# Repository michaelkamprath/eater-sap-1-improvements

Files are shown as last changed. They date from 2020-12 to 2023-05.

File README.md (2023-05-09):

Stand With Ukraine (https://stand-with-ukraine.pp.ua)

# Eater SAP-1 Improvements
Ben Eater released [a YouTube video series](https://eater.net/8bit) that works you through the process of building a simple 8-bit computer on a breadboard made with simple logic gates. It's a great learning experience if you are so interested.

Captured in this repository are various projects that extend and improve on the original SAP-1. The goal of these project is to build upon and reinforce what was learned with Ben Eater's original series.

Note that I've made a video explaining most of these projects. The video series [can be found here](https://www.youtube.com/playlist?list=PLC4jDTViU38EQzCYaRsoOLeGLLW5cMN4A).

# Projects
Multiple independent projects are described in this repository. It is recommended that you do them in the following order:

1. **[Halt system clock when programming](./clock-halt-when-programming/)** - Fixes the annoying issue that the SAP-1's microcode counter continues iterating when in program mode.
2. **[Making the 16 Byte RAM Module more reliable](./improving-reliability-of-ram-module/)** - Ben Eater's original design for the RAM module has two issues that cause the bread board computer to be unreliable. This project fixes those problems.
3. ~~**[Expanding the SAP-1 Control Logic](./expanded-control-logic/)**~~ - **It is recommended that this project be skipped in instead implement the control lines expansion describe in the Instruction Register project below**. The original SAP-1 can control at most 16 control lines in the computer. This project add more control lines that and sets the SAP-1 up for other future expansions.
4. **[Adding Two General Purpose Increment Registers to the SAP-1](./increment-registers/)** - This project adds to the SAP-1 two general purpose registers that have the ability to increment or decrement the value they contain.
5. **[Calculating Factorial](./calculating-factorial/)** - This project builds on everything done up to this point to enable the SAP-1 to calculating the _n!_ math algorithm.
6. ~~**[Adding 64K of RAM and ROM](./ram-rom-upgrade/)**~~ - **It is recommended that this project be partially skipped. The program counter, memory address register, and run mode selector from this project should be completed, but is recommended to skip the rest and implement the 16 bit memory architecture describe in the Instruction Register project below**. This project changes the SAP-1's memory address space to 16 bit, and then splits the address space between ROM and RAM. The original 4-bit instructions are still maintained, as that will be changed in a later project. This project also introduces an assembler to help build the ROM code.
7. **[Instruction Register and Memory Map Update](./instruction-register-8-bit/)** - In this project I upgrade the instruction register to use the full 8-bits. I also realized that I once again needed to upgrade my control logic, so I expanded the instruction-based control logic plus added a memory map mechanism.
8. **[Stack Pointer and Index Register](./stack-pointer/)** - A stack pointer is added to enable things like subroutines and stack memory. Also adds an index register that can be used to track 16-bit values and memory addresses.
9. **[LCD Display](./lcd-display/)** - A 20x4 LCD character display is added to give the TTL CPU the ability to display more complex output to the user than is afforded by the original 8-bit display of the SAP-1.
10. **[Advanced Arithmetic Logic Unit](./advanced-alu/)** - Adds an ALU that is more capable than just addition operations. In addition to addition  subtraction, enables bit shifting, logic operations, comparisons, and bit detection. Plus, allows reading the flags register directly.
11. **[Writable Flags Register](./bidirectional-flags-register/)** - Corrects a design oversight from the Advanced ALU design by allowing the Flags register to be written to from the data bus.

# Future Projects
The following projects are planned but have not been designed yet, however, I have put sufficient thought into them or have seen other attempt them to be convinced that they are viable:
* Adding a 8x8 LED pixel display
* Interfacing with the TMS9918a video processor (?)
* Interfacing with a 80's tech sound chip

# Interesting SAP-1 Links

* [SAP-1 Simulator](https://github.com/milen-patel/SAP-1)
* [Ben Eater Reddit forum](https://www.reddit.com/r/beneater/)

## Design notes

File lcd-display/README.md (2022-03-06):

# LCD Display Module
## Overview
As I iterate on the PUTEY-1 to expand its capabilities, the original 1-byte display of the Ben Eater SAP-1 just won't cut it anymore for my display needs. If I want to achieve 64-bit math on this computer, I will need a a way to display values greater than 8-bits. While eventually I do want to connect an 80's style video display processor to this computer, such as the [TMS9918A](https://en.wikipedia.org/wiki/Texas_Instruments_TMS9918), I felt the first step here would be to attach to the CPU one of those ubiquitous LCD displays based on [the Hitachi HD44780 controller](https://en.wikipedia.org/wiki/Hitachi_HD44780_LCD_controller). 

The work I did in a previous project to add memory mapped IO to the CPU really made this project pretty straight forward. There ended up being some gotchas around stability, which I discuss below, but from design to implementation, this was a pretty simple project. More work was put into designing the demonstration software than creating the hardware. But I am pretty happy with the results.

# Design

## LCD Module

### Overview
The LCD module I went with is the LCD2004 module with 4 rows of 20 characters. [These are pretty cheap on eBay](https://ebay.us/opX5g1). You will find many different manufacturers of these modules, but their electrical characteristics are all the same (if they are using the Hitachi HD44780 controller). Your biggest choices are price and color. 

The data sheets for these modules highlight the standard pin connections to the modules, which I list here:

| Pin | Symbol | Description |
|:-:|:-:|:--|
| 1 | `VSS` | **Ground** - Power supply for the device logic. |
| 2 | `VDD` | **+5V** - Power supply for the device logic. |
| 3 | `V0` | **Voltage Reference** - used to adjust LCD brightness. |
| 4 | `RS` | **Register Select** - controls whether the data register (`HIGH`) or the instruction register (`LOW`) is being communicated with.|
| 5 | `R/W` | **Read/Write** - controls whether the device is accepting input (write mode `LOW`) and sending output (read mode `HIGH`) |
| 6 | `E` | **Enable** - In write mode the module will latch the contents of the data lines on the falling edge of this line. In read mode the module will present data to be read on the rising edge of this line. |
| 7 | `DB0` | **Data Bus 0** |
| 8 | `DB1` | **Data Bus 1** |
| 9 | `DB2` | **Data Bus 2** |
| 10 | `DB3` | **Data Bus 3** |
| 11 | `DB4` | **Data Bus 4** |
| 12 | `DB5` | **Data Bus 5** |
| 13 | `DB6` | **Data Bus 6** |
| 14 | `DB7` | **Data Bus 7** |
| 15 | `LED+` | **+5V** - Power supply for the backlight. |
| 16 | `LED-` | **Ground** - Power supply for the backlight. |

### Interfacing with the LCD Module
The register select `RS` line into the LCD module controls whether we are interacting with the command or data register of the module. Prior to me implementing the memory mapped IO controller, the answer here might have been to create a new control line that would be controlled via microcode. That, of course, is an approach that doesn't scale where and the reason why I added [the memory mapped IO controller](../instruction-register-8-bit#memory-map). The basic idea is that we will use a memory mapped IO controller control line, `MMAP_x`, in combination with the lowest address lines to determine which device and register of that device is actively being used. In the case of the LCD module, I decided to assign it to the `MMAP_1` memory map control line and use address line `A0` to control the `RS` line directly. The `MMAP_1` control line is active for addresses between `0x7810` and `0x781F`. By connecting `A0` to `RS`, that means even addresses in that range will cause `RS` to be `LOW` and thus we would be interacting with the instruction register, and odd addresses would activate the data register. For simplicity, I just declare the address `0x7810` to be the instruction register, and `0x7811` is the data register. 

The `R/W` line of the LCD module is controlled by both the `MDi` (memory device in) and `MDo` (memory device out) control lines. When `MDi` is `HIGH` and `MMAP_1` is active, we want `R/W` to indicate that the device will be written to, or set `LOW`. And when `MDo` is `HIGH`, we want `R/W` to be set high. Furthermore, in order to prevent spurious data changes, I wanted to hold `R/W` in read mode whenever `MMAP_1` or both `MDi` and `MDo` are not active. This way any stray pulse into the device on another control line won't cause an unwanted write. To accomplish this, I introduced some logic to the design, which can be reviewed in the schematic.

The biggest challenge in using this module is dealing with the enable `E` behavior of acting on the falling edge of the clock for writes and the rising edge of the clock for reads. This would imply that we need an inverted clock driving the `E` signal, but care had to be taken in the design to deliver both edges *after* all the other control lines were configured. Since the other control lines would be driven by the memory map IO logic, there is relatively significant gate delay before the `RS` and `R/W` signals arrive. To account for this, I gate the inverted clock sign with the logical combination of `MMAP_1 AND (MDi OR MDo)`, which will allow the clock to pass only if both the memory map IO controller has activated the LCD module and the is either a memory write or read operation happening. After that gate, I pass the clock signal through a double inverter to delay it a bit more to ensure these is some time in between when the LCD module is configured and when it sees a rising edge on `E`. I also found in practice the Hitachi HD44780 is extremely sensitive to noise on the `E` line. I discuss noise mitigation later in this document.

Since the LCD module's data lines, `DB0` through `DB7`, can both read and write data, they cannot be connected to the CPU's data bus directly. An connection is needed that will architrave when the device is in read more and write mode in order to prevent contention on the bus. This is where the oft-used `74LS245` octal bus transceiver ready shines. It has the `DIR` line (pin 1) which controls the direction of the transceiver's signal repeating. Here, the `MDo` control line is used to drive the direction of the transceiver. Furthermore, the transceiver is only made active (chip enable line) when both the `MMAP_1` line and either of the `MDo` or the `MDi` line is active.

## Software Support
### Implementing a Vertical Scroll
The LCD2004 module is pretty rudimentary and its only "convenience" function is auto-incrementing the its active memory address when it is read or written to. So to write the contents of a particular row on the device you just have to set its data address to the row's start position and then bang out each o the row's character's in order. However, if you want to do something more sophisticated, such as creating a vertically scrolling display, you have to implement it in software.

So I did desire a vertically scrolling display. What I wanted for an interface is to simply give the module a line of text, and it would automatically display it on the bottom row after scrolling the existing rows upward. It is conceptually pretty straight forward to scroll, just read the contents of one from for the LCD module, and then write those contents to the line above. In practice, I found this to be slow given all the instructions that are needed to set the read and write address of the LCD module for moving the data around. This is actually not an uncommon problem with displays in general.

One way to improve the permanence of managing what is being displayed on a display is to buffer the display data in RAM, do any manipulations you want to do with the display data there in RAM (which is usually much faster than interacting with the display), and then when ready, simply blast the RAM display data into the the display module. This "download display data to the module" activity is usually optimized for speed in display modules, and this LCD2004 module is no different. 

Once I have the display module's display contents in RAM, effecting a fast vertical scroll becomes much easier. The method I used was to first create a single block of RAM that represents all of the specific character data positions on the display. The first position in this RAM block would represent the first position (left most) on the first (top) row, and the last position in this RAM block would be the last position (rightmost) on the last (bottom) row. Then, I additionally create four pointer variables in RAM that each have the address to the start of their specific row in the display data in RAM. This can be visualized like this:

```

                     0      Columns     19
                    +--------------------+
  row 0 pointer --> |                    |
                    +--------------------+ R
  row 1 pointer --> |                    | o
                    +--------------------+ w
  row 2 pointer --> |                    | s
                    +--------------------+
  row 3 pointer --> |                    |
                    +--------------------+
                                        79

```

When I want to updated the contents of a row, I simply write into the RAM block starting at the memory address contained by the pointer variable to that row. Then when I need to update the contents of a row on the LCD module, I set the LCD module's data address to its address for that particular row, then send it 20 characters from the RAM block starting at the address contained by the pointer variable for that row. 

Effecting a fast scroll then becomes pretty simple. I first rotate the pointers variables. That is, the row 0 pointer assigned the address that is currently in the row 1 pointer, the row 1 pointer gets the row 2 pointer value, the row 2 pointers gets row 3 pointer value, and and row 3 pointer gets the original value of the row 0 pointer. Then I write the new string data that I want to display to the updated memory location in the row 3 pointer. The updated pointer configuration after the first scroll would look like this relative to the buffer RAM block:

```

                     0      Columns     19
                    +--------------------+
  row 3 pointer --> |                    |
                    +--------------------+ R
  row 0 pointer --> |                    | o
                    +--------------------+ w
  row 1 pointer --> |                    | s
                    +--------------------+
  row 2 pointer --> |                    |
                    +--------------------+
                                        79

```
At this point, the LCD module display can be quickly updated by blasting the entire buffer contents into the LCD module one row at a time starting at the address of the updated row 0 pointer and then working through each subsequent row in turn. 

The advantage of this approach is that you have to move less data around to effect the vertical scroll. Since the LCD module does not support a hardware scroll, you can't get around needing to completely update the LCD module's RAM content. However, this row pointer approach allows you to effectively rearrange the buffer's row arrangement without needing to read and rewrite the contents of the buffer. 

### Standard Libraries
With the addition of a stack pointer in my last update, and the addition of the LCD module in this update, its time to start implementing a standard suite of functions for use to build software for the PUTEY-1 TTL CPU. With this project, I created the start of the following libraries:

* `memlib` : **Memory Library** - Provides some utilities around managing emory, notably copying data from one area in ROM or RAM to another.
* `stringlib` : **String Library** - Provides functions for the manipulation of strings, notably determining their length, concatenating two strings, and converting numeric values to a string for display. This library primarily uses null-terminated strings, also known as C-style strings. 
* `mathlib` : **Math Library** - Provides functions for calculating math at high bit sizes than the 8-bit math the the ALU supports. Currently provides an addition, subtraction, multiplication, and division function for 16-bit math.
* `lcdlib` : **LCD Display Library** - Provides all the of the functions needed to display text and special characters on the LCD2004 module.

The current version of these libraries can be found in [the examples folder](./examples/) of this project. These libraries can be used in the code independently, or all can be imported by [including](https://github.com/michaelkamprath/bespokeasm/wiki/Assembly-Language-Syntax#include-other-files) the `system.asm` file in your program's code.

## Increasing Maximum Clock Speed
At the start of this project, I was still using the original clock design from [Ben Eater's SAP-1](https://eater.net/8bit). As it was designed the maximum speed of the clock is 481 Hz. Certainly that is faster than what you eye can see, but it proved to be pretty slow with all the work that needs to happen to maintain the LCD display. A quick fix here was to change the capacitor that controls the timing of the astable `555`. In Ben Eater's original design, this capacitor was 1 µF. I changed it to a 100 nF capacity and got a 10x increase in the maximum speed of the clock, to 4.8 KHz. This made the display of text and scrolling on the LCD module much more snappy.

## Stability Issues
While the basic concept of adding this LCD module to the breadboard CPU are pretty straightforward, there is a rather significant stability issues I had to solve. The issue was a combination of the LCD Module's enable line being sensitive to triggering on the falling and and general signal integrity issues caused by the growing size of my breadboard CPU. Basically, noise in both the `CLK` and `MDi` lines would separately have noisy (enough) transitions between `LOW` and `HIGH` that the LCD module would see multiple falling edges. This noise is caused by the inductance of long wires in my large breadboard layout. In the case of `MDi`, I route it through the power rail bus in the middle of the breadboard layout along side the data bus. That's nearly a half meter of breadboard power rail. The falling edge of the `MDi` signal had a very distinct "second hump" as current from the collapsing magnetic field around the `MDi` bus rails created a second voltage spike.  The LCD module would see this as a second trigger when reading in data. 

To address the noise on the `MDi` trailing edge, I simply placed a 1 nF capacity between the `MDi` bus rail (where most the inductance is) and ground. This create a small [LC circuit](https://en.wikipedia.org/wiki/LC_circuit) based on the inductance (`L`) of the bus rail and capacitance (`C`) of the added capacitor. Th `LC` circuit smooths out the transition from `HIGH` to `LOW` (and vice versa) in the `MDi` line, but it does have the effect of lengthening the transition time. I measured the transition with an oscilloscope and found it now takes about 140 nanoseconds. This means that my breadboard computer now has a maximum frequency of about 7 MHz. I'm currently running PUTEY-1 at about 4 KHz, so I find that margin acceptable. I also found I needed to add a 1 pF capacitor to the `MDo` control line for all the same reasons. 

A similar problem was found in the `MMAP_1` memory map control line. A limitted investigation leads me to suspect the `74HCT238` creates a spurious signal spike as its address lines transition. This this spike was small, the LCD module would detect and act on it. I found that placing a 22 pF capacitor between the `MMAP_1` line and ground dampened the spike enough to not be detected by the LCD module.

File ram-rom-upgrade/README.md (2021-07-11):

# 16 Bit Memory Expansion for SAP-1
## Overview
When doing [my last project](../calculating-factorial/) with my Ben Eater inspired breadboard TTL CPU, one thing that became obvious is that 16 bytes was a rather small amount of RAM. If I wanted to continue my learning journey that only started when I finished the [Ben Eater SAP-1 project](https://eater.net/8bit), I needed to expand the available memory to my breadboard CPU. Furthermore, needing to manually key in a program each time I power cycle the breadboard CPU got old rather quick. So, before I go any further with expanding the breadboard TTL CPU, I need to address these two issues.

Something that surprised me in the effort to expand the RAM of the breadboard computer was the realization that I had a large number of choices and that each choice would have implications on what I could do later down the road. I idea I immediately seized on was to go with 12 bit addressing, effectively using the lower 4 bits of the instruction codes for the top 4 bits of an address, and then use the next byte after that for the lower 8 bits of the address. This appeared to be the most minimal departure from Ben Eater's original design, but it had the issue that I'd still be bound by 4 bit instruction codes. 

Then the debate was should I expand the instruction code bits to 6, and then use 10 bit addressing. This would get me 1K of RAM, which for the learning purposes of the breadboard CPU, seemed sufficient. However, the issues here is that 10 bits would just be an awkward size when it comes to the program counter, memory address register, and so on. 

So, I just bit the bullet and decided to go with full 16 bit memory addressing. Selecting this choice leads to some necessities in the design, specifically the creation of an address bus and defining how that will behave, but that was all OK because it forced me to really think about the design, which in the end is the goal of this project anyway: learning by doing. 

### Design Goals

* The memory space should use 16 bit addressing
* Have both ROM and RAM in the memory address space.
  * ROM would be used for a boot-loader, common subroutines, and programs
  * 32K of ROM and 32K of RAM. The ROM will be `0x0000` though `0x7FFF`, and the RAM will be at `0x8000` through `0xFFFF`.
* Both the program counter and memory address register should be 16 bit registers.
* Like the program counter, The memory address register should enable being incremented in order to quickly get the next location in memory. 
  * This feature is actually needed due to memory address values now occupying two bytes, and we want our instruction parameters to just point at the first byte.
 * This would be controlled by microcode.
* For multi-byte values in RAM, such as memory addresses and 16-bit integers, the values will be arranged as little endian.
  * This makes implementing multi-byte math so much easier later on. It does make data entry a little less intuitive. 
  * The program counter and memory address register will be physically arranged as big endian to make the LEDs used to represent their values more human interpretable.
* Implement an assembler similar to [the `customasm` tool](https://github.com/hlorenzi/customasm).
  * This is done to make creating the ROM images easier. 
* Smaller clock footprint
  * This project a larger than normal breadboard footprint. In order to save save, the clock module is made smaller by using a LM556 dual timer chip in replacement to two LM555 timers.  
  * Also, the sense of the `PROG` signal is changed to a HIGH indicating that the computer should be in manual program mode. This requires a small change to the [Halt system clock when programming](../clock-halt-when-programming/) project.

Not in scope for this project:

* While expanding the RAM and how it is addressed is the necessary prerequisite to allowing the instruction register use more than 4 bits for instruction codes, this project will not accomplish instruction register expansion. 

## Design Approach

### RAM and ROM
With a 16 bit address space, the computer will be able to address a total of 64K of memory. There are many ways to allocate the memory space's usage. Here, we are going to simply evenly split the memory space between ROM and RAM, with the ROM being in the lower 32K of the address space. Both the ROM and RAM could be used for program code, with the ROM code being burned onto the ROM and the RAM code being manually entered via DIP switches. Since only RAM will be mutable at run time, all variables for any cod should be in the RAM address space even if the program code is in ROM. 

A simple visualization of memory space is as follows:

```
    0xFFFF  +-----+
            |     |
            | RAM | <-- Variables, programs
            |     |
    0x8000  +-----+
            |     |
            | ROM | <-- Boot code, programs
            |     |
    0x0000  +-----+

```

To implement this, a 28C256 EEPROM will be used for the ROM and a UM61512AK-15 will be used for RAM. In order to select whether the RAM or ROM is active, address line 16 (the MSB) will be routed to each chip's enable rather than an address input on the chip. Fortunately, the 28C256 chip enable is active low and the UM61512AK-15 chip enable is active high, thus making it very straightforward as to which chip should be active based on the MSB of the address. 

One design challenge that had to be overcome is that the UM61512AK-15 uses the same pin for both data input and data output. This creates the potential for bus contention if the RAM is outputting a value at the moment a value is read in from the data bus. Bus contention could also occur if the 74LS157 2-to-2 multiplexers are used to switch between input from the DIP switches and input from the data bus. The reason for this is that when inactive, the 74LS157's output pins are set to LOW. This creates a short circuit if the RAM or ROM chip are writing a HIGH to any data line. In order to address these issues, 74LS257 2-to-1 multiplexers are used instead, as these chips have a tri-state output and places the output lines to high impedance if the chip is set to inactive. Then, logic is added to ensure that the 74LS257s are only active when the RAM chip is reading from the data lines. Otherwise, the 74LS257s will be set inactive so bus contention does not develop when either the RAM or ROM are writing to the data lines.

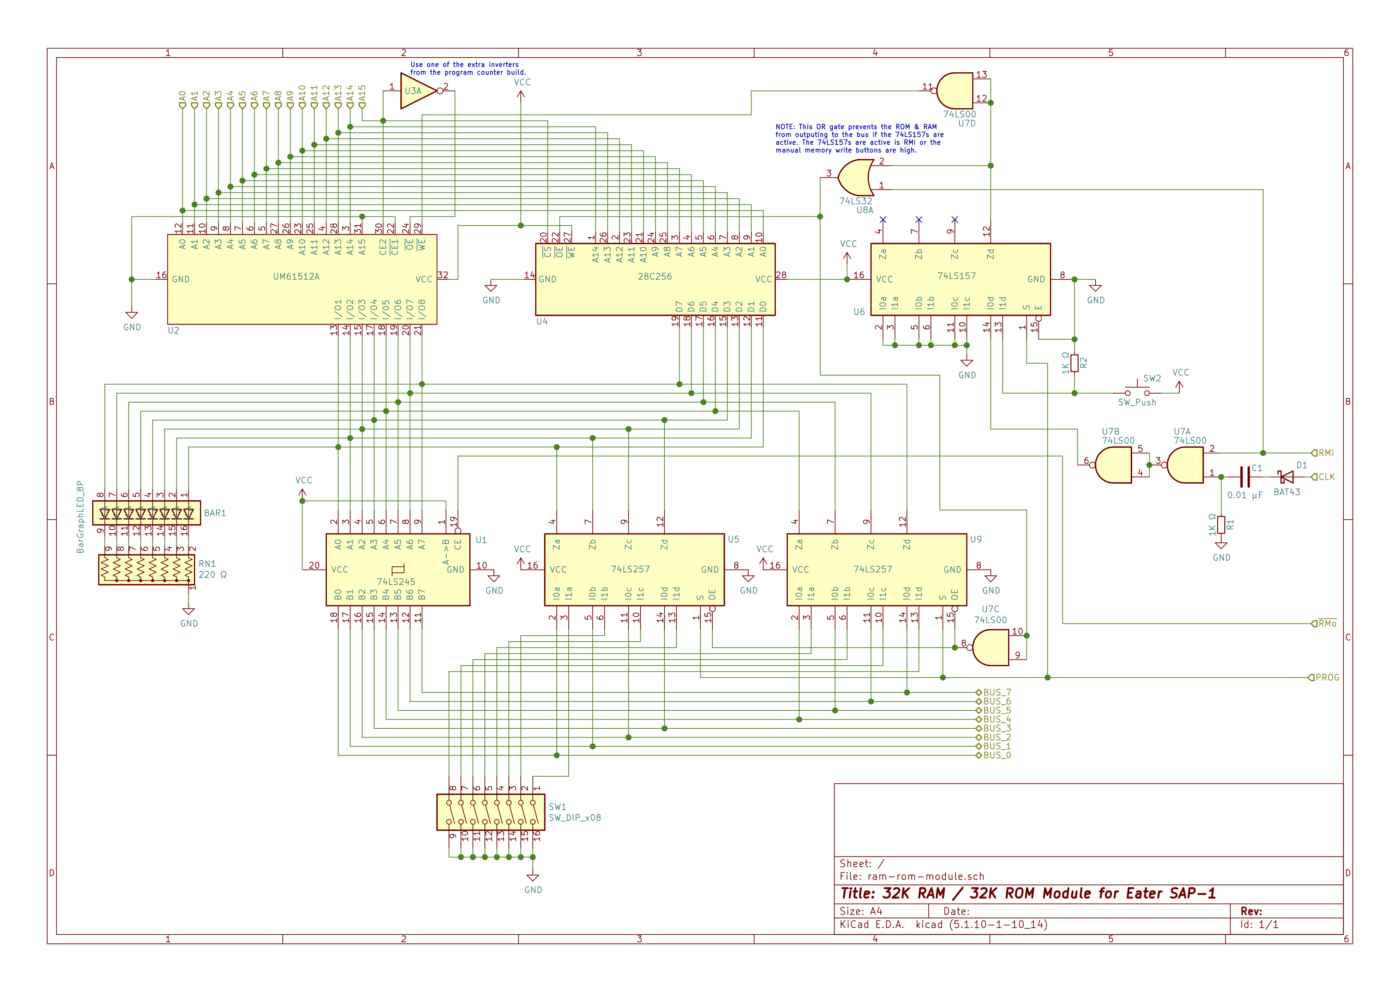
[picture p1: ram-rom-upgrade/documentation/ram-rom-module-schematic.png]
16-bit RAM/ROM Module


### Program Counter
Since this memory module has a 16 bit address space and I wish to make all of it available to code, the program counter itself needs to be a 16 bit counter. This is accomplished by using four 74LS161 4-bit counters. The design is similar to the original Eater SAP-1 program counter, but with four counters rather than one.

Another difference is in how the program counter reads in data from the data bus for the purpose of jump instructions. Since the program counter is 16 bit and the data bus is 8 bit, setting the program counter value from the data bus requires two read operations. To signal this, a `PCi` signal is used to indicate that the program counter should read in from the bus, and a `HILO` signal is used to indicate whether the bus value should be placed into the high byte or low byte of the program counter. The `HILO` signal is in fact reused through out the breadboard computer's design to generally indicate whether the operation pertains to the high or low byte of a 16-bit word. 

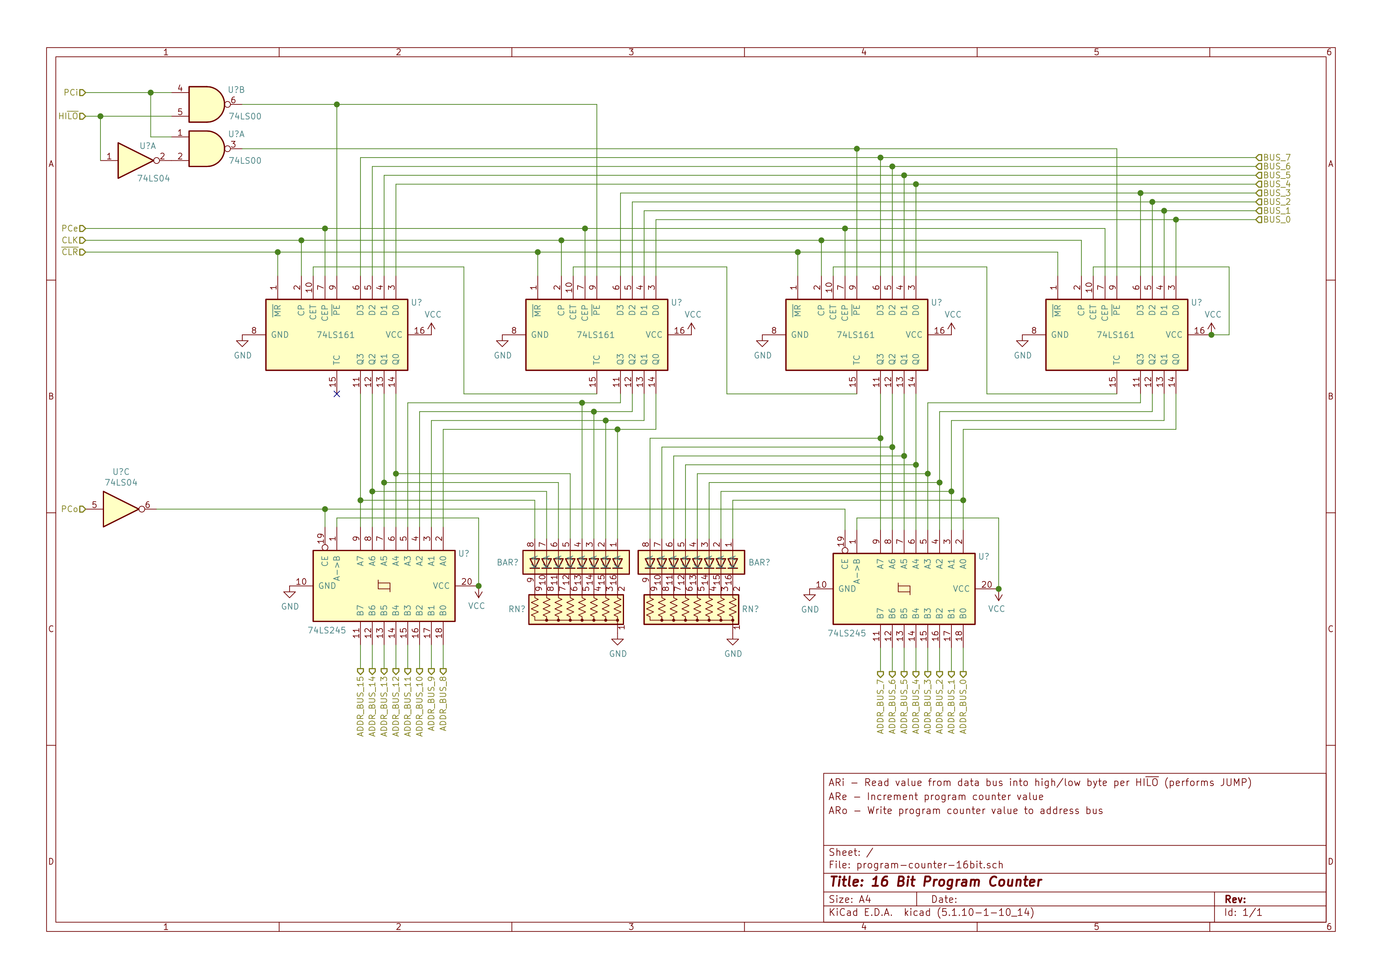
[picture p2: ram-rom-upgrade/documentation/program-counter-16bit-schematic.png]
16-bit Program Counter


### Memory Address Register
In this design, the memory address register is used to load address values from the data bus and then use them to indicate what address in memory should be read. Now that memory addresses themselves are multi-byte values, it is expected that we will increasingly want to read multiple consecutive bytes of data from memory. Given that, it would be convenient if the memory address register could increment itself rather than requiring an ALU operating simply to add 1 to the current memory address. to accomplish that, the memory address used 74LS161 4-bit counters similar to the program counter. In fact, the general design of the memory address register and the program counter are identical. 

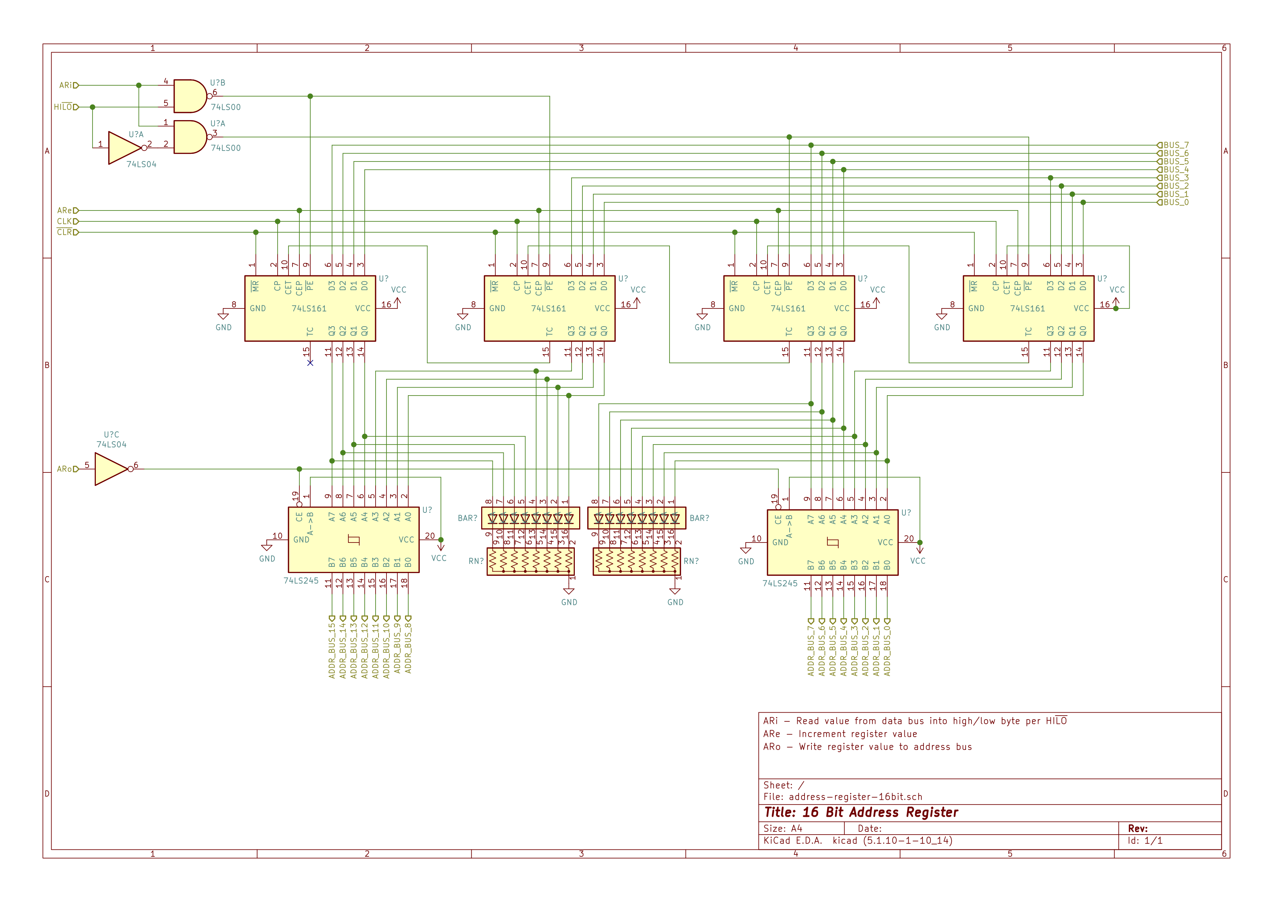
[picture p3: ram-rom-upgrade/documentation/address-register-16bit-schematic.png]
16-bit Memory Address Register


### Address Bus

In the original Eater SAP-1 design, the memory address register is the interface for anything that wants to fetch a value from memory. The program counter could set the memory address register, and so could the instruction register. All of this was done through the data bus. However, in a 16 bit address space with a 8 bit address bus, this design is problematic. 

The nature of the problem is due to memory addresses now requiring two bytes. Consider the `LDA` instruction. With a 16 bit address, the `LDA` instruction will be represented in 3 bytes. The first byte is the instruction code, and the next two bytes are the memory address of the value that should be loaded into register A. The problem arises in that loading the address into the memory address register is a two step operation. The following steps for the `LDA` instruction illustrates the problem:

1. The program counter points at the instruction code for the `LDA` instruction. This address is loaded into the memory address register, and then the memory value is loaded into the instruction register.
2. The program counter is incremented to now point at the first byte of the address of the value to be loaded into register A. This address is loaded into the memory address register, and the first byte of the value address is written onto the data bus and back into the low byte of the memory address register (remember, we are using a little endian design). 
3. The program counter is incremented again to point at the second byte of the address of the value to be loaded into register A. However, if we write this address to the memory address register to be able to fetch the value, it would overwrite the first byte of this value's address that was placed in the memory address register in step 2.  

Therein lies the problem of continuing with the SAP-1 of the memory address register being the only entity that can set the address that memory will fetch from. To solve this problem, we introduce an address bus concept to the design. The basic approach to this design is that multiple entities can write to the address bus, but only one at a time. The memory will fetch the value at whatever address is currently being written to the address bus, and then write that value to the data bus. This means that both the program counter and memory address register can both write to the address bus, but obviously they should not do so at the same time. 74LS245 bus transceivers are used to arbitrate which register is writing to the address bus. 

Added to the address bus design is a way to output the address bus value to the data bus. This feature would enable performing arithmetic on the address value beyond the simple increments that the program counter and the memory address register currently enable. 

Finally the address bus's connection to the address lines of the memory ICs is arbitrated by a set of 74LS157 2-to-1 multiplexers. This design enables a run mode switch, which indicates whether the memory address should be read from the address bus or a set of microswitches that are used when manually keying memory values. 

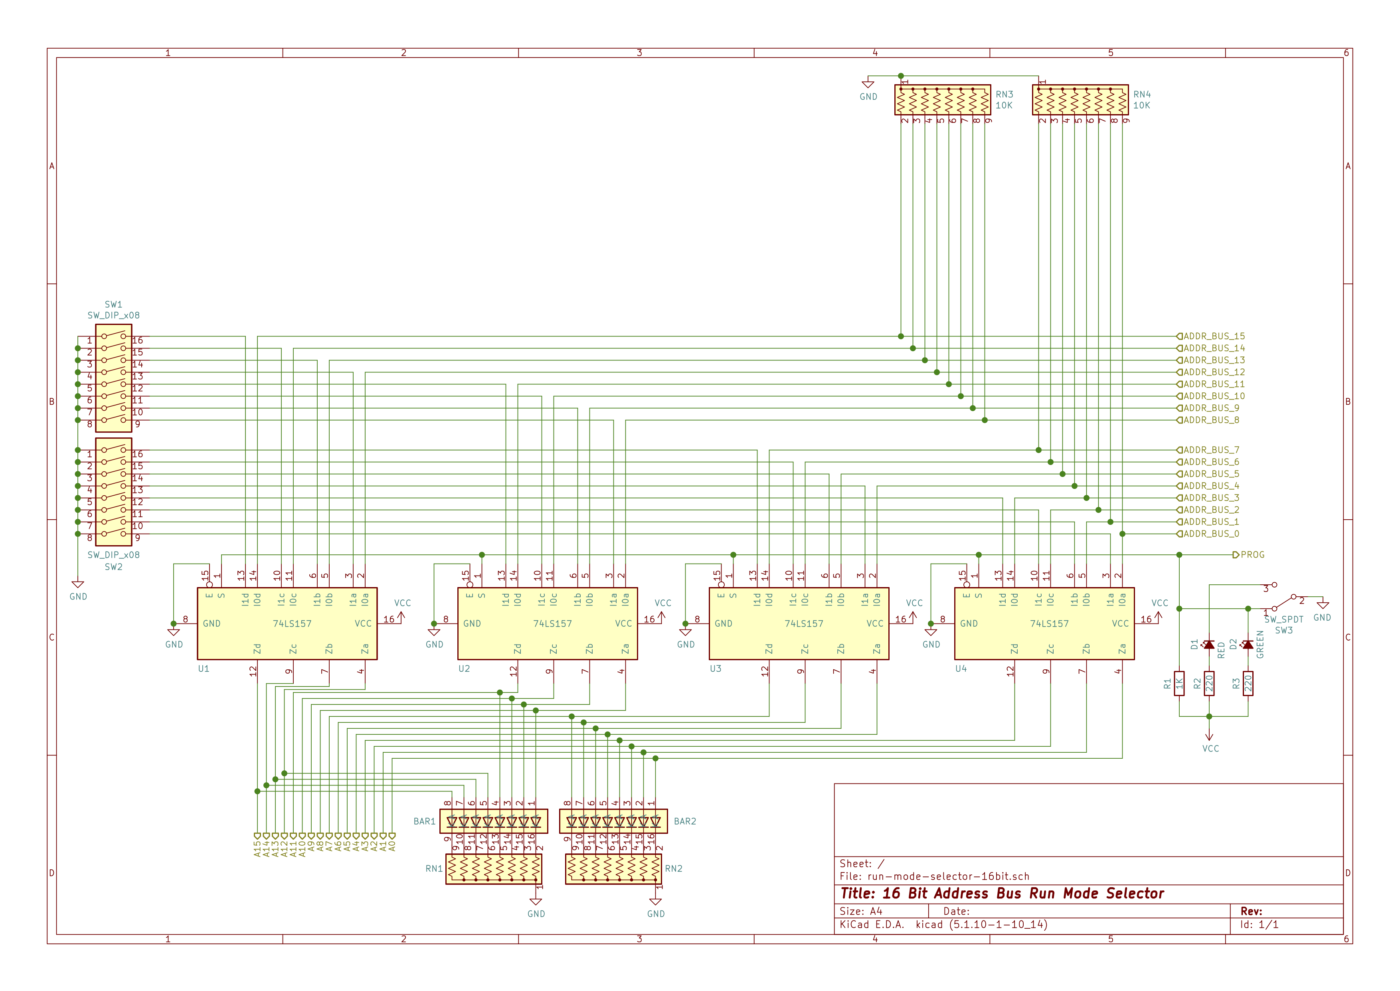
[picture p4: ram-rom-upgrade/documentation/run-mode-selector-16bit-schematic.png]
Run Mode Selector


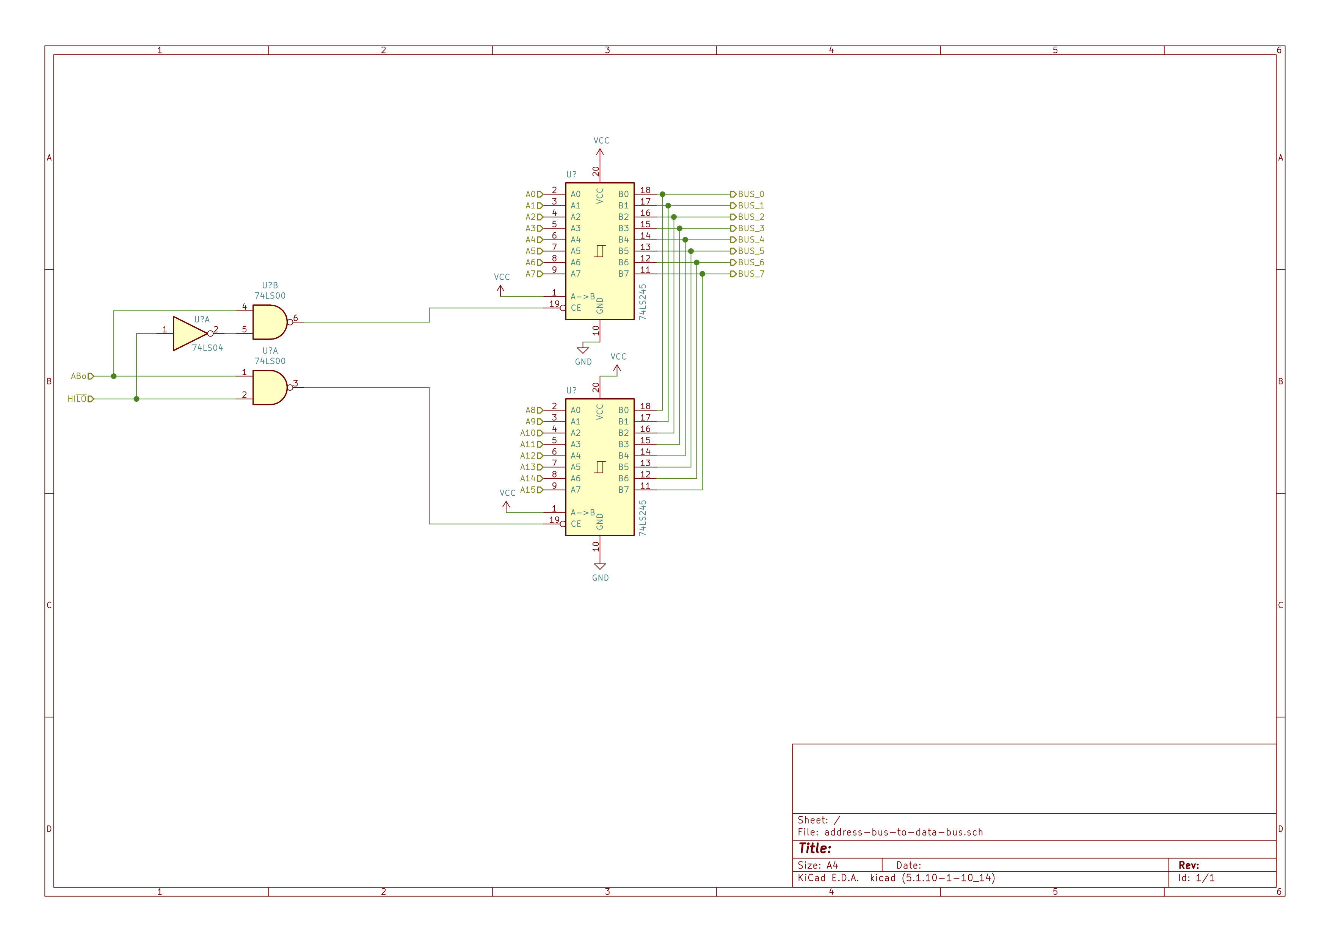
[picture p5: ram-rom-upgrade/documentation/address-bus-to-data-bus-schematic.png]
Address Bus to Data Bus


### Compact System Clock
Purely for layout reasons, the system clock was redesigned to slightly reduce chip count and in turn fit within a smaller footprint on the breadboard. This was done because the combination of the memory module, program counter, and memory address register require much more breadboard footprint than the previous RAM design did. Instead of using three 555 timers, the system clock now uses one 555 timer and one 556 dual timer. Other than that, the clock design is functionally the same. 

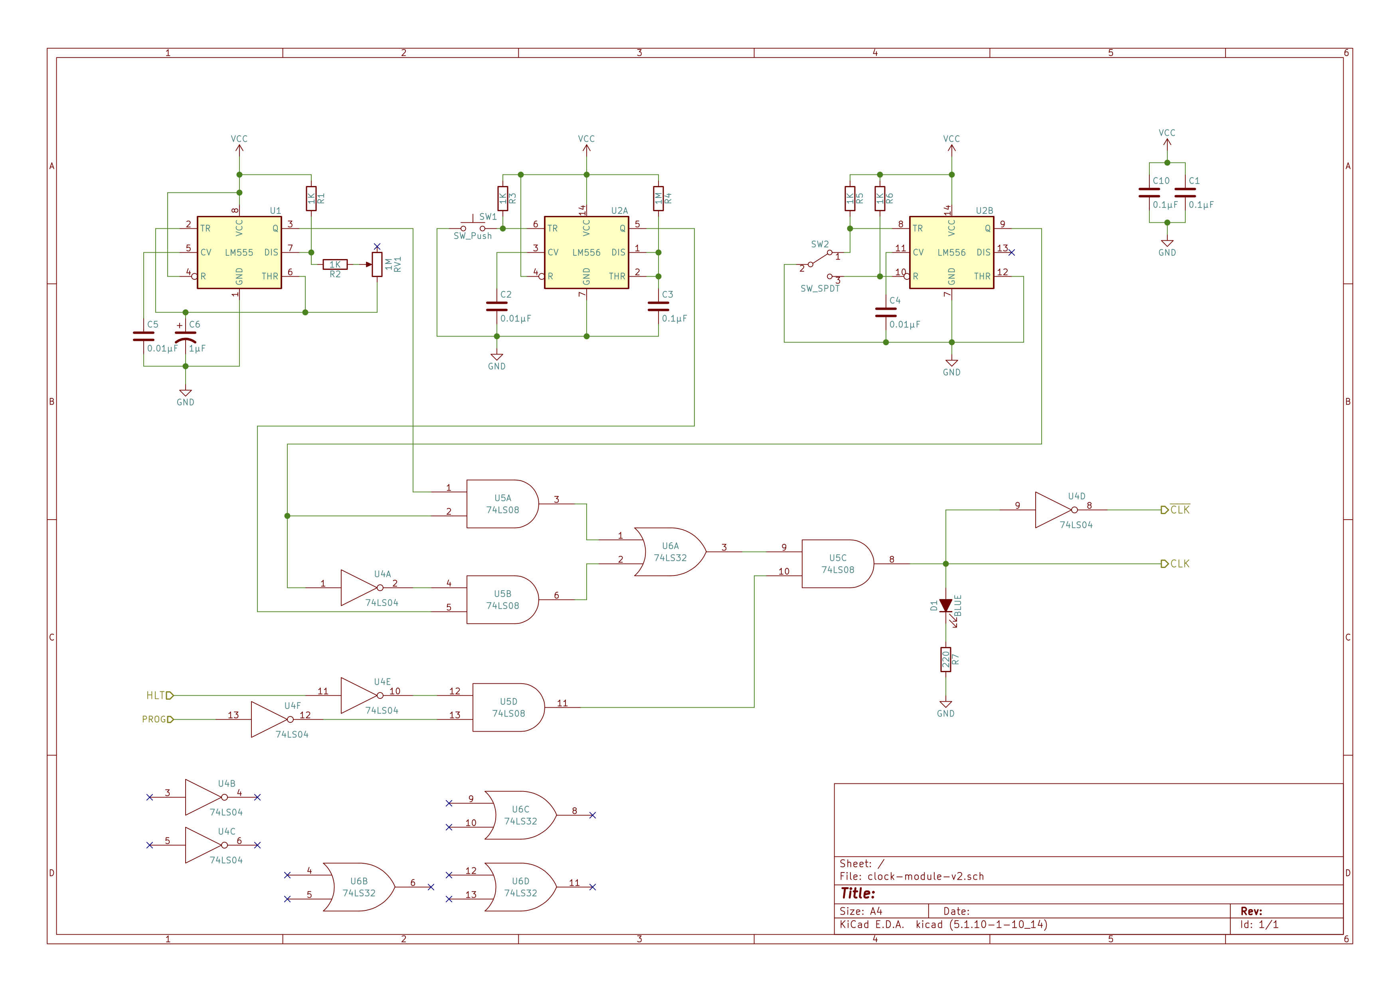
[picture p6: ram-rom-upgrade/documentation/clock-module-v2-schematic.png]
Compact Clock Module


## Component Data sheets

* [UM61512AK-15](./datasheets/UM61512A.pdf) - 64 K x 8 bit SRAM. Any 32K or larger SRAM chip could be used for this project with minimal modifications. 
* [AT28C256](https://www.mouser.com/datasheet/2/268/doc0006-1108095.pdf) - 32K x 8 bit EEPROM. Any 32K or larger EPROM could be used with minimal modification to the wiring. EEPROMs are convenient for reprogramming, which we will likely do often.
* [74LS161](https://www.ti.com/lit/ds/symlink/sn54ls161a-sp.pdf) - A 4-bit counter
* [74LS245](https://www.ti.com/lit/ds/symlink/sn54ls245-sp.pdf) - Octal Bus Transceivers With 3-State Outputs
* [74LS00](https://www.ti.com/lit/ds/symlink/sn74ls00.pdf) - Quadruple 2-Input NAND Gates
* [74LS04](https://www.ti.com/lit/ds/symlink/sn74ls04.pdf) - Hex Inverters
* [74LS32](https://www.ti.com/lit/ds/symlink/sn74ls32.pdf) - Quadruple 2-input OR gates
* [74LS157](https://www.ti.com/lit/ds/symlink/sn74ls157.pdf) - Quadruple 2-to-1 Line Data Selector/Multiplexer
* [74LS257](https://www.ti.com/lit/ds/symlink/sn74ls257b.pdf) - Quadruple 2-to-1 Line Data Selector/Multiplexer with Tristate Output
* [555](https://www.ti.com/lit/ds/symlink/lm555.pdf) - LM555 Timer
* [556](https://www.jameco.com/Jameco/Products/ProdDS/24328.pdf) - LM556 Dual Timer

## Integration with Breadboard Computer

### Breadboard Layout

### Connecting to Control Logic
At this point in the breadboard CPU's evolution away from the original Eater SAP-1 design, the following control lines are in use. Some control lines are marked as **New** or **Updated** in comparison to the previous [Increment Registers](../increment-registers/) project.

| Symbol | Title | Description |
|:-:|:--|:--|
| `SCr` | Step Counter Reset | Resets the microcode step counter to zero. |
| `PCe` | Program Counter Enable | Increments the current value in the Program Counter |
| `SUB` | Subtract | Signals that math operations should be subtraction |
|`HILO` | High/Low Byte Selector | Controls which byte of a 16 bit register is being operated on when interacting with 8-bit data bus. **New** |
| `HLT` | Halt | Stops the system clock. |
| `OUT` | Output Data Bus | Writes data bus value to the display register |
| `Ie` | I-Register Enable | Increments the value in the I register, or decrements is `SUB` is set |
| `Je` | J-Register Enable | Increments the value in the J register, or decrements is `SUB` is set |
| `ARe` | Address Register Enable | Increments the current value in the Address Register. **New**|
| `PCi` | Program Counter In | Renamed `J` control line, which sets the program counter to the data bus value. Used in conjunction with `HILO`. **Updated** |
| `∑f` | ALU Flags | Load flags register with current flags from ALU |
| `If` | I Register Flags | Load flags register with current flags from I register |
| `Jf` | J Register Flags | Load flags register with current flags from J register |
| `RMi` | RAM Value In | Loads into RAM at the current memory address the current data bus value. No action of current memory address points to ROM. |
| `IRi` | Instruction Register In | Loads into the instruction register the current data bus value. |
| `Ai` | A Register In | Loads into the A register the current data bus value. |
| `Bi` | B Register In | Loads into the B register the current data bus value. |
| `Ii` | I Register In | Loads into the I register the current data bus value. |
| `Ji` | J Register In | Loads into the J register the current data bus value. |
| `ARi` | Address Register In | Loads into the address register the current data bus value. Used in conjunction with `HILO`. **Updated** |
| `PCa` | Program Counter to Address Bus | Writes the current program counter value to the address bus. This replaces the original `PCo` control line which wrote the program counter value to the data bus. **New** |
| `∑o` | ALU Out | Writes to the data bus the current ALU results value |
| `ARa` | Address Register to Address Bus | Writes the current address register value to the address bus. **New** |
| `ABo` | Address Bus Out | Writes to the data bus the current value being written to the address bus. Used in conjunction with the `HILO` control line.  **New** |
| `RMo` | RAM Value Out | Writes to the data bus the memory value at the current memory address. |
| `IRo` | Instruction Register Out | Writes to the data bus the lower bits of the instruction register that are not part of the instruction. |
| `Ao` | A Register Out | Writes to the data bus the current value in the A register. |
| `Bo` | B Register Out | Writes to the data bus the current value in the B register. |
| `Io` | I Register Out | Writes to the data bus the current value in the I register. |
| `Jo` | J Register Out | Writes to the data bus the current value in the J register. |

### Control Logic Microcode
The big challenge in developing the microcode for the this project is the fact that the memory addresses are now 16 bits. Since we are not upgrading the instruction register in this project, the instruction is still 4 bits, but a 16 bit address can't fit in the bottom 4 bits of the instruction byte (obviously), so now we are in the world of multibyte instructions. Furthermore, it will take more than one instruction step to move the 16 bit address through the 8 bit data bus. 

When figuring out how to change the design to handle the above facts, probably the biggest decision to make is whether multibyte values should be saved in RAM/ROM as [big or little endian](https://en.wikipedia.org/wiki/Endianness). The endianness of a computer is really a design choice, one is not better than the other, but each have design implications. To make the choice here, I am going to consider what I am looking to do next. Eventually I do intend to implement multibyte math operations. To do this using an 8 bit ALU requires that the math operations start on the lest significant byte, and the moving forward through the higher order bytes, carrying the carry bit of each previous 8 bit math operation. This is more easily done with multibyte numbers that are arranged with little endian, as the first memory address of the multibyte number is the least significant byte. 

So given the choice of little endian, what does this mean for how instructions are laid out in memory and then acted on in microcode? To a get a general sense, let's investigate the `LDA` instruction to load the value at memory address 0xABCD into register A. Using the original Ben Eater SAP-1 4-bit instruction value, the instruction machine code would look like this:

```
 Byte:    0      1      2
      | 0x1X | 0xCD | OxAB |
          ^      ^      ^
          |      |      |
  Instruction   LSB    MSB
```

The upper 4 bits of the first byte contain the instruction code of `0001`, or `0x1` in hex. The lower 4 bits of the first byte used to be the memory address for this command under the original Eater SAP-1 design, but now it is ignored in this transitional instruction set. The second byte is the least significant byte of the address, since the least significant byte goes first in little endian encoding. This leaves the third byte of the full instruction encoding to be the most significant byte of the address value. A similar pattern can be described for the other instructions.

The next question is how the microcode will work when the full set of information for the instruction is spread across multiple bytes. Again, let's take a close look as to how the `LDA 0xABCD` instruction would be acted on in microcode:

| Step | Active Control Lines | Description |
|:-:|:--|:--|
| 0 | `PCa`, `RMo`, `IRi`,  `PCe` | At the start of any instruction, we expect the program counter is already pointing at the first byte of the next instruction, so the first task is to move the byte value at the program counter address into the instruction register. Here, we write the program counter value to the address buss (`PCa`), which will cause the memory to make available the value at that address. Then we write the memory value to the data bus (`RMo`) and write whats on the data bus into the instruction register (`IRi`). Finally, increment the program counter to point at the next memory address. We don't know yet whether that memory address is the next instruction or a parameter to the current instruction. |
| 1 | `PCa`, `RMo`, `ARi`, `PCe` | We now know we are doing the `LDA` instruction, which means the program a counter is now pointing at the LSB of the address from where to read the value into register A. So, we write the value at that address into the lower byte of the address register. Note that the `HILO` line is not LOW here (not activated), so that state in combination with `ARi` causes the data bus value to be written to the lower byte of the address register. Finally, in the next step we will need to next get the MSB of the instruction parameter, so increment the program counter. |
| 2 | `PCa`, `RMo`, `ARi`, `HILO` | We now write the value at the third byte in the instruction to the MSB of the address register. |
| 3 | `PCe`, `ARa`, `RMo`, `Ai` | We increment the program counter so that it now points at the next instruction. At the same time we can write the address register value to the address bus (`ARa`), and then writing the memory value at that address to the data bus (`RMo`) which in turn is written into register A (`Ai`) |
| 4 |  `SCr` | The instruction is done, so reset the step counter (`SCr`). |

The rest of	 the instructions would follow similar patterns with respect to handling multi-byte instructions. The key point here is that the program counter is now incremented not just to get the next instruction, but to also fetch all bytes in the current instruction. 

The microcode table for the original Eater SAP-1 instruction set [can be viewed here](http://bit.ly/breadboard-cpu-16-bit-addressing-4-bit-instructions). A YAML configuration for generating the control lines EEPROM images [can be found here](microcode/upgrade-ram-4-bit-instructions-microcode.yaml), which is used with [the microcode generator here](../microcode-generator).

## Programming 

### Boot Loader 
If it is desired to manually key in a program using the microswitches, the device now needs a simple boot loader to handle the fact that when reset, the program counter will be pointing at address `0x0000`, which is in ROM. To get the program counter to jump to the start of RAM at address `0x8000`, a simple ROM image was created that has the `JMP 0x8000` instruction at address `0x0000`. The ROM image may be [found here](bootcode).

### Assembler
In order to create ROM images or even to more easily calculate the machine code to be manually keyed into RAM, an [assembler](https://en.wikipedia.org/wiki/Assembly_language#Assembler) is a useful tool. However, there exists no assembler for my breadboard computer. To address that, I wrote an assembler called [BespokeASM](https://github.com/michaelkamprath/bespokeasm). The key feature I needed in the assembler was the ability to easily change the instruction set architecture that the assembler builds to. BespokeASM allows the creation of a configuration file where the instruction set that should be use to generate machine code is defined. Instructions on how to install BespokeASM can be [found at the BespokeASM wiki](https://github.com/michaelkamprath/bespokeasm/wiki/Installation-and-Usage). 

The BespokeASM configuration file for the breadboard CPU's instruction set at this point in it's evolution [can be found here](examples/kamprath-16bit-addr-4bit-instrs-bespokeasm.yaml), and example programs can be found in [the examples directory](examples).

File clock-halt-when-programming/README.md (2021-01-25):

# Clock Halt When Programming
In the original design, the system clock can be halted with either the manual clock switch or the system control `HLT`. However, if you switch the computer to programming mode in order to enter RAM values by asserting the `PROG` signal (which, despite notation, is active low), the system clock may continue running, causing the the computer to continue to iterate through the microcode steps of the current instruction. This can create problems if you happen to switch to programming mode when the computer was on a step that has a "RAM in" step. 

This improvement changes the SAP-1 to simply halt the system clock when switched to programming mode. 

## Design Approach
The `PROG` signal that come from `SW6` in the memory address register module will be what is used to signal the clock to halt. When the run/program switch is set to run mode, the `PROG` signal floats to what ever the `S` inputs of the 75LS157 is pulled to. While ostensibly these chips pull the `S` input high, in practice this has proven to be unreliable to depend on. So one of the modifications of this improvement is to pull the `PROG` line high with a 10K Ω resistor anywhere along the `PROG` line.

When the `PROG` signal is low, the computer is in programming mode. It's this low signal that we want the clock module to cue off of to halt, and when `PROG` returns to high, the clock should honor any other halt inputs. One way to accomplish this is to use the extra AND gates on the 74LS32 chip original found in the clock module to AND together the inverted `HLT` signal and the `PROG` signal. That way, when the the `HLT` signal is low (it gets inverted before the AND gate) and the `PROG` switch is in run mode, thus pulled high, the clock will run. When either the `HLT` signal is asserted high or the `PROG` switch is in program mode, the clock will be in the halted state. 

### Schematic
The updated module is show in this schematic. The changes over the original model are the addition of the `PROG` line from the address register module, the pull up resistor on that line, and AND'ing that line with the inverted `HLT` line using the last remaining AND gate on the 74LS08 chip in the clock module. 

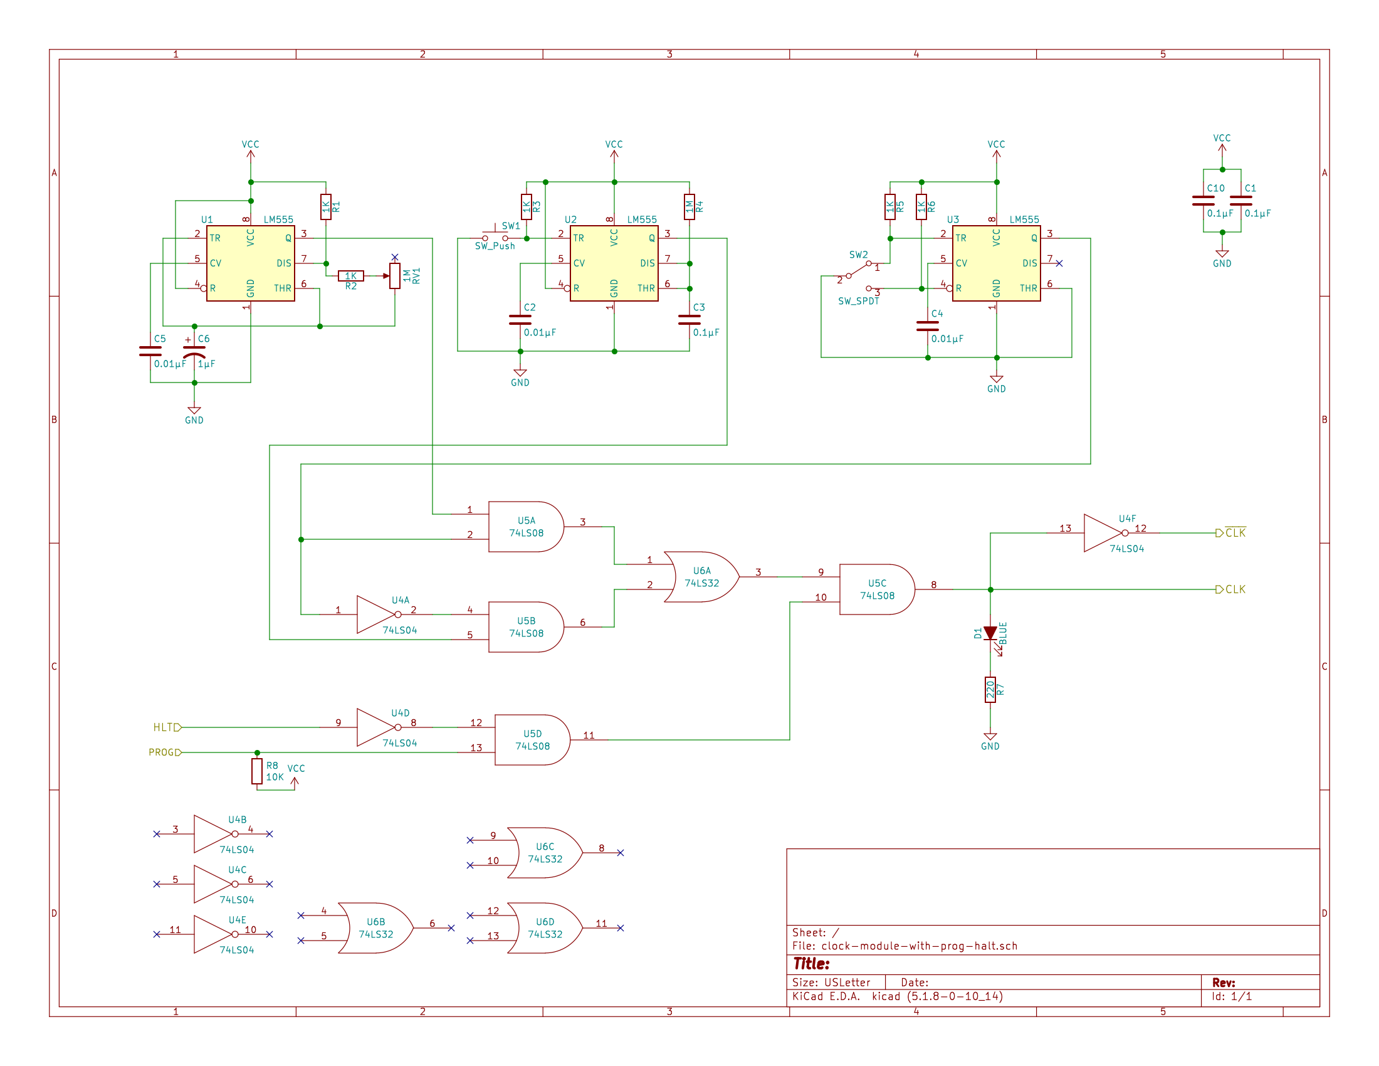
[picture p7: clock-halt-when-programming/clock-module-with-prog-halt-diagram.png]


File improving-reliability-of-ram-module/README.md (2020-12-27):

# RAM Module Reliability

## Project Overview
The design of the RAM Module in Ben Eater's SAP-1 has two issues that impact the reliability of not only the RAM module, but the SAP-1 computer as a whole. The first problem is that the RC circuit used to convert the clock signal that drives the RAM write enable line into a shorter pulse has the side effect of creating a "negative pulse" back into the clock line on the trailing edge of the click signal. The second issue is that the 74LS157 used to select whether the RAM write enable signal comes from the manual switch or from the control logic can on occasion create spurious low signals into the RAM write enable despite both of the input lines being high that the 74LS157 is selecting from. I explain the details of both of these problems, and their solution, [in a video on YouTube here](https://youtu.be/W2w9KVmyxRs):

SAP-1 RAM Reliability Video (https://youtu.be/W2w9KVmyxRs)

## Design
### Isolating the Clock Line
The design to isolate the clock line from the RC edge detecting circuit is straightforward. Simply place a Schottky diode between the clock line and the capacitor of the RC circuit. The type of Schottky diode I used is a BAT-43.

### Preventing Output Noise from the 74LS157
As explained in the video, the root cause of the spurious low pulses out of the 74LS157 used to control the source of the RAM write enable signal is how logic gate delay interacts with the underlying logic design of the 74LS157. The solution is to have the steady state input into the 74LS157 be low rather than high. To do that, the RAM write signal ultimately sourced from the clock is inverted through an extra NAND gate on the 74LS00 that was already next to the 74LS157, and the manual RAM write switch is converted to being push to make high signal. The output of the 74LS157 is re-inverted again through another extra NAND gate on the 74LS00 before being routed into the write enable lines of the RAM chips. 

## Electrical Schematic
The updated schematic of the 16 byte RAM modules can be found in this repository.

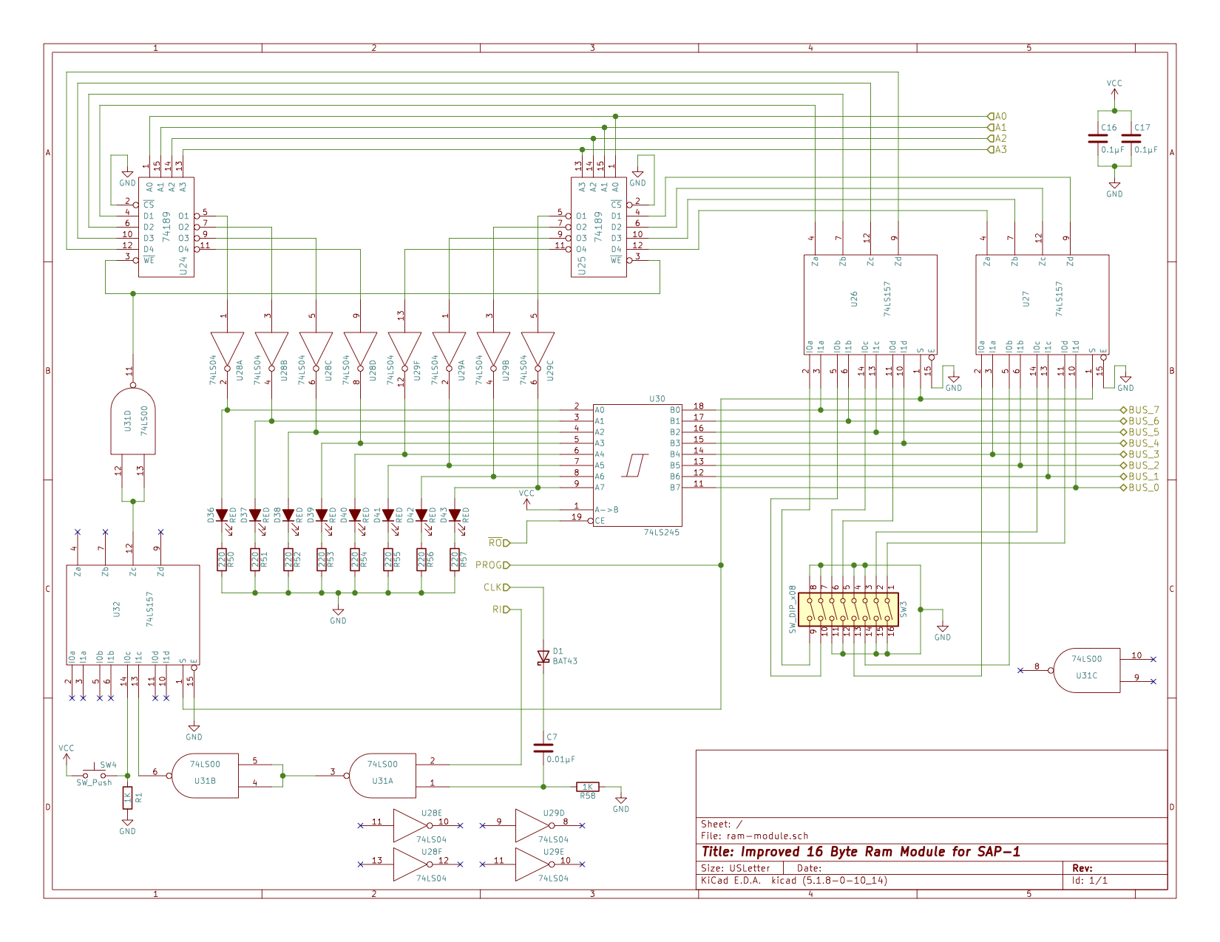
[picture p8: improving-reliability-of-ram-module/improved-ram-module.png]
Improved SAP-1 RAM Module


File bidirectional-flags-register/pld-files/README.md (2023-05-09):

# `PLD` Files for Programmable Logic

## Compiling PLD
The `.pld` files in this directory may be compiled with [GALasm](https://github.com/daveho/GALasm), producing a `.jed` file amonst others. Then the `.jed` file is used to program a `ATF22V10C` or `GAL22V10`.

```sh
galasm flags-register-22v10.pld
```

## Programming the 22V10
The `ATF22V10C(UES)` type should be used when programming the ATF22V10C with `minipro`.

```sh
minipro -p "ATF22V10C(UES)" -w flags-register-22v10.jed
```

### Updating TL886II+ Firmware
Your TL866II+ may have an older version of firmware that is unable to program the `ATF22V10C`. You will need to latest firmware to be able to program these chips. Here is the process for updating the TL866II+ firmware using the `minipro` command line tool on MacOS and Linux:

1. Download Windows Minipro/XGecu Pro application from manufacturer site: [autoelectric.cn](http://www.autoelectric.cn/en/tl866_main.html)
2. Extract executable from RAR file:
```sh
unrar x XgproV1220_Setup.rar
```

3. Extract the `updateII.dat` file from the executable extracted in step 2.
```sh
unrar x XgproV1220_Setup.exe
```
4. Update the TL866II+ firmware with:
```
minipro -F updateII.dat
```

## More Information
More information about programmable logic devices can be found at these links:
* [Understanding Programmable Logic - The GAL22V10](https://retrobrewcomputers.org/n8vem-pbwiki-archive/0/82152589/Programmable%20logic%20devices%20-%20v1.6.pdf) - A good overviews of what programmable logic devices are.
* [Galette](https://github.com/simon-frankau/galette) - an alternative GAL PLD assembler
* [GAL-ASM-Starterkit](https://www.mikrocontroller.net/attachment/20953/GAL-ASM-Starterkit_Manual.pdf) - Documentation the PLD file syntax from another PLD assembler.

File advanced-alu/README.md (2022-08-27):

# Advanced Arithmetic Logic Unit

## Overview
I have been building towards this for a while. Back when I started extending my Ben Eater SAP-1 and building my PUTEY-1 computer, I established a goad of doing 64-bit math reasonably efficiently on the 8-bit architecture. This project brings that goal to fruition. 

So the big question is why is this project needed? Could I not do 64 -bit math with the 74LS283-based ALU of the original SAP-1? The answer is I could technically do 64-bit math, but multiplication and division would be extremely inefficient. The reason being is that both multiplication and division would have to be implemented as addition and subtraction loops (respectively) and for larger numbers, those loops will be slow. While there is a [clever tricks to squeeze some more performance out of the 74LS283s for multiplication](https://hackmd.io/@wmvanvliet/SJHhPqr4c), it doesn't address division and I also desired a more robust set of features.

The complete set of features I desire to implement with this project:

* Add and subtract instructions have a "with carry" version
* The AND, OR, and XOR logical operations
* Be able to shift and rotate values left or right, optionally "with carry".
* A "test bit" instruction will test a 8-bit source and set the Z flag accordingly. 
* A general compare operation that can determine equality and magnitude differences.
* Ability to write flags register to data bus and be read by other entities on data bus, notably pushing the value on the stack.

Advanced Arithmetic Logic Unit (https://youtu.be/EK345Iy7LGQ)

## Design
### Chip Selection
The core of this project centers around the 74LS382 arithmetic logic unit. One might ask why I didn't go with the redo-popular 74LS181. Honestly, I can't make heads or tails of all of its logic functions and how they map to my goals above. The 74LS382 very cleanly has an addition, subtraction, logical AND, logical OR, and logical XOR operation, making its use quite simple in the PUTEY-1 architecture. Another benefit of the 74LS382 is that in addition to having a carry flag, it has an overflow flag. 

For bit shifting, I went with the 74LS194 bidirectional shift register. An attractive aspect of these chips is that they have separate input and output pins, plus loading the input is clocked. In this way they are much like the 74LS173 registers used widely in the PUTEY-1 already. Given that, I use that 74LS194 to back the `A` register too. This makes the `A` register central to the operations of the ALU. To enable both shifts and rotations, the left and right serial input pins are connected to the right-most and left-most output bits, respectively, or with the carry flag. Whether the opposite output bits or the carry Flagg is used to populate the serial inputs with a value is moderated by logic gates connected to various control lines.

At the heart of the comparison operations is the 74LS682 magnitude and identity comparator. I use this chip twice, once with the 74LS382 logic units to be able to easily detect zero-valued results of a logic operation, and then once to provide a general capability to compare the value on the a data bus to either zero or another 8-bit value stored in the temp register. Using this chip to compare 8-it values to zero is much easier than the NOR/AND combination that I used previously. Also used in the comparison unit is a 74LS151 8-to-1 data selector. This chip makes it easy to test the value of a given bit on the data bus. The it number being test is selected by the least significant 3 bits of the temp register, and the zero flag gets set of the bit value is zero. I decided to go with setting the zero flag in order to keep the semantics of the zero flag consistent and keep the number of flags PUTEY-1 has to a minimum. In order to allow branching if the bit value is one, I just need to create a `jnz` "jump if not zero" instruction in the microcode.

Finally, I make use of the ATF22V10C programable logic device in this build. In order to effective the logic of how the control lines would control the various aspects of this ALU, may discrete logic gates would be needed. While part of the charm of this project is to use discrete logic gates where possible, I just felt this project required too many. A programmable logic device allows you to program the logical relationship between a set of input pins and a set of output pins. You could think of these devices as something similar to an EPROM, but they are much faster and use logical relationships to describe the input-to-output relationships as opposed to data. Furthermore, a certain set of pins on these devices can be programmed to be with  input or output pins. In that sense, they are much better suited than EPROMS to consolidate discrete logic gates. I use two of these devices, one to manage the control lines going into the ALU, and one to arbitrate the various flags. These chips are programmed with `PLD` files [as described here](./pld-files/).

#### Data Sheets
The data sheets for key ICs used in this build:

* [74LS382 Arithmetic Logic Unit](./datasheets/74LS382.pdf)
* [74LS682 8-bit Magnitude/Identity Comparator](./datasheets/sn74ls682.pdf)
* [74LS194 4-bit Bidirectional Shift Register](./datasheets/sn74ls194a.pdf)
* [74LS151 8-to-1 Data Selector](./datasheets/74LS151.pdf)
* [ATF22V10C Programmable Logic Device](./datasheets/ATF22V10C.pdf)

### Flags
There are now four status flags on the system that provide input to the control logic. Some of these flags have slight different means depending on what unit set it. The flags and how they are set are:
* `ZF` - **zero** - Set when the results of a math or logic operation results in a zero value, when data bus value being tested is zero, or when the bit being tested is equal to zero.
* `CF` - **carry** - Set when the addition math operation results in a carry, the subtraction math operation does not require a borrow, or when the left or right shift operation in the A register shifts a one-valued bit out.
* `OF`  - **overflow** - Set when the math operation of the `74LS382` results in an overflow or when the compare operation indicates that the left hand value (the value in the temp register) is greater than the right hand value (the value being read from the data bus).
* `EF` - **equal** - Set when compare operation indicates both values (temp register and value on data bus) are equal. 

One flag that is not present that one frequently sees in these sort of projects is the negative flag, set if bit 7 of a value it equal to 1. I did not implement it here because I don't yet see the use case and if I ever did need it, the bit testing functionality being implemented in this project would fully cover that use case (one would just test bit 7). 

### Control Line Assignment
This project continues to use the control logic design introduced in the [8-Bit Instruction Register project](../instruction-register-8-bit/), however the control line assignments are redone some. The control line assignments are:

| Control Line Position | Bank | Group | Symbol | Notes |
|:-:|:--|:--|:-:|:--|
|1 | Left | Direct | `HILO` | Indicates which byte of a 16-bit register is being operated on |
|2 | Left | Direct | `PCa` | Write program counter value to address bus |
|3 | Left | Direct | `ARa` | Write memory address register value to address bus |
|4 | Left | Direct | `SPa` | Stack pointer address activate |
|5 | Left | Direct | `HLa` | `HL` register address activate |
|6 | Left | Direct | `AOa` | Write Address Offset results to address bus adder |
|7 | Left | Direct | | *unused* |
|8 | Left | Direct | `AOi` | Address Offset register in from data bus |
|9 | Left | Direct | `PCi` | Read data bus value into single program counter byte indicated by `HILO`, or address bus value if `DSs` is selected |
|10 | Left | Direct | `IRi` | Read data bus value into instruction register |
|11 | Left | High | `MDi` | Memory device read from data bus |
|12 | Left | High | `Ai` | Read data bus value into `A` register |
|13 | Left | High | `Ti` | Read data bus value into temp register |
|14 | Left | High | `HLi` | Read data bus value into single `HL` register byte indicated by `HILO` |
|15 | Left | High | `Ii` | Read data bus value into `I` register |
|16 | Left | High | `Ji` | Read data bus value into `J` register |
|17 | Left | High | `ARi` | Read data bus value into single memory address register byte indicated by `HILO` |
|18 | Left | Low | `PCe` | Activate program counter increment |
|19 | Left | Low | `ARe` | Activate memory address register increment |
|20 | Left | Low |  `SPe` | Increments stack pointer value,  or decrements when `SUB` is active |
|21 | Left | Low | `Ie` | Activate register `I` increment, or decrement when `SUB` is active  |
|22 | Left | Low | `Je` | Activate register `J` increment, or decrement when `SUB` is active |
|23 | Left | Low |  `HLe` | `HL` register increment enable |
|24 | Left | Low | |  *unused* |
|25 | Right | Direct | `SUB` | Indicates whether the increment operation should instead be a decrement operation |
|26 | Right | Direct | `CRY` | Use carry flag to ALU operation |
|27 | Right | Direct | `S0` | ALU control bit `S0` |
|28 | Right | Direct | `S1` | ALU control bit `S1` |
|29 | Right | Direct | `S2` | ALU control bit `S2` |
|30 | Right | Direct | `S3` | ALU control bit `S3` |
|31 | Right | Direct |  | **Reserved:** `INTr` (reset interrupt status) |
|32 | Right | Direct |  | **Reserved:** `INTi` (load interrupt status) |
|33 | Right | Direct | `AP1` | Add 1 to value on address bus |
|34 | Right | Direct | `ABo` | Write the byte indicated by `HILO` of the address bus to the data bus |
|35 | Right | High | `MDo` | Memory device output to data bus |
|36 | Right | High | `Ao` | Write contents of `A` register to data bus |
|37 | Right | High | `To` | Write at the temp register to the data bus |
|38 | Right | High | `Fo` | Writes the Flags register to the data bus |
|39 | Right | High | `Io` | Write contents of `I` register to data bus |
|40 | Right | High | `Jo` | Write contents of `J` register to data bus |
|41 | Right | High | `∑o` | Write the results of the ALU operation to data bus |
|42 | Right | Low | `SCr` | Resets both the step counter and the extended instruction bit. A step counter overflow needs to do the same thing. |
|43 | Right | Low |  `SPr` | Reset stack pointer to "empty stack" value |
|44 | Right | Low |  `DSs` | Data source input select for 16-bit registers that can load from either address or data bus. LOW is data bus, HIGH is address bus. |
|45 | Right | Low | `CMPs` | Write the temp register to the comparison unit |
|46 | Right | Low | | *unused* |
|47 | Right | Low |  `XTD` | Activate extended instruction bit and resets the step counter. |
|48 | Right | Low | `HLT` | Halt the system clock |

The significant changes over the last project are:

* `CRY`, `S0`, `S1`, `S2`, and `S3`, `CMPi` control bits are added to manage the ALU through the gate array logic. 
* The `∑f` control line for controlling when the flag register reads in flags from the ALU is replaced by the ALU control bits.
* `If` and `Jf` flags control lines removed. Now, microcode will use the comparison unit to test for zero in the `I`, `J`, and `HL` registers during increment and decrement operations.
* `Fo` flags out control line added
* The `SUB` signal is now relevant only to decrement operations in the `I`, `J`, and `HL` registers.
* The `XTD` control line was moved to one of the 74HCT236 banks since in its currently implementation it will never need to be active when another control line is active.

### Gate Array Logic
The detailed programming of the ATF22V10C chips to implement each of the following applications can be views in the [`pld-files` directory](./pld-files/). Below is only an overview of what each chip's programming is intended to accomplish.

#### ALU Instruction Control Line Configurations
The gate array logic for the ALU controller is configured such that the following control line configurations effect the indicated operation:

| Operation | Description | `CRY` | `S0` | `S1` | `S2` | `S3` | `CMPs` | Flags Set? |
|:--|:--|:-:|:-:|:-:|:-:|:-:|:-:|:-:|
|`add`| Add temp value to `A` register | 0 | 1 | 1 | 0 | 0 | 0| `ZF`, `CF`, `OF` |
|`addc`| Add temp value and carry flag to `A` register | 1 | 1 | 1 | 0 | 0 |0| `ZF`, `CF`, `OF` |
|`sub`| Subtract temp value from `A` register | 0 | 0 | 1 | 0 | 0 |0| `ZF`, `CF`, `OF` | 
| `subb` | Subtract temp value from `A` register with carry flag used to indicate whether borrow was taken from `A` when `CF` = 0 | 1 | 0 | 1 | 0 | 0 |0| `ZF`, `CF`, `OF` |
| `and` | AND temp value with register `A` | 0 | 0 | 1 | 1 | 0 |0| `ZF` |
| `or` | OR temp value with register `A` | 0 | 1 | 0 | 1| 0 |0| `ZF` |
| `xor` | XOR temp value with register `A` | 0 | 0 | 0 | 1 | 0 |0| `ZF` |
| `lsr` | Logical shift right register `A` | 0 | 0 | 1 | 0 | 1 |0| `CF` |
| `lsrc` | Logical shift right register `A` with carry flag filling in leftmost bit | 1 | 0 | 1 | 0 | 1 |0| `CF` |
| `lsl` | Logical shift left register `A` | 0 | 1 | 0 | 0 | 1 |0| `CF` |
| `lslc` | Logical shift left register `A` with carry flag filling in rightmost bit | 1 | 1 | 0 | 0 | 1 |0| `CF` |
| `rotr` | Rotate bits in register `A` right one | X | 0 | 1 | 1 | 1 |0| - |
| `rotl` | Rotate bits in register `A` left one | X | 1 | 0 | 1 | 1 |0| - |
| `cmp` | Determine whether left hand value (placed in temp) is equal to or greater than of the data bus value | X | 1 | 1 | 1 | 1 | 1 | `OF`, `EF` |
| - | Determine whether the data bus value is zero. *Not an actual instruction, but used in other instructions.* | X | 1 | 1 | 1 | 1 | 0 | `ZF` |
| `tstb` | Determine if a data bus bit indicate by lower 3 bits of temp is zero | X | 0 | 0 | 0 | 1 |0| `ZF` |

#### Flag Arbitration
Arbitrating how all the various flag lines are applied to the flags register is the duty of a second ATF22V10C.  This one is programmed to take the the various individual flag lines from the various units, and combine them with the flag enable lines coming our of the ALU controller ATF22V10C, and then enable the current flags register input lines in combination with the flags register load line.  The logic is rather simple: only pass through a flags line when that flags line source is currently enabled.  There are four potential flags sources in the current design, outlined in this table:

| Flag Source | Flags Emitted | Descriptions |
|:-:|:-:|:--|
| `A` Register | `CF` | Indicates when a left or right shift pushes a bit off either side. |
| ALU (74LS382 chip) | `ZF`, `CF`, `OF` | The carry and overflow flags are emitted from the 74LS382 for addition and subtraction operations, and the zero flag is asserted for all operations that result in a zero value. |
| Byte Comparison | `ZF`, `OF`, `EF` | When the `CMPs`, the temp register is compared to the data bus value, assert either overflow *(temp > data bus)* or equal *(temp == data bus)* flags. When `CMPs` is not asserted, the data bus value is compared to zero, asserting the zero flag if it is. |
| Bit Comparison | `ZF` | The lower three bits of the temp register are used to indicate which bit of the data bus to test. If that bit is zero, the zero flag is asserted. |

### Updated Extended Instruction Logic
One of the shortcomings of my 8-bit instruction register project was how I enabled the `XTD` bit. The `XTD` bit effectively made the instruction register a 9-bit instruction space, and this bit would be set by a control line. The unfortunate design element is that when the `XTD` bit got set, the step counter was not itself reset. So, if the `XTD` bit get set on step 2 of an instruction, the first step under the `XTD` bit space would be step 3. The primary issue with the design is that the `SCr` control line is what was used to reset both the step counter and the `XTD` bit.

To address this issue, I updated what the `XTD` control line does. It now not only sets the `XTD` bit, but also reset the step counter. The step counter is reset near the falling edge of the clock after the `XTD` bit is set. That way, the first step with the `XTD` bit is set is step 0. Note that the `XTD` bit still gets reset on `SCr`, step counter overflow, and `CLR`.  To use the `XTD` control line properly in microcode, the XTD control line must be active on both the extended and non-extended version of the instruction step. Because of this, if a new instruction value is not loaded while in the extended steps, the `SCr` control line should be asserted before the extended step that contains the `XTD` control line. Furthermore, the `XTD` control line should not be asserted on step 7 because the hardware will reset the `XTD` bit at the end of step 7. With careful usage, this mechanism can also be used to extend the steps of an instruction from a max usable of 7 useful steps to 11 useful steps. I've got to admit, I am not entirely happy with this design, but it is functional, so we will go with it for now.

### Comparison Unit
The comparison unit is intended to provide general value comparison to the PUTEY-1. The basic design goal is to compare the value on the data bus to a reference value, and then set flags accordingly. There are two parts to the comparison unit implemented. The actual comparison operation is select by the ALU control lines as indicated above.

#### Value Comparison
The value comparison part uses a 74LS682 8-bit comparator to compare the data bus value to either the value in the temp register, or to zero. The 74LS682 as able to magnitude comparison and equality comparison, and this allows this part to set a `ZF` zero flag, `EF` equal flag, or `OF` overflow flag (which in this context means "greater than"). The `CMPs` line selects whether the comparison is being made to the temp register or zero.  When `CMPs` is LOW, the value comparison part compares the bus value to zero setting the `ZF` if it is equal to zero, and when `CMPs` is HIGH, the data bus value is compared to the value in the temp register, setting `EF` if they are equal or setting `OF` if the temp register is greater than the data bus value.

#### Bit Testing
The bit testing part uses a  multiplexer to determine if a specific bit on the data bus is equal to zero or not. The 74LS151 requires a 3 bit value to select which input bit to select. This is provided by the least significant 3 bits of the temp register. Then, the `ZF` zero flag is set if the selected data bus bit is equal to zero.

### Updated Counting Registers `I` and `J`
While I was happy with the `I` and `J` counting registers when I built them, time and use has shown me that they were probably more complicated than they needed to be. Specifically the circuitry to detect zero and carry conditions. In this build, I decided to simplify these registers' implementation by removing the zero and carry detection, and then leverage the comparison unit to detect zero values on increment and decrement operations. This means there is no longer a carry flag generated by the `I` and `J` registers. This is OK, as the carry flag was detected when an increment operation resulted in a zero value. One can just detect the zero value directly.

After removing the circuitry for flag detection, the `I` and `J` registers reduced down to each being two 74LS169 up/down counters and a 74LS245 bus transceiver.

### Updated Memory Map Controller
One thing I noticed as I started writing software for this build is that when the `FL` register writes to the address bus using the `ABo` control line, for certain values it would activate the `MMAPe` control line. While we do what a `MMAPe` control line to assert for certain address bus values, that is only useful when the  control lines are also asserted. So in this build I made a small update to the memory map controller to only assert `MMAPe` control lines when either `MDo` or `MDi` are also asserted.

### Faster Clock
With this build, the PUTEY-1 (beta) is finally ready to do higher order arithmetic. However, to do things like 64-bit multiplications, many iterations are still needed even with using the new bit shifting feature. So, the natural things to do to speed up computation of a computer is to increase the clock speed of the computer. 

To speed up the clock, I simply changed a resistor and capacitor of the clock unit. Using [the schematic of my last update to the clock](../stack-pointer/documentation/clock-module-with-error-halt.png) as a reference, I changed `R1` to 330 Ω, and `C6` to 1 pF. Those two changes yielded an updated clock frequency of about 380 KHz. 

#### Inductance, Capacitance, and Timing ... oh my!
Increasing the clock speed was challenged by the electrical properties of the breadboards used to make the PUTEY-1. As highlighted in previous projects, the inductance and capacitance of the breadboards and the long wires can cause spurious signals and echos in the various lines. This problem was most noticeable in the clock line, which is the longest wire run on the board. 

The below photo shows an example of the problem it caused. In this phot, you see the clock signal in cyan, and a register state in yellow. The register is not supposed to be loading a value, but you can see that it does change value at the same time the clock line has a small fluctuation after the clock value goes low. This fluctuation was enough that the register IC would perceive it as a rising clock signal and trigger what ever action the IC was configured to do, which in this case was to load a value, which was done prematurely. While I'll admit I don't know the detailed cause of this fluctuation, I believe it caused by the inductance on the clock line generating a small current pulse after the voltage and current on the clock line goes to zero. 

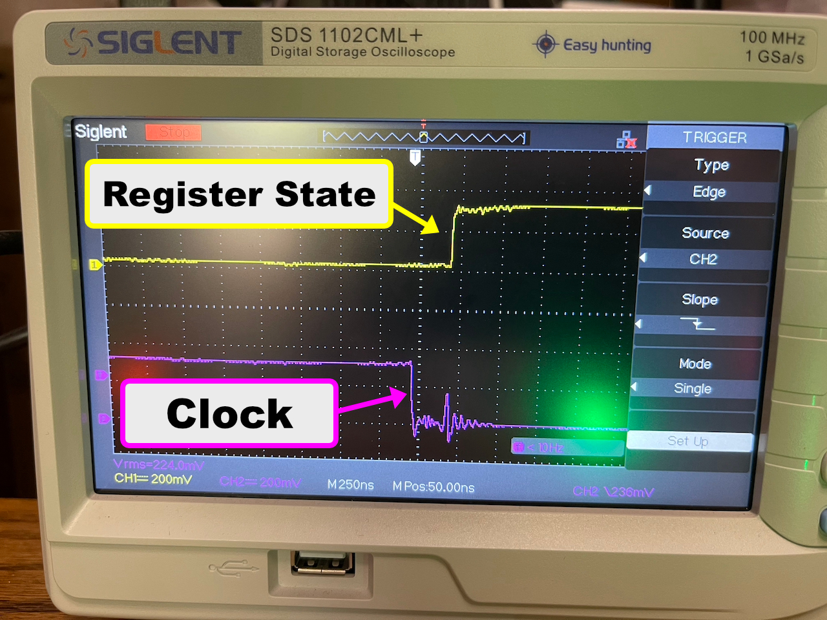
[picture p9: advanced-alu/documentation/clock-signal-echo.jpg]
Clock Noise Example


I tried two was to address the spurious signals in the clock line, with some success. The two methods used are:

1. I replaced the 74LS04 Inverters used in the clock design with 74LS14 Schmitt Trigger Inverters. This cleaned up the edges of the clock signal significantly. Furthermore, I found that some of the ICs that were most "distant" (at the farthest end of the clock line run) still got dirty edges to the clock signal. So I inserted a second 74LS14 into the clock line near these furthers ICs, and ran the clock through the Schmitt Trigger twice to keep the HIGH/LOW sense. This also cleaned up the edges for these "far" ICs. The double inserting does introduce a phase delay in the clock signal, but for the speeds I am running PUTEY-1 at, these delay is trivial.
2. The above Schmitt Trigger solution did not address the problem identified in the picture above, where a secondary pulse is created after the clock signal goes low. I found [this article on how to suppress noise in digital circuits](https://www.murata.com/en-us/products/emc/emifil/library/knowhow/basic/s2-chapter01-p1). The basic gist of the article is to use a ferrite bead inline with the signal line and in combination with a capacitor between the signal line and ground. Formulas are provided for determining the right value, but I just experimented and came to some values empirically. Using a ferrite bead and capacitor combo solved the clock signal fluctuation identified in the picture above. It id not fully remove the fluctuation, but the fluctuation was suppressed enough to not be perceived as a rising clock edge by connected ICs.

Given the changes identified above, I was able to increase the clock rate significantly, all the way to about 485 KHz. I have not tried a higher clock rate yet, primarily because I am still using a 555 oscillator for the clock and these chips do not go beyond 500 KHz. 

There was also an interesting timing issue that arose. When running the PUTRY-1 at 480 KHz and running certain programs, the LED for memory map control line `MMAP_15` would glow faintly even though nothing =was ever trying to write or read from an address in the `MMAP_15` memory space. The root of this ended up being a timing issue. Specifically, when the sequence of instructions would transition from using any memory map control line, thus `MMAPe` is active, to performing an operation when address line `A10`, which drives `MMAP_15`, is active (typically, interacting with the stack), there is a brief period of time when the `MMAPe` signal hasn't disabled yet due to the gate delay across all the logic that generates it, and address line `A10` is activated for the next instruction. This doesn't cause any really problems because this occurs in the instruction setup phase when the system clock goes low. In fact, the period of time that `MMAP_15` is high is a very small fraction of the clock half cycle. This phenomenon in fact happens at all clock speeds and the status LED for `MMAP_15` is momentarily switched on every clock cycle, but for a very brief period of time on the scale of about 100 nanoseconds. At low clock speeds, this ends up not being visible to the human eye, but at higher clock speeds, there are enough 100 nanosecond flashes over the span of 1 second that the human eye's persistence of vision will start seeing the the light emitting from the LED. 

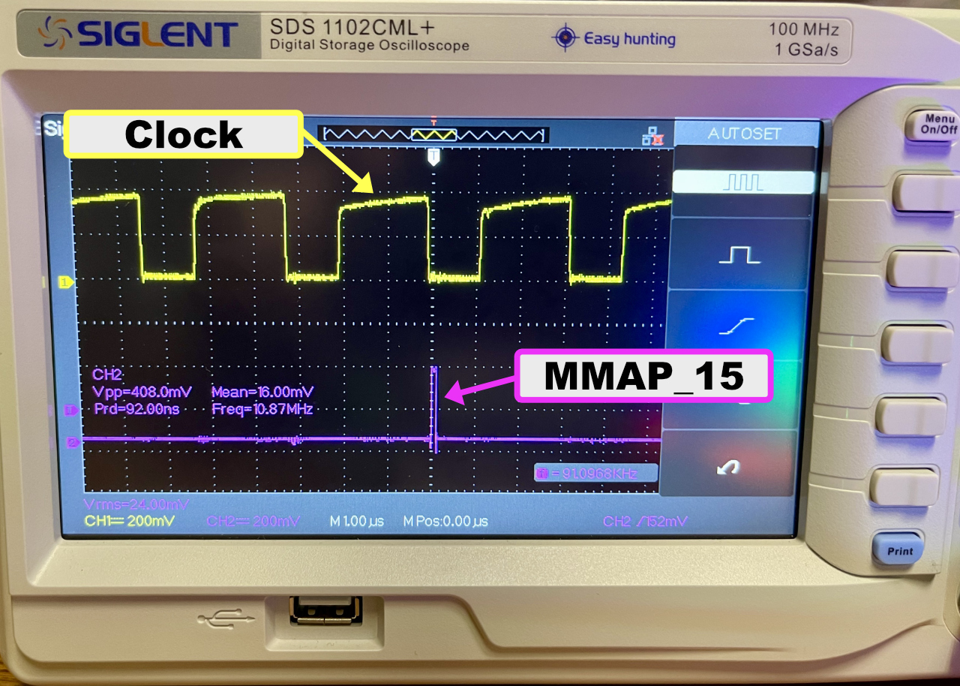
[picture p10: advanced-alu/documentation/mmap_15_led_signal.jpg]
MMAP_15 Spurious Signal


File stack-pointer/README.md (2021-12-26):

# Stack Pointer

## Overview
I'm finally at the point where I can add what I feel is the key upgrade to my SAP-1 based TTL computer: a stack pointer. A stack pointer enables general purpose programming in a computer, specifically the ability to call and return from subroutines and the ability to effectively make temporary variables in memory.

Adding a Stack Pointer (https://youtu.be/sUqvItfVIRc)

# Design

## Stack Pointer
There are plenty of resources that describe stack pointers online, so I am not going to go in detail here. But at a high level, you can think of the stack as a "pile" of memory that can place values on to the top of the pile or take values from the top of the pile. A stack pointer points to where the top of the pile of memory is. For the PUTEY-1, here are the behavioral requirements of the stack pointer:

* Given that the PUTEY-1 is an 8-bit system, multibyte values get pushed on to the stack one byte at a time.
* The stack pointer should point to the start of a multibyte value.
  * This means that for a multibyte value, the second byte is at an address value of one greater than stack pointer value. This in turn implies that the stack should "grow down" from the largest stack address value to smaller address values as values are pushed onto the stack.
  * When pushing multibyte values onto the stack, the most significant byte should be pushed first and the least significant byte pushed last.
* Stack pointer points at the last value pushed on the stack. This means it needs to be decremented before something is pushed onto the stack.

Given these goals, the design used for the stack pointer is to leverage four `74LS169` up/down counters. The stack pointer will have the concept of being "reset" to its starting value of `$FFFF`. This is done by tying high all of the `74LS169` inputs, and routing the `SPr` (stack pointer reset) control line to the load pins on the up/down counters.

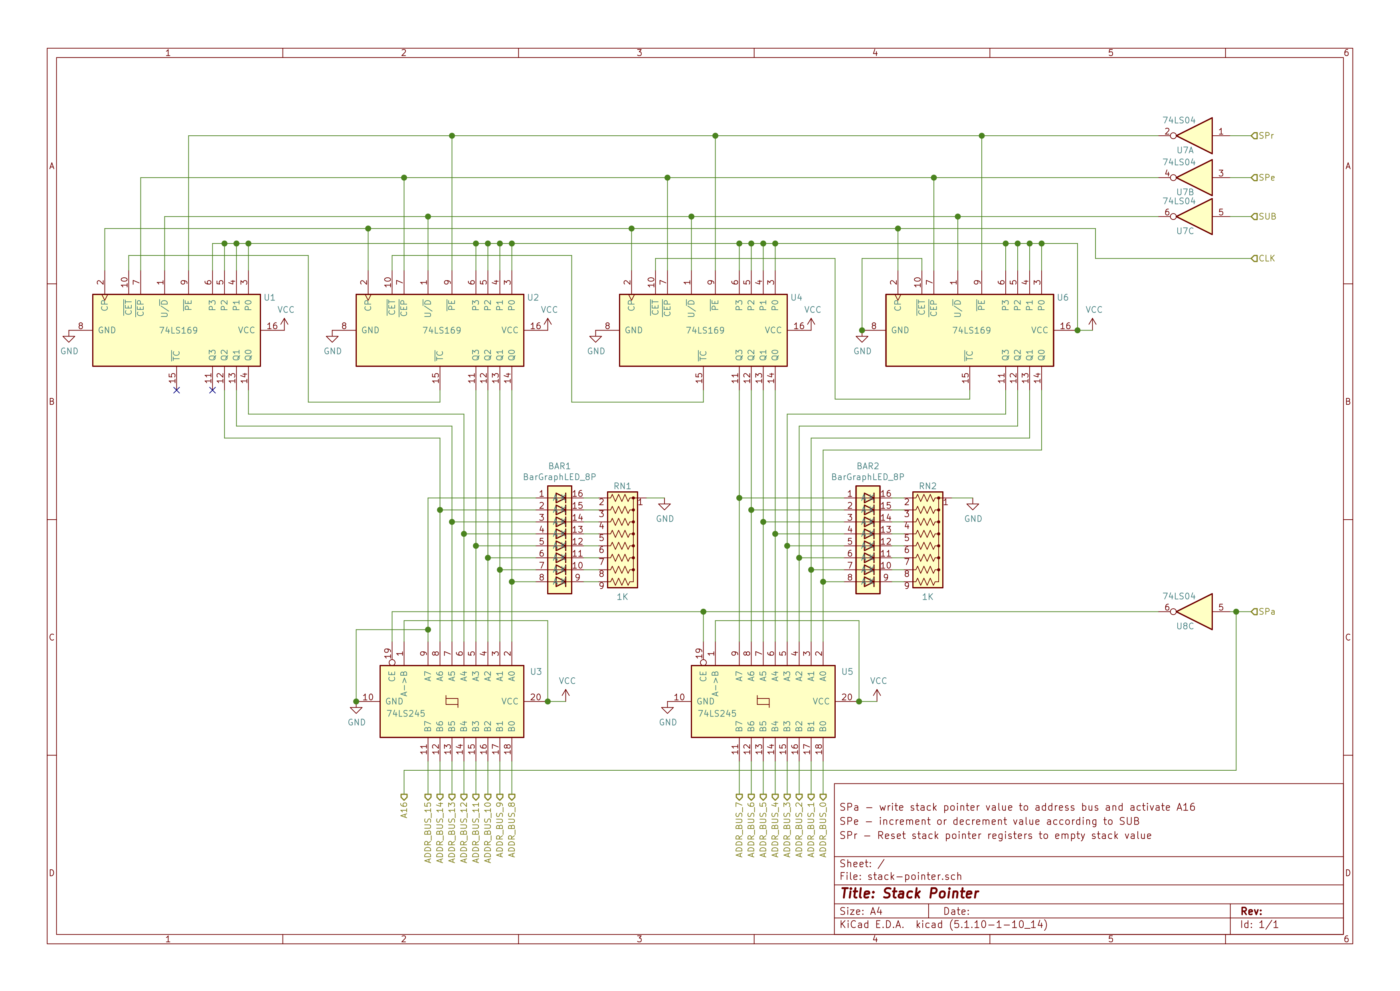
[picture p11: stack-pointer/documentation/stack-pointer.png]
Stack Pointer Schematics


### `push` and `pop`
The basic stack related instructions is to place data onto the stack and to take data off of the stack.

The instruction to place data onto the stack is called `push`, which takes one operand indicating the 8 bit value source. The microcode for this instruction first decrements the stack pointer, then copies the 8-bit value from the source indicated by the operand to the memory address now pointed to by the stack pointer. I also implemented a `push2` instruction that pushes 2 bytes on onto the step in the proper order to maintain the endianness of the 16-bit value.

The instruction to take values from the stack is called `pop`, which takes one operand indicating the 8 bit value destination for the value that is currently on the "top" of the stack. The microcode for this instruction first copies the value at the memory address that the stack pointer current points at to the destination specified in the operand, then it increments the stack pointer. I also implemented a version of `pop` with no operand, which can be used to remove a value from the stack (increment the stack pointer) without copying the value anywhere. Similar to `push`, a two-byte version of `pop` called `pop2` exists, and it writes the two byte value that starts at the top of the current stack to the specified 16-bit destination.

### Subroutine Calling
The concept of a subroutine is a section of code that you can jump to from anywhere in the overall codebase, and then when that subroutine's code is complete, the program's execution will automatically jump back to the instruction after the jump to the subroutine. To make this happen, before jumping to the subroutine the address after the jump instruction is pushed onto the stack, and the jump to the subroutine occurs. When the subroutine is done, the address that was pushed onto the stack is removed (popped) from the stack and placed into the program counter to effect a jump back to instruction after the jump to the subroutine.

The individual steps to make all this happen can be consolidated into two instructions:

* `call X` - The `call` instruction takes one operand which is the address of the subroutine that will be jumped to. Before jumping to that address, the address after the `call` instruction and its argument is pushed onto the stack.
* `ret` - The `ret` (return from subroutine) instruction will pop an address value from the stack and place it in the program counter, thus effecting a jump to that address.

#### Setting Program Counter with Address Bus Value
The `call` instruction has a lot happening. Load immediate address, push value of program counter to stack, set program counter to the address. This sequence of control lines needed 9 total steps (including prefix) to make that instruction work given the current hardware design, but the step counter only allows for 8. I could have changed the control logic to allow a step counter with 16 steps, but that didn't seem like the best  and would require me to change the instruction register I just built. So I ended updating the design of the program counter to be able to read in a value either from the data bus or the address bus. To do this, `74LS157` 2-to-1 multiplexers were used to enable the selection of input to the program counter. When reading from the data bus, the `HILO` control line is used to moderate which program counter byte the data bus is being read into.

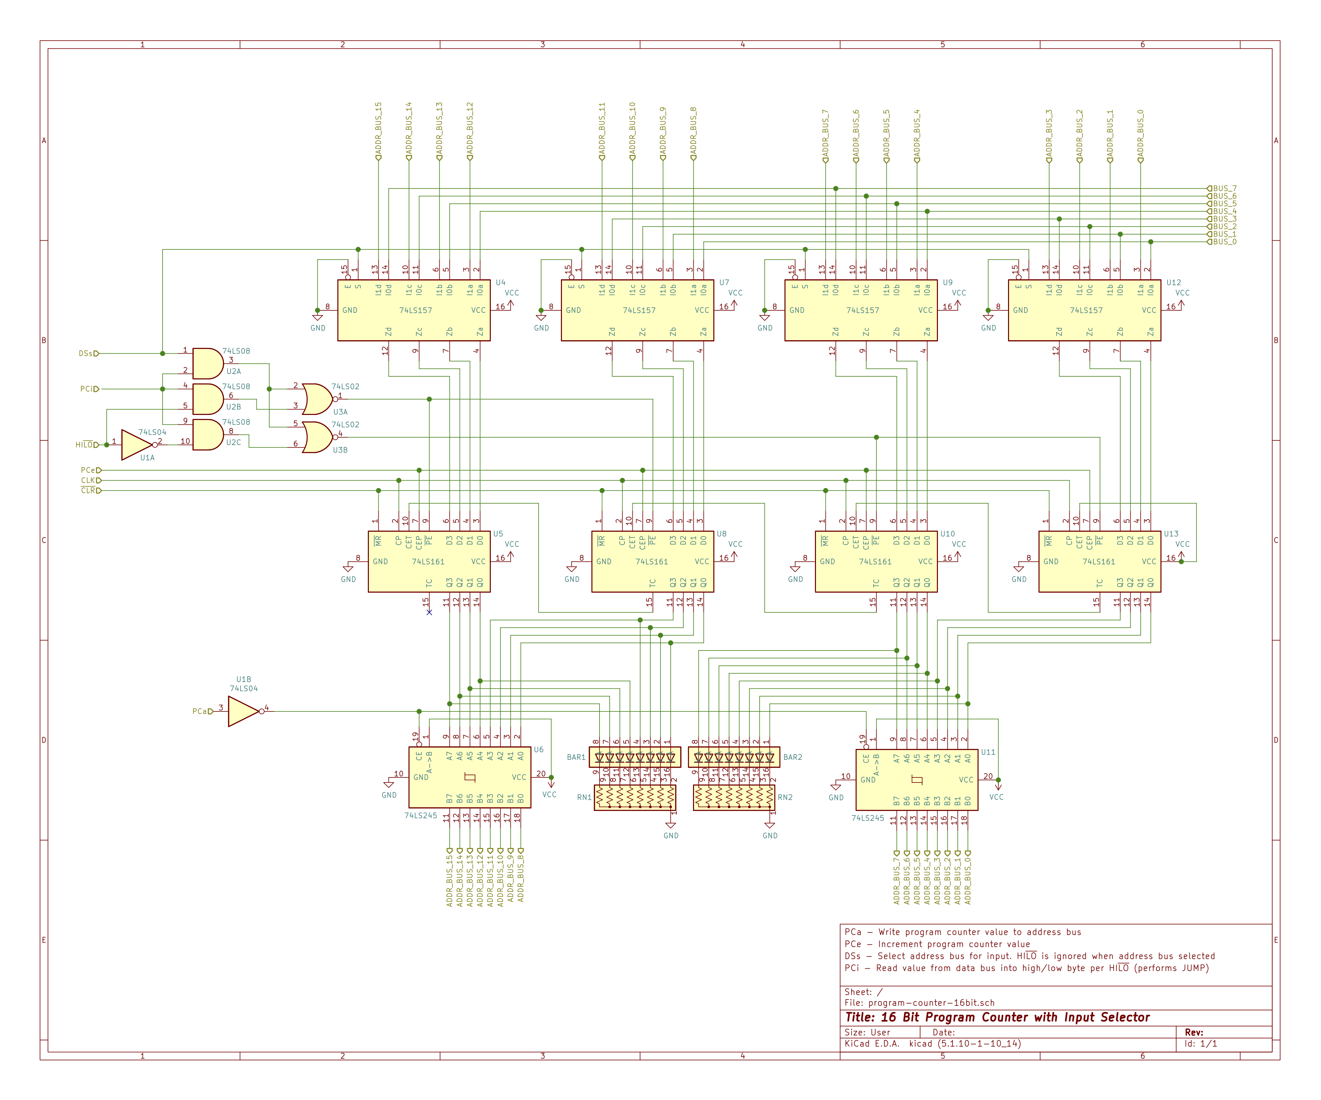
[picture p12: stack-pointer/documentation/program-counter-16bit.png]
Program Counter Schematics


## Address Offset Register
Having a stack pointer is great, but with a stack pointer alone you can only fetch what ever is on top of the stack. It would be desirable to be able to read (or write) a stack value that is any number of positions into the stack. A usage paradigm for this would be to push a subroutine's argument values on to the stack, and then within the subroutine be able to read (or even alter) the argument values push onto the stack. You wouldn't want to pop values off the stack to get to the subroutine's arguments because in doing so you would pop the return address off the stack since it was the last thing pushed onto the stack before jumping to the subroutine. So being able to read or write to stack memory at specific offsets from the current stack pointer would be useful.

To accomplish this, I introduce an address offset register to the design. This register is actually more than just a register, as it includes an adder that adds the value of the register to the current value on the address bus. The address offset register sits between the address bus that the various address registers (step counter, MAR, etc) write to and the address bus that the memory devices use to identify what memory address to read or write. In this way, the address offset register can alter the address emitted by more than just the stack pointer, however the stack pointer is the impetus for adding it. For clarity, I will refer to the address bus connected to memory devices as the memory address bus.

In order to keep things simple, the address offset register in my design is only 8 bits, assumed to always be positive. The register itself is implemented with two `74LS173` 4-bit registers, and the adder consists of four `74LS283` 4-bit adders. The address offset register is only connected to the lower 8 bits of the adders, with the equivalent inputs for the upper 8 bits of the adders tied to zero. The address offset register's input is connected to the data bus so that its value can be set. The address bus is the other input to the adders, and the adders output goes to the memory address bus. Given this configuration, the address offset can be applied to any address register source, however, I will only be enabling it in the microcode for the stack pointer, memory address register, and the [`HL` register](#16-bit-register-hl).

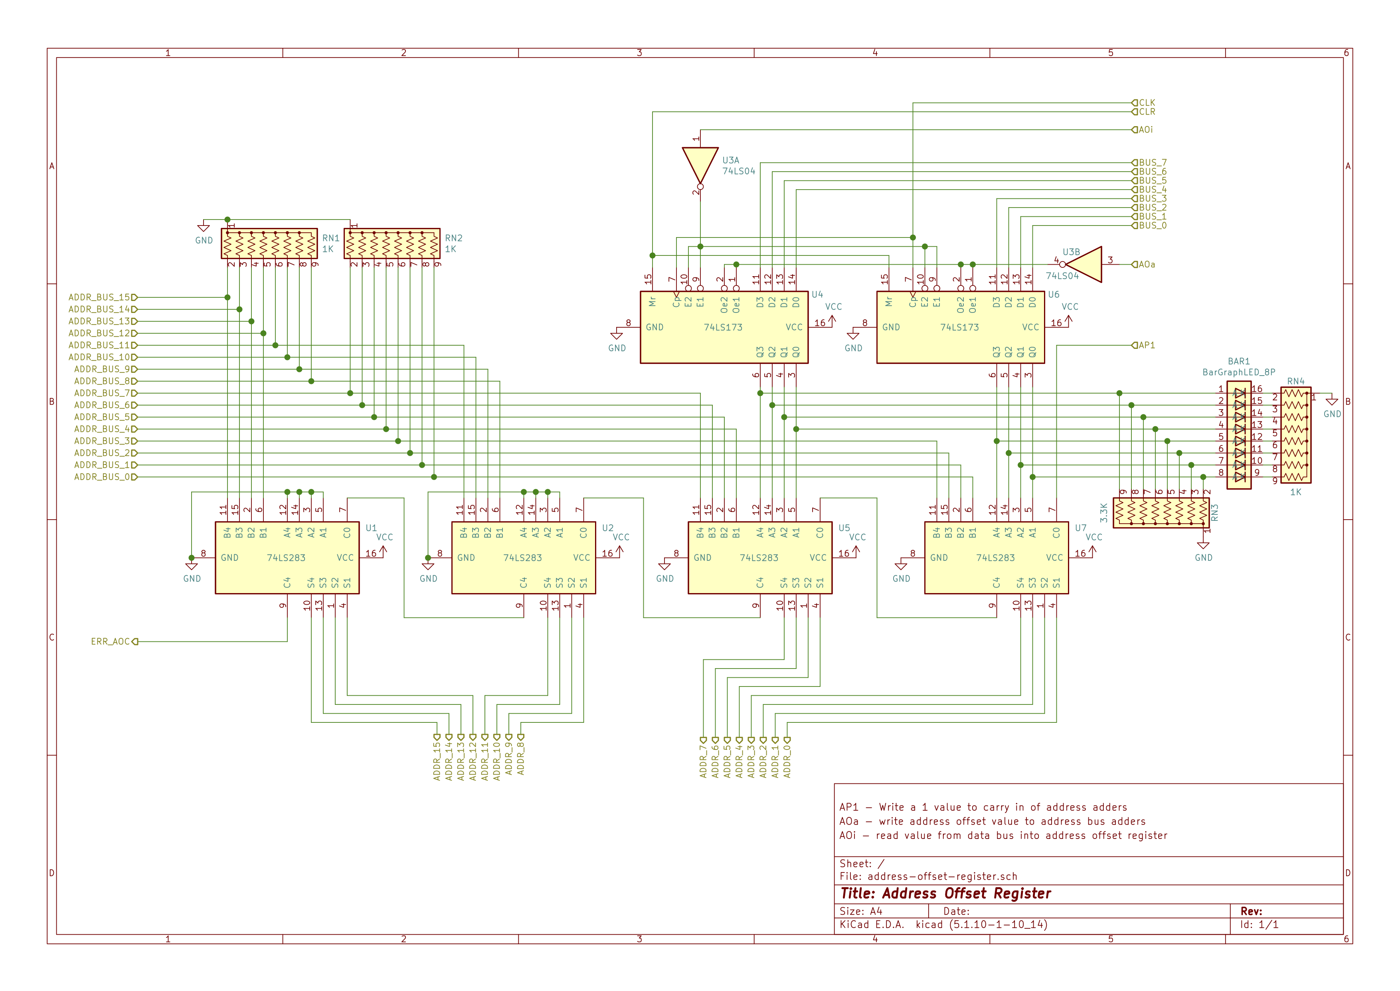
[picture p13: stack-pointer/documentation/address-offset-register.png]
Address Offset Register Schematic


### Address Plus One Control Line
When dealing with 16-bit values in 8-bit memory systems, one frequent operation needed is to increment an address value by 1 in order to get the second byte of the 2 byte value. To make this easier, I fed a control line into the carry in of the address offset register `74LS283` adder that represents the least significant 4-bits. I called this the "address plus one" control line, notated `AP1` in my design. This allows the address value used to be incremented for an instruction step by simply asserting the `AP` control line and without needing to change the address value in the register it resides.

## 16-Bit Register `HL`
The stack pointer cannot have its value directly set from either the address or data bus. However, we can create a 16-bit register that can have its value set from the data bus and write its value to the address bus to set the active memory address or the the data bus for general computations. Furthermore, like the stack pointer, this register can be made to increment and decrement its value. This register can be thought of as another memory address register, but your code is in complete control of its usage as it is not ever used implicitly by the microcode like the memory address register is.

The design used leverages the `74LS169` up/down counters in much the same way as the [increment registers](../increment-registers/) do, but set up for a 16-bit register. Unlike the increment registers, I did not add any carry or zero value flag detection circuitry, but I may change this in the future. The register reads from the address bus 8 bits at a time using the `HLi` control line and the `HILO` control line to control which byte is being read. The register can write its value to the address bus using the `HLa` control line. To write the `HL` register value to the data bus, the `HLa` control line is used in combination with the `ABo` control line which in combination with the `HILO` control line will transfer one of the address bus's bytes to the data bus.

The microcode will be set up such the `HL` register's individual bytes can be accessed as if they were 8-bit registers, `H` and `L`. Here `H` stands for the high byte of the `HL` register and `L` stands for the low byte. Accessing the individual byte of the `HL` register can be a convenience when constructing 16-bit values from 8-bit values. The 8-bit sub-registers of the `HL` registers can be accessed most anywhere in the machine code and microcode most anywhere that other 8-bit registers can be used.

The `HL` register I implemented is "incomplete" in some ways. Due to breadboard space, I was not able to add zero and carry flag detection for the increment and decrement operations.

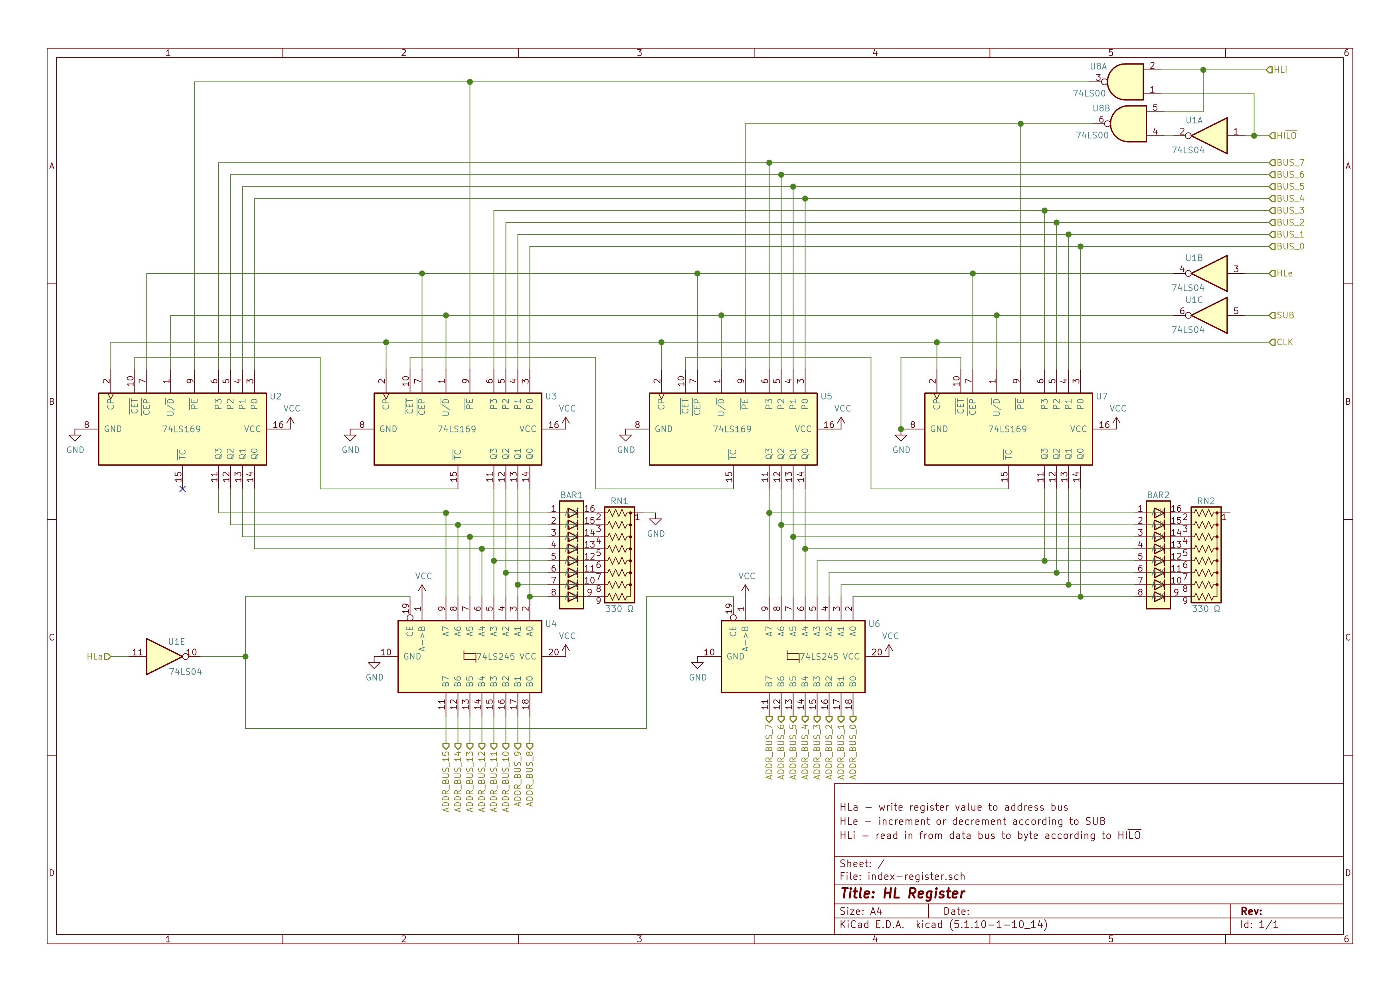
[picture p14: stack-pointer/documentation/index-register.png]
HL Register Schematic


## Halt on Error
I have implemented a few error conditions into the design. These error conditions represent states for which there is no clear "next step" for the hardware. I would consider it to be a programming error if the states were ever achieved, however, the CPU wouldn't be able to gracefully recover without an undesirable amount of additional hardware. So I turn these error states into control signals that will cause the system clock to halt. At that point the only possible recovery is to manually reset the CPU.

The error states implemented in this project are:
* `ERR_AOC` - The address bus and the address offset value sum up that causes a carry beyond 16 bits to occur.

I wanted to add error for both the stack pointer and `HL` register to capture when they roll over from `0xFFFF` to ` 0x0000`, or the other way too, but it turns out that would require more additional hardware than I have room for on the breadboards. So, for now, causing the stack pointer or `HL` register to roll over in either direction will be considered a programming error.

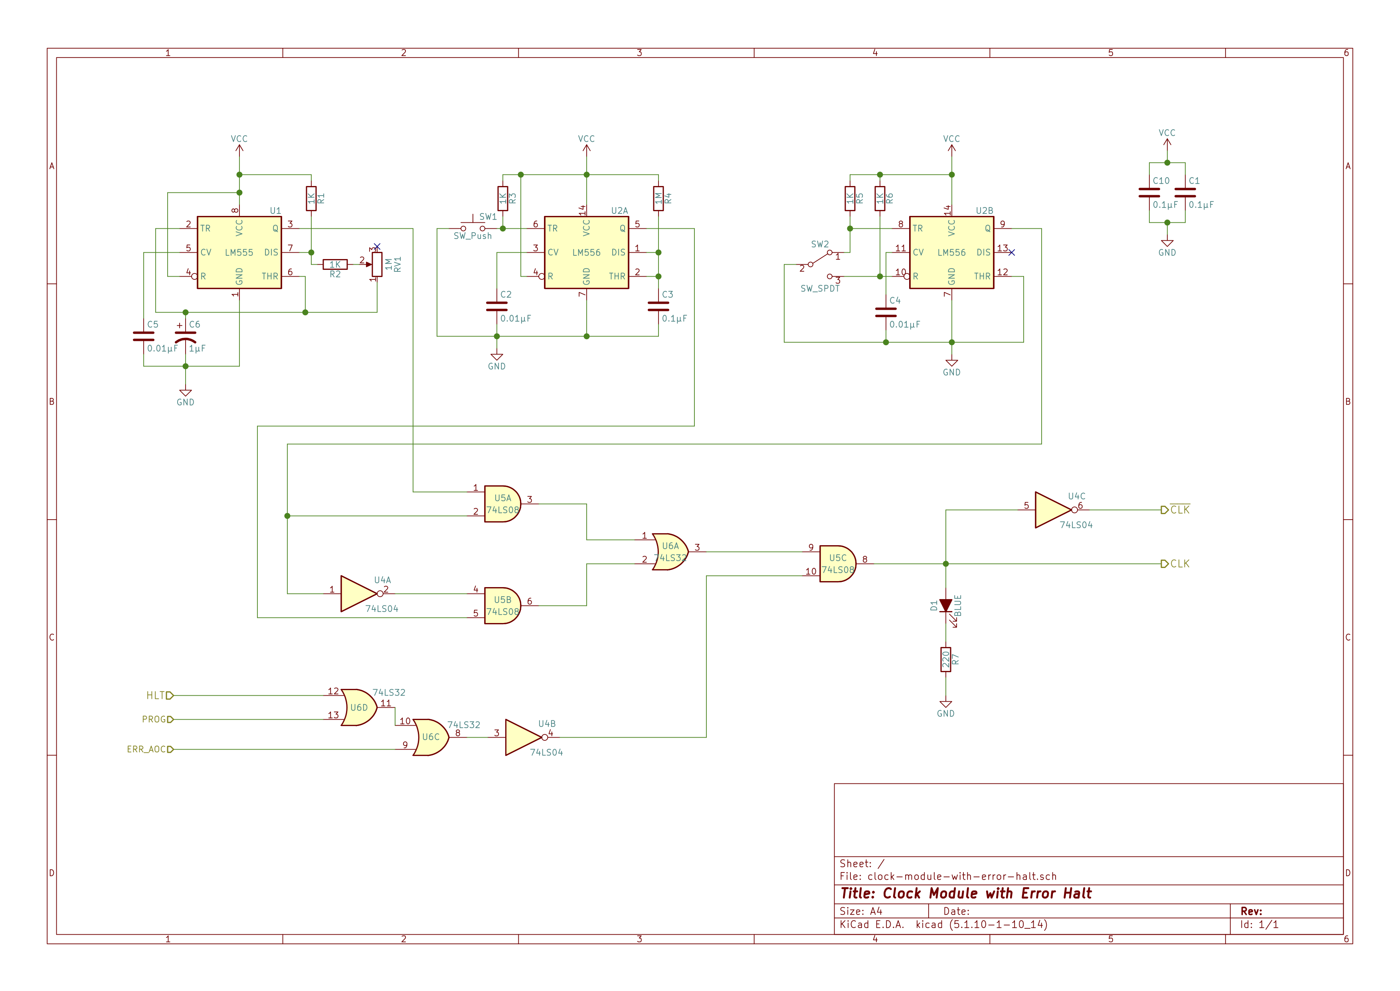
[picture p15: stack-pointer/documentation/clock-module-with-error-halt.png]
Clock Module with Error Halt Schematics


## Control Line Assignment
This project continues to use the control logic design introduced in the [8-Bit Instruction Register project](../instruction-register-8-bit/). The control line assignments are:

| Control Line Position | Bank | Group | Symbol | Notes |
|:-:|:--|:--|:-:|:--|
|1 | Left | Direct | `HILO` | Indicates which byte of a 16-bit register is being operated on |
|2 | Left | Direct | `PCa` | Write program counter value to address bus |
|3 | Left | Direct | `ARa` | Write memory address register value to address bus |
|4 | Left | Direct | `SPa` | Stack pointer address activate |
|5 | Left | Direct | `HLa` | `HL` register address activate |
|6 | Left | Direct | `AOa` | Write Address Offset results to address bus adder |
|7 | Left | Direct | `XTD` | Activate extended instruction bit |
|8 | Left | Direct | `AOi` | Address Offset register in from data bus |
|9 | Left | Direct | `PCi` | Read data bus value into single program counter byte indicated by `HILO` |
|10 | Left | Direct | `IRi` | Read data bus value into instruction register |
|11 | Left | High | `MDi` | Memory device read from data bus |
|12 | Left | High | `Ai` | Read data bus value into `A` register |
|13 | Left | High | `Ti` | Read data bus value into temp register (attached to ALU) |
|14 | Left | High | `HLi` | Read data bus value into single `HL` register byte indicated by `HILO` |
|15 | Left | High | `Ii` | Read data bus value into `I` register |
|16 | Left | High | `Ji` | Read data bus value into `J` register |
|17 | Left | High | `ARi` | Read data bus value into single memory address register byte indicated by `HILO` |
|18 | Left | Low | `PCe` | Activate program counter increment |
|19 | Left | Low | `ARe` | Activate memory address register increment |
|20 | Left | Low |  `SPe` | Iincrements stack pointer value,  or decrements when `SUB` is active |
|21 | Left | Low | `Ie` | Activate register `I` increment, or decrement when `SUB` is active  |
|22 | Left | Low | `Je` | Activate register `J` increment, or decrement when `SUB` is active |
|23 | Left | Low |  `HLe` | `HL` register increment enable |
|24 | Left | Low |  | *unused* |
|25 | Right | Direct | `SUB` | Indicates whether the addition operation should instead be a subtraction operation |
|26 | Right | Direct |  | **Reserved:** `CRY`: input carry flag to ALU operation |
|27 | Right | Direct |  | **Reserved:** ALU `S0` |
|28 | Right | Direct |  | **Reserved:** ALU `S1` |
|29 | Right | Direct |  | **Reserved:** ALU `S2` |
|30 | Right | Direct |  | **Reserved:** ALU `S3` (1 for Shift, Rotate, etc; 0 for ALU) |
|31 | Right | Direct |  | **Reserved:** `INTr` (reset interrupt status) |
|32 | Right | Direct |  | **Reserved:** `INTi` (load interrupt status) |
|33 | Right | Direct | `AP1` | Add 1 to value on address bus |
|34 | Right | Direct | `ABo` | Write the byte indicated by `HILO` of the address bus to the data bus |
|35 | Right | High | `MDo` | Memory device output to data bus |
|36 | Right | High | `Ao`	 | Write contents of `A` register to data bus |
|37 | Right | High | `To` | Temp register (attached to ALU) |
|38 | Right | High |  | *unused* |
|39 | Right | High | `Io` | Write contents of `I` register to data bus |
|40 | Right | High | `Jo` | Write contents of `J` register to data bus |
|41 | Right | High | `∑o` | Write the results of the ALU operation to data bus |
|42 | Right | Low | `SCr` | Resets both the step counter, the offset register,  the extended instruction bit. A step counter overflow needs to do the same thing. |
|43 | Right | Low |  `SPr` | Reset stack pointer to "empty stack" value |
|44 | Right | Low |  `DSs` | Data source input select for 16-bit registers that can load from either address or data bus. LOW is data bus, HIGH is address bus. |
|45 | Right | Low | `∑f` |  Write the ALU flags status to the flags register |
|46 | Right | Low | `If` |  Write register `I` flags status to the flags register |
|47 | Right | Low | `Jf` | Write register `J` flags status to the flags register |
|48 | Right | Low | `HLT` | Halt the system clock |

## Microcode
The "Beta 2" microcode configuration for this project is available [here](./microcode/). I have also visualized the microcode in [a spreadsheet here](https://docs.google.com/spreadsheets/d/18CuuxS1goGVBhtNIjpiRaWfcekohQJE2gV_eJJca56g/edit?usp=sharing).

## Assembly Code
The sister project to this breadboard CPU is my customizable assembler, [BespokeASM](https://github.com/michaelkamprath/bespokeasm). For this update to PUTEY-1 Beta, I've added the concept of "local labels" to the assembly language syntax supported. A local label is a label that is only valid for a limited scope, typical only within a subroutine. This allows you to reuse common label names within subroutines, such as `.loop` and `.end`, without there being a name collision in a broader scope. See [the BespokeASM Wiki](https://github.com/michaelkamprath/bespokeasm/wiki/Assembly-Language-Syntax#label-scope) for more information.

## Project Notes
### Data Sheets
The key ICs used in this project are:

* [74LS169](./datasheets/74LS169.pdf) - Up/down counter used as the basis for both the stack pointer and `HL` register.
* [74LS283](./datasheets/74LS283.pdf) - The 4-bit adders used to add the address offset register value to the address bus value.

### Custom LED Bar Graphs
Given the density of ICs on the breadboard, using the dual inline bar graph LEDs wasn't a viable option in most places I wanted to place status LEDs for this project. So I used the same custom single inline bar graph LEDs I designed and used in my last project. In this project I used by 8P and 16P variants. The custom LED bar graph project [can be found here](https://github.com/michaelkamprath/breadboard-led-bar-graph).

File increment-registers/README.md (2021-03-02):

# Increment Registers for SAP-1
## Project Overview
The goal of this project is to add general purpose registers to the SAP-1 that additionally have the capability to directly increment or decrement the value held in the register and set the carry and zero flag as appropriate when the register value is incremented and decremented. The usefulness of such a register is to more easily implement loops in SAP-1 code. 

A prime example of this is multiplication. In the original SAP-1 instructions set, to implement multiplication you had to implement a loop that counted the number of times the addition operation has occurred (since "multiplication" is just "repeated addition"). However, since there is only one ALU, much of the code written was focussed on moving both the multiplicands and the loops counters in and out of registers A and B, plus a memory location was dedicated to simply hold the value of 1, which is subtracted from the loop variable in each loop. This all be much easier is we had a separate register that could independently handle the loop variable, and then registers A and B can be focussed on the multiplicand addition and much code that pertained to simply moving values in and out of register A can be removed. 

## Design

The countering register is designed around the 74LS169 Up/Down 4-bit Counter. This chip allows values to be latched into it, and then those values can be incremented or decremented when a clock signal is asserted. So given that, the start of the counting register's design is very similar to the original 74LS173-based A and B registers in the original SAP-1. However, because of the additional functionality desired in the counting register, there are a few more ICs involved.

### Dependencies
This project depends on the [Expanded Control Logic project](../expanded-control-logic) already being successfully implemented in the SAP-1. 

### Control Signal Handling
The following control signals are used in each counting register (here notated as if it were the `I` register)

| Control Signal | Active | Description |
|:-:|:-:|:--|
| `Io` | HIGH | Controls whether the current register value is written to the data bus |
| `Ii` | HIGH | When active, when cause the register to update 	 value to the data base value on the rising edge of the clock. |
| `Ie` | HIGH | When active, the register will on the clock's rising edge increment or decrement its current value depending on the state fo the `SUB` control signal |
|  `SUB` | HIGH | Will cause the `Ie` signal to decrement the register value rather than increment it. Note that this is the same `SUB` control signal that the original SAP-1 ALU uses. |
| `CLR` | HIGH | When active, will cause the temporary flags register to clear its state. Note that this does not impact the value held in the counting register. |

One thing to note is that all of the control signals are active HIGH, at least from the perspective external to the register. Internal to the register, those of these signal need to the be inverted in order to comply with a chip's need for the signal to be active LOW. To invert the control signal where needed, 74LS04 inverters are used.

### Flag Handling
#### Zero Flag Detection
In order to detect when a counting register contains a value of zero, a similar design to the original SAP-1 ALU method will be used. The 8 output bits of the register will be fedd into 74LS02 NOR gates in pairs, and the 74LS08 AND gates will be used to check that all NOR gates are asserting `1`, which would indicate all output bits are zero.

#### Carry Flag
The 74LS169 does not have a carry flag that we can use in the same way that the ALU's 74LS283 has a carry flag. The ripple carry out of the 74LS169 is normally high, and assert low when the register value of the 74LS169 is at 15 and the chip is set to count up or at 0 and the chip is set to count down. This behavior allows the ripple carry signal to be used to control the enable state of the next higher 74LS169 when multiple are chained together, but it does not quite represent what a "carry" conceptually means. The carry flag is usually set to indicate that the _results_ of a ALU operation are larger than the original bit width by 1 bit (the carry bit). In contrast, even if the 74LS169's ripple carry output is inverted, it is only set when the register value is at the maximum value (`0b1111`) when in addition mode and at the minimum value (`0b0000`) for subtract mode. 

So, to get a carry flag that behaves like the carry flag in the ALU, we need to simulate it. We would expect the carry flag to be set when the maximum register value of `0b1111` is increment (that is, 1 is added to it) and becomes `0b0000` due to the results of `0b1111` + `0b0001` being the 5 bit value `0b10000`. The register holds the lower 4 bits of that results, and the "carry flag" represents the 5th bit. The status of an increment operation causing this can be detected if the register value is zero, and the register has just completed an increment operation. To detect this, and thus set the carry flag, we must look at the state of things at the end of the clock cycle, as the various value haven't yet propagated through the various gate delays on the rising edge of the clock. The exact state is detected by ANDing together the counting register's zero flag, the counting register's enable control signal (which causes the increment to occur), and the inverted state of the `SUB` control signal (which causes a decrement instead of an increment when the register enable control signal fires). In order to reduce chips used, a 4-input AND gate, the 74LS21, is used with on of its (unused) inputs tied high. 

However, measuring the carry flag state at the end of the clock cycle means that it cannot be collected by the flags register until the next clock cycle, and by that time the state tat resulted in the carry flag being detected is no longer in place. So, a temporary flags register specific to the counting register(s) must be used so as to preserve the flag state until the next clock cycle during which the main flags register can collect the state of the counting register(s)'s flags. For this, a 74LS173 is used with the inverted main clock signal for its input clock.

#### Integration with Flag Register
The challenge with integrating one or more counting registers with the existing flags register is that now multiple modules could set the zero flag or the carry flag. The existing flags register design always reads in the current state of the zero flag or carry flag register from the ALU. When there is only one thing setting the zero flag (for example), this OK. But when multiple things could set the zero flag, signals could collide. Imagine a scenario where the ALU is adding 5 plus 3, but the `I` register isn't being used but contains a value fo zero.  If all sources of the zero flag connected directly to the flags register, the zero flag would be set despite the ALU operation not resulting in zero. A similar example could be constructed for the carry flag. 

To fix this issue, each source of a flag status must be explicitly controlled as to when it can set the flags register status or not. In some ways, Ben Eater's original SAP-1 did this with the `∑f` (or `FI` in the original notation) signal. The flags register only get set when the `∑f` signal is asserted. This can be built on by having a control line for each source of flags t control exactly which component gets to set the flags register at any given moment. So each counting register will have a `If` control signal (here notated for the `I` register) to indicate that its modules flag statuses are to be read into the flags register. This control signal must be used to  enable the 74LS173 register. Basically any module's flags enable line would enable the 74LS173. To control which module's flags status will be read, the flag status signals from each model will be AND'ed with the flags enable control signal for that module, and the results will be OR'ed together by flag type before being fed into the 74LS173. To OR together more than two lines, a 74HCT4075 is used, with has 3-input OR gates on it. 

### Data Sheets

* [74LS169 Up/Down Counter](https://www.jameco.com/Jameco/Products/ProdDS/46906.pdf)
* [74HCT4075 Triple 3-Input OR Gate](https://www.ti.com/lit/ds/symlink/cd74hct4075.pdf)
* [74LS21 Dual 4-Input Positive-AND Gates](https://www.ti.com/lit/ds/symlink/sn74ls21.pdf)
* [74LS02 Quadruple 2-Input Positive-NOR Gates](https://www.ti.com/lit/ds/symlink/sn54ls02-sp.pdf)
* [74LS08 Quadruple 2-Input Positive-AND Gates](https://www.ti.com/lit/ds/sdls033/sdls033.pdf)
* [74LS04 Hex Inverters](https://www.ti.com/lit/ds/symlink/sn74ls04.pdf)
* [74LS173 4-Bit D-Type Registers with 3-State Output](https://www.ti.com/lit/ds/symlink/sn74ls173a.pdf)

### Schematics

#### Updated Flags Register

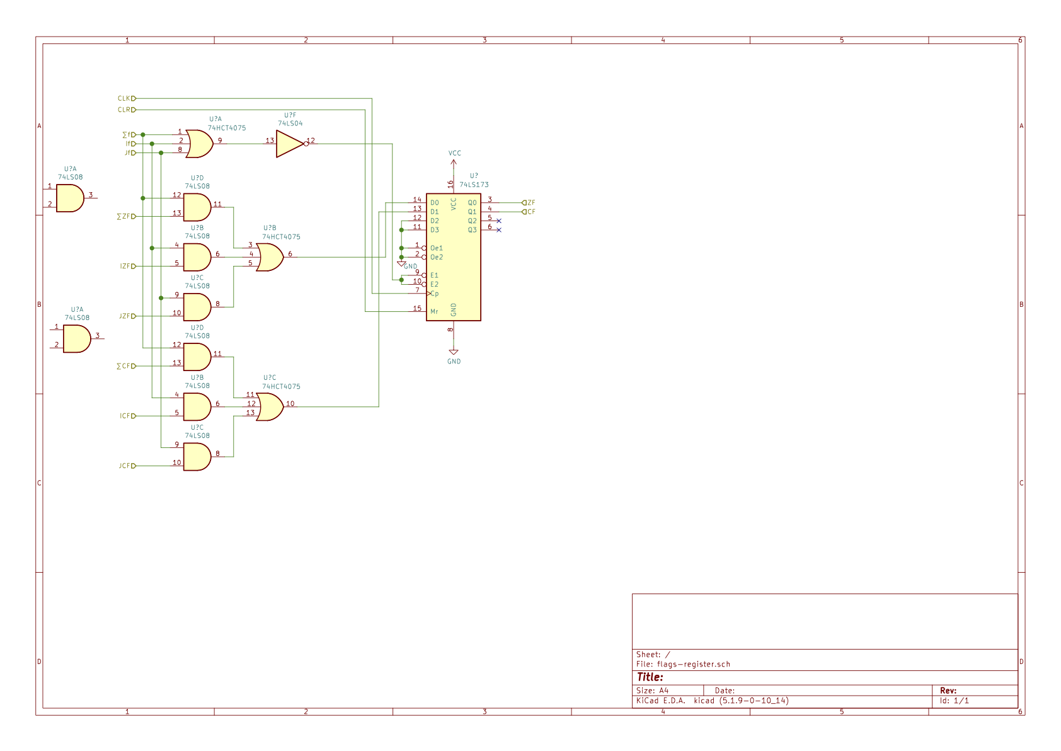
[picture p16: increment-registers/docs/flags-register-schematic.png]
Updated Flags Register


#### Counting Register

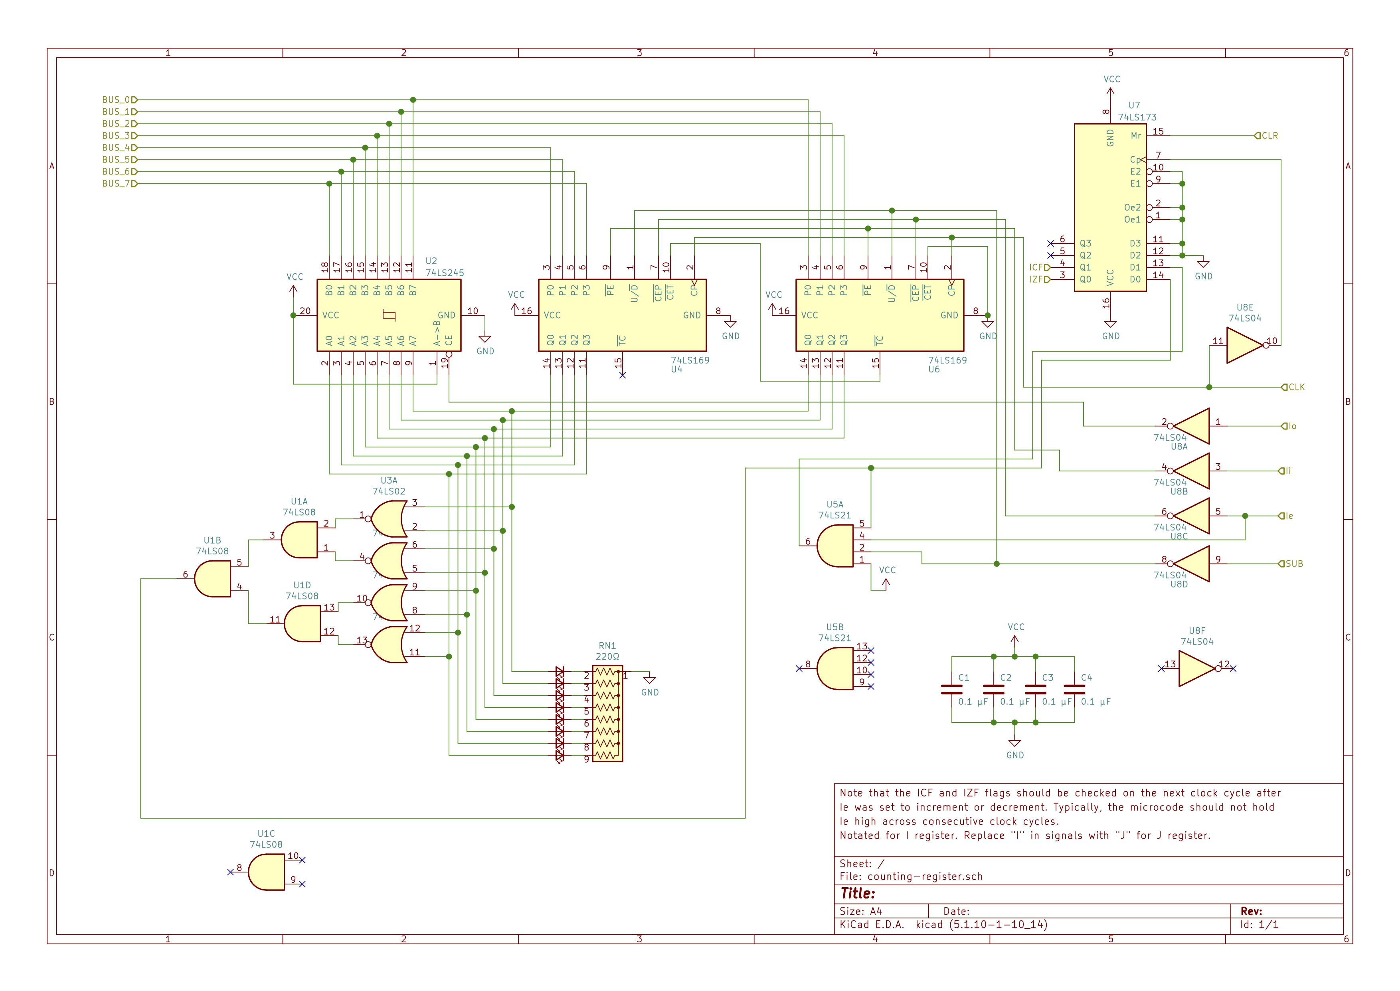
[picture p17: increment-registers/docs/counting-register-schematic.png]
Single Counting Register


### Microcode
On a SAP-1 with the original 16 bytes of RAM, there isn't enough room in the 4 bits used to identify an instruction to enable all instructions that would be possible with the counting registers. So any number of instructions combinations could be defined. The commands you could create using these registers include:

* `INCx` - Increment value in register `x` (`I` or `J`). If incrementing from 255, carry flag and zero is set.
* `DECx` - Decrement value in register `x`. If decrement results in zero, zero flag is set. 
* `LDx` - Load into register `x` the value found at the memory location specified in command parameter.
* `STx` - Store current value in register `x` into memory location in command parameter.
* `MVxy` - Copy (move) value in register `x` to register `y`. For example, `CPAI` would copy the value in register `A` to register `I`. 

Also, for clarity, load immediate instructions will be notated `SETX` where `X` is the register the lower 4 bits if the instruction will be loaded into.

[In this directory](./microcode) is a version of the microcode generator that defines the following instructions in addition to the original SAP-1 instruction set for a SAP-1 set up with two counting registers, `I` and `J`:

* `LDI` - Load into the `I` register the value held in the memory location indicated in the command parameter.
* `MVAI` - Move (copy) the value currently held in the `A` register into the `I` register.
* `MVIJ` - Move (copy) the value currently held in the `I` into the `J` register
* `DECI` - Decrement the value fo the `I` register. Set the zero flag if the `I` register value becomes 0. 
* `DECJ` - Decrement the value fo the `J` register. Set the zero flag if the `J` register value becomes 0. 

The microcode table for this would look like the following. Note that this table indicates what control lines any given counting register control signal should be attached to.

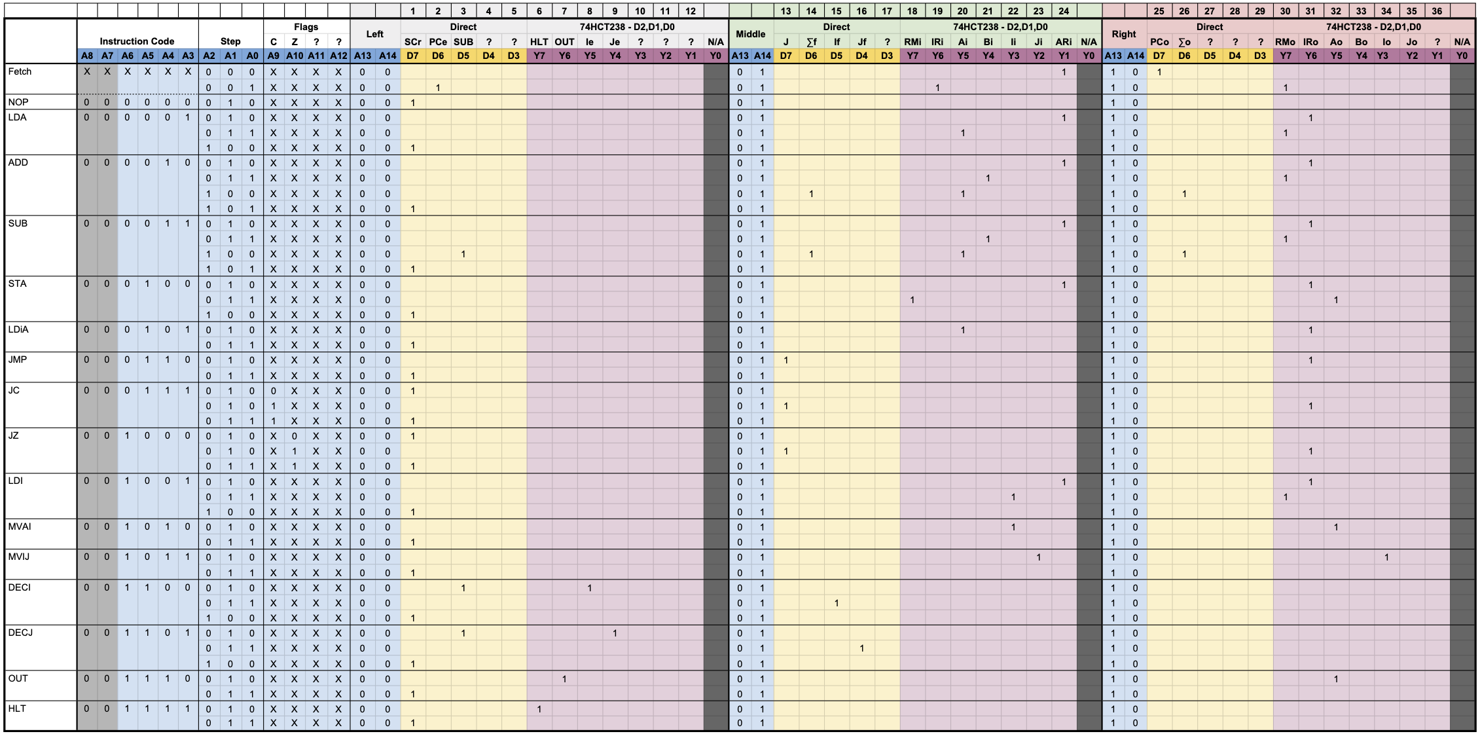
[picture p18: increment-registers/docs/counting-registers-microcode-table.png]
Dual Counting Registers Microcode Table

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

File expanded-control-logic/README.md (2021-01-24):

# Expanded Control Logic
## Project Overview
In order to expand the SAP-1 with more modules, more control lines are needed. However, the SAP-1 as designed by Ben Eater only make 16 control lines available, and all of them are used. This project's goal is to add the ability to drive more control lines to the SAP-1. However, this project does not yet make general use of them (with two exceptions), it is more focussed on upgrading the control logic design to enable later expansion.
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

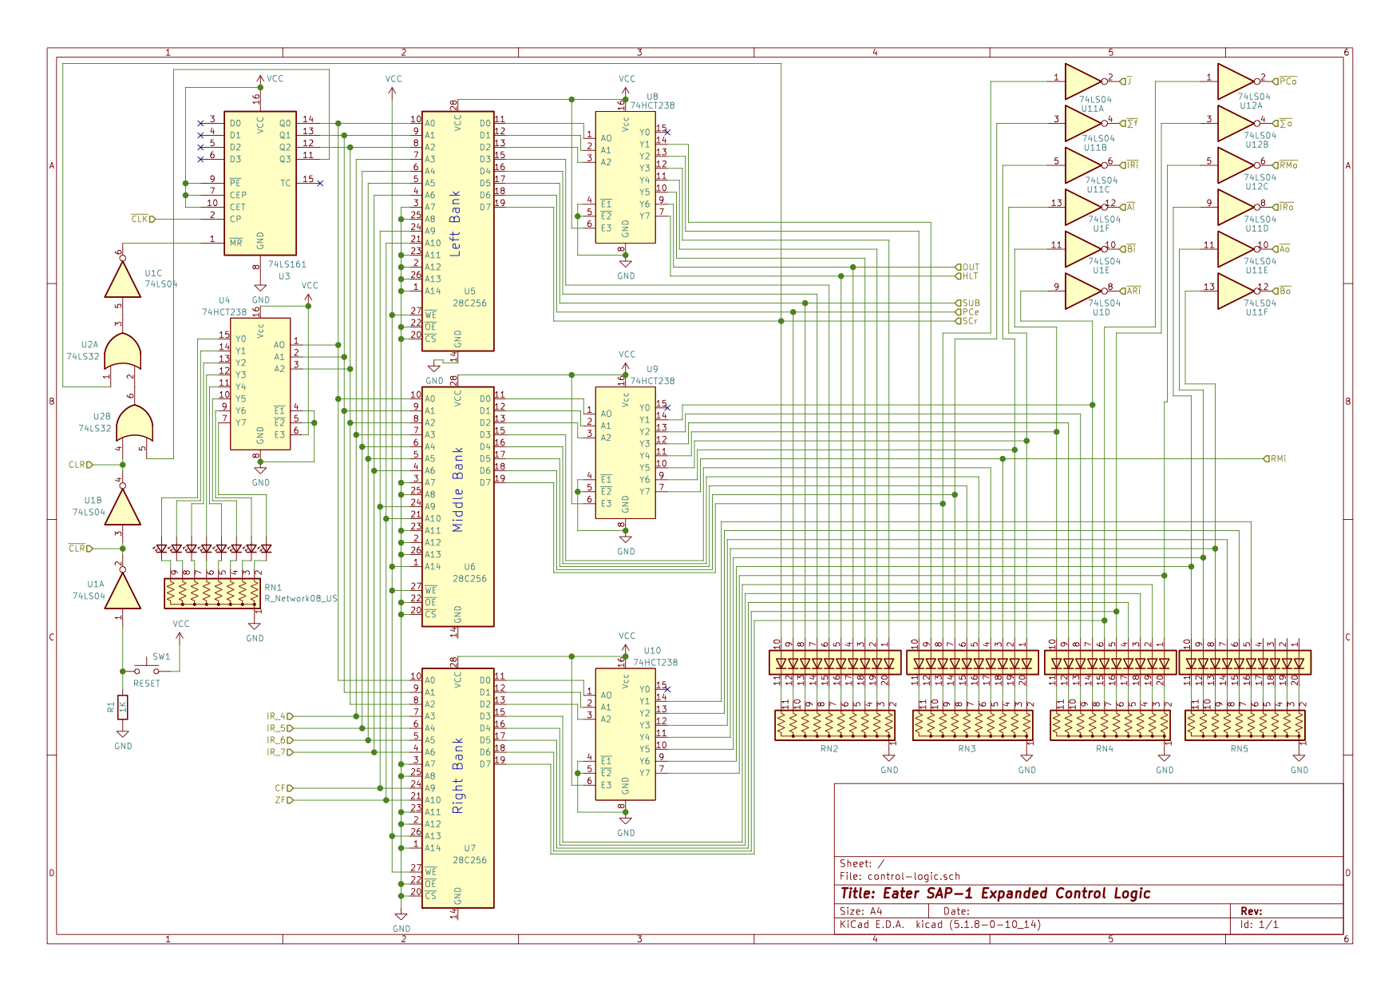
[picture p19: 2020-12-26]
expanded-control-logic/sap-1-expanded-control-logic-schematic.png

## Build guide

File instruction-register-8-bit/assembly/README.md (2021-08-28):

This directory contains the [BespokeASM](https://github.com/michaelkamprath/bespokeasm) configuration file necessary to assemble machine code that will run this project's breadboard computer.

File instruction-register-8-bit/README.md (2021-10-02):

# 8-bit Instruction Register

## Overview
The goal of this project was to do the natural next step of the previous 64K RAM/ROM upgrade and now extend the instruction register to use the full 8 bits, thus enabling at least 256 distinct instructions. To prepare for that, I went ahead and designed an 8-bit instruction set, and in that process, I realized that there were some shortcomings of my breadboard TTL CPU to date, and that I needed to iterate on some of my previous changes. So this project will not only update on the instruction register, but iterate on both the control lines architecture and the memory architecture.

9-Bit Instruction Register (https://youtu.be/Oe24BykYX04)

## Design Goals
1. The primary design goal for this change is to enable 8-bit instructions in my breadboard CPU. Furthermore, I would like to enable the ability to implemented extended instructions at least once, thus bringing the total possible instructions to 511. It's doubtful I'd ever use that full scope allowed by extended instruction, but it's be nice to enable.
    * The motivation for using the full 8-bit instruction space is that the instruction can be "parameterize". The idea here is that the first few bits in the instruction byte indicate the actual operation, while the subsequent bits pertain to specific operands. Constructing instruction values in this way will make it easier to enable an assembler for my breadboard CPU's instruction set.
2. Update the control logic to enable the full 8-bit instructions. Furthermore, In preparation for projects yet to come, rework the control logic to also enable more control lines.
    * My prior expansion of the control lines was not forward looking enough and was only sized for 6-bit instructions. As a result, the EEPROMs selected do not have enough address lines to enable 8-bit instruction, and 4 flag lines, and 3 bit steps, and and a few other inputs to the control logic I am thinking about.
3. Iterate on the memory module to enable memory mapped I/O. While this project will not yet fully use the memory mapped I/O, I wanted to put the components for it in while I was restructuring things to address the needed changes in control logic.
    * If I didn't introduce memory mapped I/O into the design, I would need to add more control logic and customize the microcode for every peripheral I would like to add, and a corresponding instruction to use that peripheral. This approach will get out of hand rather soon, if it hasn't already.
4. When designing the implementation of the goals above, be forward thinking about the eventual need to add a stack pointer, upgrade the ALU, add a more sophisticated output display, and add several other capabilities to the system.

# Design

## Instruction Set
To understand the architecture I need to be building towards, I found designing an instruction set be be a very informative exercise. The general approach was to define prefixes to define the type of operation, then bit parameters are appended to the prefix to define variations on that operation.

A good example of this is the `mov` instruction, which is used to copy a value from one location to another. If, for example, we want to copy the value currently in register `A` to register `I`, the assembly instruction would look something like this:
```asm
mov i,a
```
To indicate this in the 8-bit instruction code, there would be a bit prefix to indicate a `mov` instruction, then two bit parameters to indicate both the destination and source registers. For example, something like this:
```
    Byte 0
  ==========
  01 011 001
  -- --- ---
   |  |   |
   |  |   +------------ The byte code 110 indicating the second operand is register A
   |  +---------------- The byte code 011 indicating the first operand is register I
   +------------------- The byte code 01 indicating the mov instruction
```
This then produces a single 8-bit value, `b01011001`, which represents the entire `mov i,a` instruction, and this instruction can then be programmed into the microcode. 

This approach can be extended to instruction that require numeric parameters. For example, consider this `mov` instruction place the immediate value `$F0` into register `A`:
```asm
mov a,$F0
```
In addition to the byte code for the instruction, the machine code will need the second operand's immediate value added to indicate the value. In this case, the bit parameter for the second operand would indicate that an immediate value would follow the instruction's byte, and the overall machine code would be constructed something like this:

```
    Byte 0    Byte 1
  ========== ========
  01 001 111 11110000
  -- --- --- --------
   |  |   |     |
   |  |   |     +------ The second operand's operand value of $F0
   |  |   +------------ The byte code 111 indicating the second operand is a direct value
   |  +---------------- The byte code 001 indicating the first operand is register A
   +------------------- The byte code 01 indicating the mov instruction
 ```

So to flesh out this approach, one just needs to define the instruction prefix bits and the set of operand parameter bits, and which operands would require trailing byte code values. There will be some instructions that do not require operand parameters, such as `HLT`, and some may only require 1 operand parameter.

What came from this is an approach of defining "operand sets" that indicate the various values that can be the operand parameter for any given set of instructions. An important aspect of these operand sets is that depending on the type of instruction, the operand parameter bits are a set width, and thus the set of possible operand values have a set cardinality. For an 8-bit instruction, this limits the design of the actual CPU. For example, you could have a large number of registers in the CPU, but you may not be able to identify them in instructions given the limited bit width afforded in an 8-bit instruction. Of course, this issue could be mitigated by using an 16-bit instruction, but that would require a 16-bit instruction register and the ability for the control logic to be driven by 16-bit instruction. I take an alternate approach for expanding the instruction space beyond what a single 8-bit word affords by using an "extended instructions" approach I describe below.

For the breadboard computer I intend to build, the types of operands sets I will need the following operand sets:

* **8-bit Value Source** - Represents a location from where an 8-bit value could be copied from. Examples include registers, immediate values, and values at specified memory locations. In this build, the values are:
    * `A` register
    * `I` register
    * `J` register
    * Value at specific memory address
    * Value at the memory address contained in the `MAR`
    * Immediate value
* **8-bit Value Destination** - Represents a location to where an 8-bit value could be copied to. Similar to the set of 8-bit Value Sources, but would not include an immediate value destination. In this build, the values are:
    * `A` register
    * `I` register
    * `J` register
    * Value at specific memory address
    * Value at the memory address contained in the `MAR`
* **16-bit Value Source** - These are sources where a 16-bit memory address value can be found. The most common one will be immediate values and 2-byte values that start at an indicated address. In this build, the values are:
    * `MAR` memory address register
    * Value at the memory address contained in the `MAR`
    * Two byte value starting at specific memory address
    * Immediate value
* **16-bit Value Destination** - These are locations where a 16-bit memory address value can be placed. In this build, the values are:
    * `MAR` memory address register
    * Value at the memory address contained in the `MAR`
    * Value at specific memory address
* **Incrementable Destination** - The set of destinations that can be directly incremented or decremented. Examples include [the increment registers I added to the CPU a few projects back](../increment-registers/). In this build, the values are:
    * `I` register
    * `J` register
    * `MAR` memory address register
* **Address Source** -  A subset of 16-bit value sources that can be used to indicate a memory location and have their value written to the address bus.
    * Two byte value starting at specific memory address
    * Immediate value

A future iteration of this CPU could add 16-bit ValueSource/Destination type operands.

These concepts of types of value sources and destinations requires us to be more rigorous about the concept of "addressing modes". Loosely speaking, an [addressing mode](https://en.wikipedia.org/wiki/Addressing_mode) is a method for accessing data on the CPU. With this iteration of the CPU, the following addressing modes are used:

* **Immediate** - A constant value that is encoded into the instruction machine code.
* **Indirect** - A value that resides at a memory address indicated by a constant value encoded int the instruction machine code.
* **Register** - A value that resides in a register, such as register `A`.
* **Register Indirect** - A value that resides at a memory address contain in a register.

The addressing modes can all be used to create an operand set. For example, the set of all "8-bit value sources" consists of the `A`, `I`, and `J` registers; values that reside at a given memory address with that memory address being either an immediate value or a value residing in a register (such as the `MAR`), or a constant (immediate) value incorporated into the instruction machine code. Each addressing mode leverages its own microcode pattern to be able to mode data around the CPU.

Then, the definition of the instruction set begins to look like this:

| Instruction | Instruction Bit Prefix | Extended? | Operand 1 Type | Operand 2 Type | Description |
|:-:|:--|:-:|:-:|:-:|:--|
| `nop` | `b00000000` | No | - | - | No operations |
| `hlt` | `b00000001` | No | - | - | Stop the system clock |
| `jmp X` | `b001011xx` | No | Address Source | - | Set program counter to 16-bit value found at `X` |
| `jc X` | `b001100xx` | No | Address Source | - | Set program counter to 16-bit value found at `X` if carry flag is set |
| `jz X` | `b001101xx` | No | Address Source | - | Set program counter to 16-bit value found at `X` if zero flag is set |
| `jeq X,Y` | `b010xxyyy`| No | Address Source | 8-bit Value Source | Set program counter to 16-bit value found at `X` if value in register `A` is equal to 8-bit value found at `Y` |
| `mov X,Y` | `b10xxxyyy`| No | 8-bit Value Destination | 8-bit Value Source | Copy 8 bit value at source `Y` into destination `X` |
| `add X` | `b10111xxx` | No | 8-bit Value Source | - | Add value found at `X` to value in Register `A` |
| `sub X` | `b11001xxx` | No | 8-bit Value Source | - | Subtract value found at `X` from value in Register `A` |
| `inc X` | `b110110xx` | No | Incrementable Destination | - | Increment the value currently found n `X` |
| `dec X` | `b110111xx` | No | Incrementable Destination | - | Decrement the value currently found n `X` |
| `swap X,Y` | `b00xxxyyy` | **Yes** | 8-bit Value Destination | 8-bit Value Destination | Swap the value found at each 8-bit value source, `X` and `Y`. Only unequal register, register indirect, and indirect addressing modes can be used as operands. |
| `mov2 X,Y` | `b01xxxyyy` | **Yes** | 16-bit Value Destination | 16-bit Value Source | Copy 16 bit value at source `Y` into destination `X`.

Of course, this is just a starting point and does not represent the full instruction set, but it already enables a much richer set of instructions than the original 4-bit instruction codes previously used. One thing I intend to do is not define meaningless instructions, such as `mov a,a`, and instead use the bit code that would have been used to construct the meaningless instruction for something else.

### Extended Instructions
One thing that I realized when I was developing the full instruction set design is that 256 instructions is not really that much when you start to factor in combinatorics of all registers, indirect addresses, and direct values, the instruction set and fill up rather quick. So, I wanted to introduce the concept of extended instructions. These would be instructions that take two bytes to identify rather than just one. The benefit here is that the instruction set has more bits to allow for instructions with high cardinality operand sets. For example, the `mov` instruction takes up 25% of the 8-bit instruction space to enable all the possible combinations of operands. To create a similar type instruction, such as a `swap` instruction that allows the wapping of values between any register and/or memory location, there is likely not enough remaining instruction space to account for all the possible operand combinations after other instructions, such as jumps and ALU operations, are implemented. An extended instruction space could enable the creation of more such high cardinality instructions.

What I developed isn't very sophisticated. In the approach I developed, the first byte is an `XTD`, which is in the "normal" instruction set only flags that the next byte is an instruction from the extended set. To make this work, the instruction register needs to maintain an extended flag that indicates to the microcode whether the instruction is a "normal" or "extended" instruction.  This flag is implemented as a flip flop that gets set by a control line activated by the `XTD` instruction. This flip flop drives an address line into the microcode ROMs. Then from this point the next byte is loaded  is treated as a new instruction, but since the `XTD` bit is set on the microcode ROM address lines, the next byte can be a completely different instruction even if its bit pattern matches a "normal" instruction. The flip flop gets reset at the end of every instruction when the `SCr` (Step Counter Reset) control line is activated.

## Instruction Register
The instruction register design is simply two 74LS173 4-bit flip flops with the addition of a single flip flop for the `XTD` bit using a 74LS74. Collectively these drive nine address lines of the microcode ROMs.

Furthermore, a step counter is implemented with 74LS161 counter. The step counter is driven by the `/CLK` signal, and only three of its binary output are connected to address lines of the microcode ROMs, resulting in a maximum of 8 steps per instruction.

Finally, the step counter reset circuit has a couple enhancements. As with before, it is driven either the `CLR` signal, the `SCr` signal, or exceeding the maximum allowed step. However, the when the step counter reset occurs, it also resets the `XTD` flip flop, unsetting the `XTD` bit if it was set. The second change is more with the `CLR` signal generation. As with before, this signal is generated by a push button. However, a simple power-on reset circuit is added to generate a reset signal when the computer is first powered so that the computer starts up in a a reset state. This signal is generated by a simple RC circuit, and as currently designed holds a reset signal for about 0.2 seconds after power on.

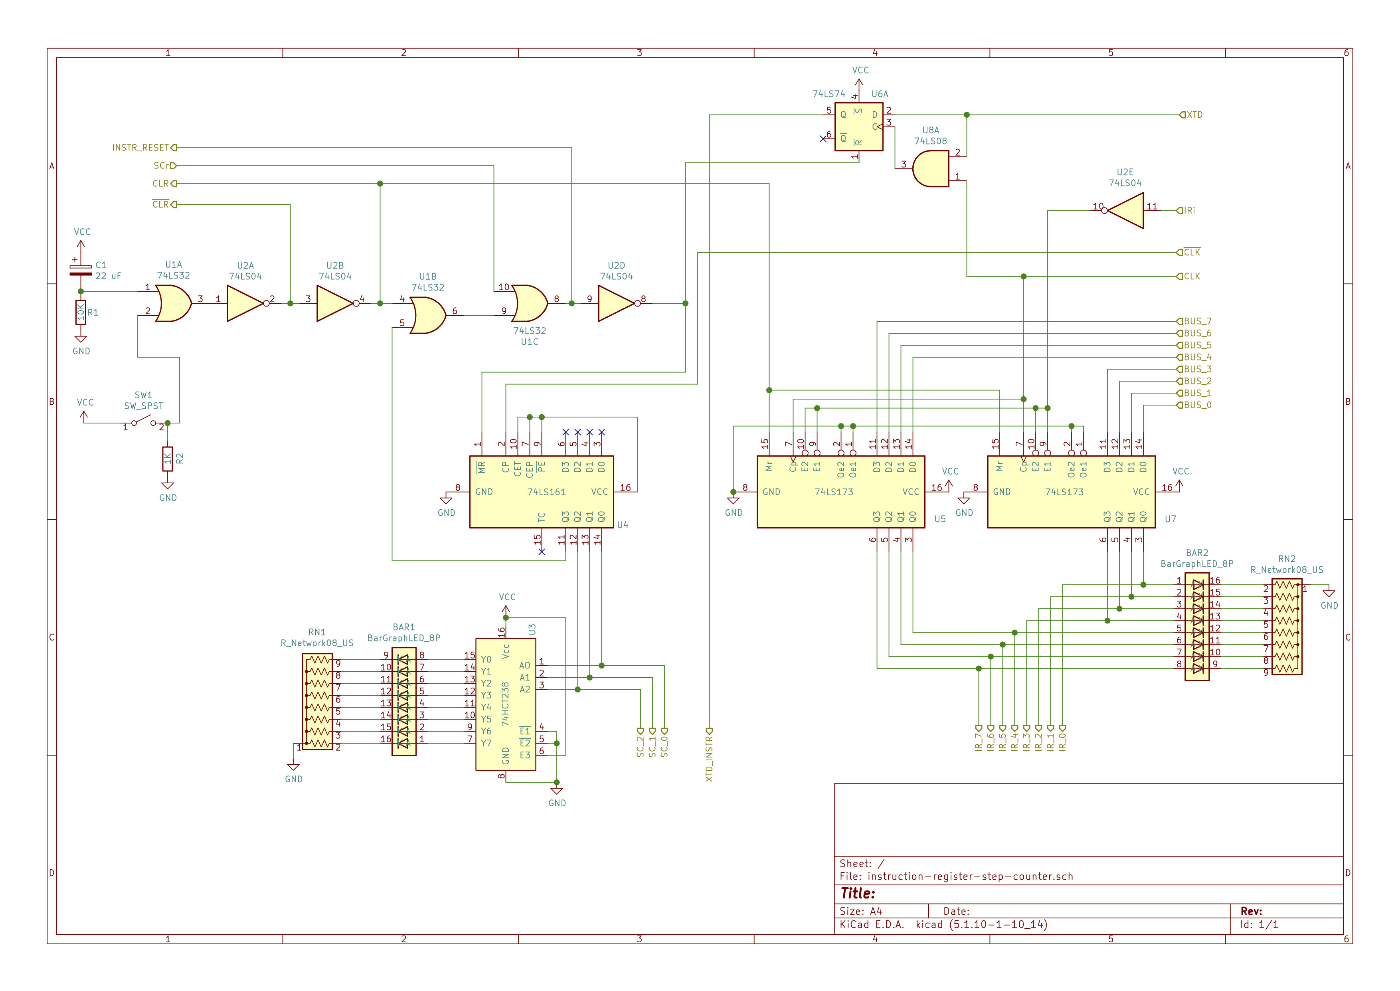
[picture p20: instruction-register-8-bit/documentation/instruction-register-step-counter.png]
Instruction Register and Step Counter


## Control Logic
When designing the full instruction set I wanted to build towards, including support for a stack pointer and a more capable ALU, one thing stood out rather quickly: the additional control lines I created in [a prior project](../expanded-control-logic/) were not sufficient. While I could add another EPROM to that design, the number of EEPROMs was getting a bit excessive. But using EPROMs for driving the combinational logic is a great choice, especially for a project intended for hacking. So I reconsidered how to make EPROM-driven control logic design. I came across [the `27C4096` UV-erasable EPROMs](./documentation/AM27C4096.pdf). These EPROMs hold 4 Mb of 16 bit words. That means there are 18 address lines and 16 data lines. So these chips not only increase the number of input signals to the control logic, but also reduce the number of chips needed for the same number of control lines.

The number of control lines I wanted to add was 48, which could easily be done with three `27C4096` EPROMs. However, I would have to either dedicate 2 address lines to ROM identification, or program each ROM differently. I din't want to do either of those, so I came up with a design that uses two `27C4096` ROMs and four `74HCT238` 3-to-8 line decoders. This gives me 48 control lines, with 28 of the lines being split between 4 banks of `74HCT238` decoders. The design plans on the following usage for address lines:

* 3 lines for the step counter
* 8 lines for the instruction register
* 1 line for the `XTD` bit controlling extended instructions
* 4 lines for status flags, 2 of which are future expansion
* 1 line for future expansion
* 1 line for chip identification so both ROMs can be programmed identically

So this leaves me 3 address lines for future expansion, 2 of which are already earmarked for flags from a future ALU upgrade.

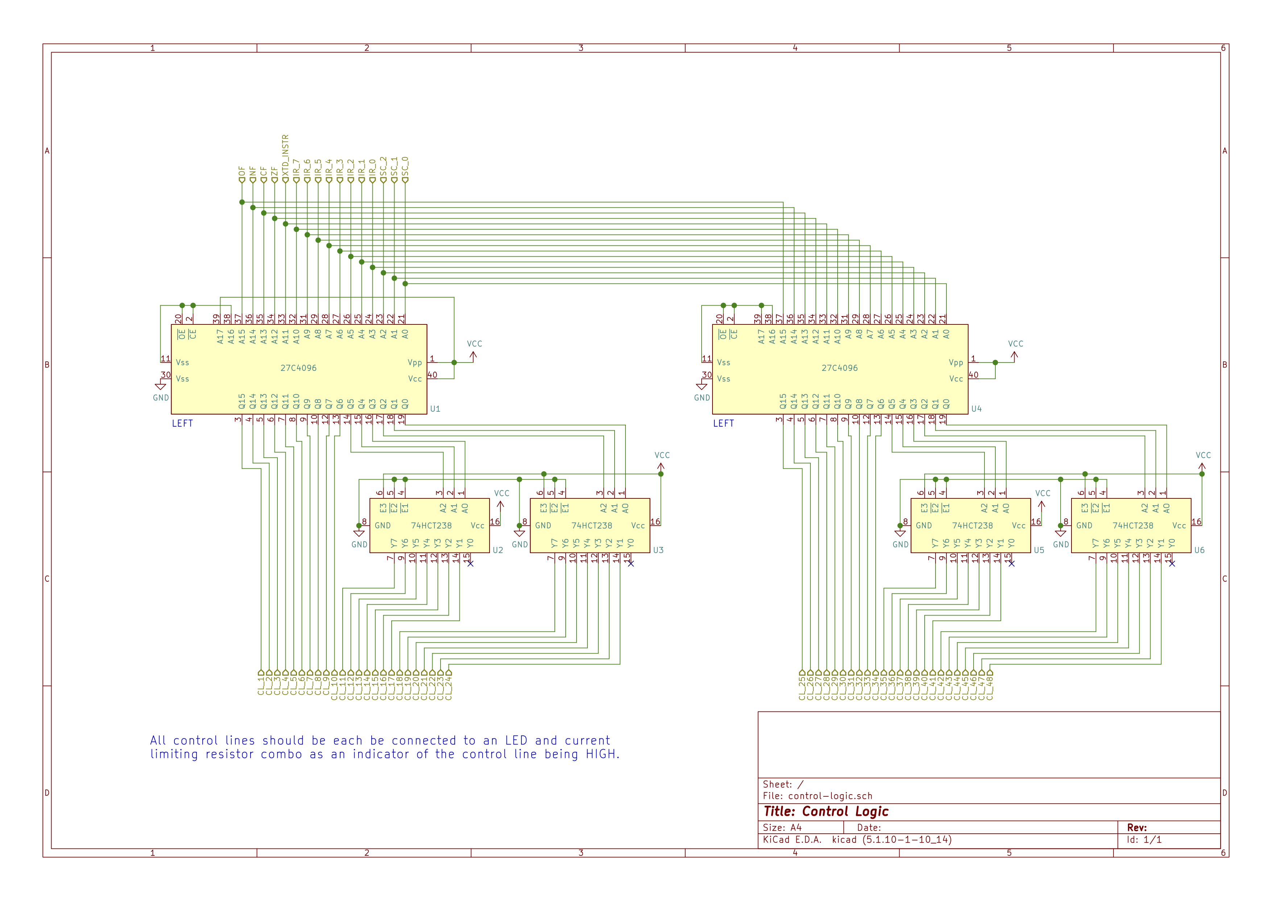
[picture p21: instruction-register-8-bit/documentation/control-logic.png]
Updated Control Logic


### Control Line Assignment
My schematic for the control logic change does not indicate which control line belongs to which control signal. I did that on purpose, leaving control line assignment to be something I manage outside of the schematic (at least for now). So I document it below, including indicating intended future uses. Control line assignment is fairly arbitrary, but I did try to group the register outs with each other on the same `74HCT238` group since only one can be active at the same time. Same is true for the register in control lines. In this table, "Bank" indicates which EPROM the control line is associated with, and "Group" indicates whether the line emanates from the EPROM itself ("Direct") or one of the two `74HCT238`s ("High" and "Low", depending on address lines).

| Control Line Position | Bank | Group | Symbol | Notes |
|:-:|:--|:--|:-:|:--|
|1 | Left | Direct | `HILO` | Indicates which byte of a 16-bit register is being operated on |
|2 | Left | Direct | `PCa` | Write program counter value to address bus |
|3 | Left | Direct | `ARa` | Write memory address register value to address bus |
|4 | Left | Direct | | **Reserved:** `SPa`: stack pointer address activate |
|5 | Left | Direct | | **Reserved:** `NXa`: `NX` register address activate |
|6 | Left | Direct | | **Reserved:** `AOa` (write Address Offset results to address bus) |
|7 | Left | Direct | `XTD` | Activate extended instruction bit |
|8 | Left | Direct | | **Reserved:** `AOi` (Address Offset In) |
|9 | Left | Direct | `PCi` | Read data bus value into single program counter byte indicated by `HILO` |
|10 | Left | Direct | `IRi` | Read data bus value into instruction register s|
|11 | Left | High | `MDi` | Memory device read from data bus |
|12 | Left | High | `Ai` | Read data bus value into `A` register |
|13 | Left | High | `Ti` | Read data bus value into temp register (attached to ALU) |
|14 | Left | High |  | **Reserved:** `NXi`: Read data bus value into single `NX` register byte indicated by `HILO` |
|15 | Left | High | `Ii` | Read data bus value into `I` register |
|16 | Left | High | `Ji` | Read data bus value into `J` register |
|17 | Left | High | `ARi` | Read data bus value into single memory address register byte indicated by `HILO` |
|18 | Left | Low | `PCe` | Activate program counter increment |
|19 | Left | Low | `ARe` | Activate memory address register increment |
|20 | Left | Low |  | **Reserved:** `SPe`: Stack pointer increment enable |
|21 | Left | Low | `Ie` | Activate register `I` increment, or decrement when `SUB` is active  |
|22 | Left | Low | `Je` | Activate register `J` increment, or decrement when `SUB` is active |
|23 | Left | Low |  | **Reserved:** `NXe`: `NX` register increment enable |
|24 | Left | Low |  | *unused* |
|25 | Right | Direct | `SUB` | Indicates whether the addition operation should instead be a subtraction operation |
|26 | Right | Direct |  | **Reserved:** `CRY`: input carry flag to ALU operation |
|27 | Right | Direct |  | **Reserved:** ALU `S0` |
|28 | Right | Direct |  | **Reserved:** ALU `S1` |
|29 | Right | Direct |  | **Reserved:** ALU `S2` |
|30 | Right | Direct |  | **Reserved:** ALU `S3` (1 for Shift, Rotate, etc; 0 for ALU) |
|31 | Right | Direct |  | **Reserved:** `INTr` (reset interrupt status) |
|32 | Right | Direct |  | **Reserved:** `INTi` (load interrupt status) |
|33 | Right | Direct |  | *unused* |
|34 | Right | Direct | `ABo` | Write the byte indicated by `HILO` of the address bus to the data bus |
|35 | Right | High | `MDo` | Memory device output to data bus |
|36 | Right | High | `Ao`	 | Write contents of `A` register to data bus |
|37 | Right | High | `To` | Temp register (attached to ALU) |
|38 | Right | High |  | **Reserved:** `NXo`: Write the byte indicated by `HILO` of the `NX` register value to data bus |
|39 | Right | High | `Io` | Write contents of `I` register to data bus |
|40 | Right | High | `Jo` | Write contents of `J` register to data bus |
|41 | Right | High | `∑o` | Write the results of the ALU operation to data bus |
|42 | Right | Low | `SCr` | Resets both the step counter, the offset register,  the extended instruction bit. A step counter overflow needs to do the same thing. |
|43 | Right | Low |  | **Reserved:** `SPr`: Stack Pointer reset |
|44 | Right | Low |  | **Reserved:** `AOr`: Address Offset register reset |
|45 | Right | Low | `∑f` |  Write the ALU flags status to the flags register |
|46 | Right | Low | `If` |  Write register `I` flags status to the flags register |
|47 | Right | Low | `Jf` | Write register `J` flags status to the flags register |
|48 | Right | Low | `HLT` | Halt the system clock |

## Memory Map
As I point out above, if I plan out where I would like to take this breadboard TTL CPU, there is a growing need for control lines. I could certainly add more control lines by adding more EPROMs in the control logic, but at some point that approach becomes cumbersome.  Another approach to handing the need for more control lines is to do something called memory mapping. I won't go into into a detailed description of memory mapping, as there are plenty of [resources](https://en.wikipedia.org/wiki/Memory-mapped_I/O) [online](https://en.wikipedia.org/wiki/Memory-mapped_file) for that. But at a high level, what memory mapping does is cause a certain device or module to be activated when a certain address or range of addresses are accessed for reading or writing. This has the effect of not needing to complicate you control logic and microcode of the CPU. Instead, if you want to write a value to a memory mapped module, all you do is write that value to a specific memory address that is mapped to that module and instead of write the value to RAM, the value is written to that module.

### Memory Mapped I/O
The implementation of this is rather straight forward, but it does require you to specify what address range is going to be dedicated to memory mapped devices, as it will be unusable by the RAM or ROM. I decided to make a 2K memory map range at the top of my current ROM address space. This means any access to address values between `0x7800` and `0x7FFF` means you are actually accessing a memory mapped device and not the ROM. This also means the amount of usable ROM has been reduced to 30K. More sophisticated memory map schemes could be developed that leverage the full contents of the ROM or RAM chips, but that would require the usage of more address lines than 16. 

This design would lead to a memory map that looks like this:
```
    0xFFFF  +-----+
            |     |
            | RAM | <-- Variables, programs
            |     |
    0x8000  +-----+
            | MAP | <-- Memory Mapped I/O
    0x7800  +-----+
            |     |
            | ROM | <-- Boot code, programs
            |     |
    0x0000  +-----+
```
It's useful to plan forward a bit more to understand what other things I might be doing that would impact my CPU's memory map. A notable item is the (future) addition of a stack pointer. This will point to a range of memory at the top of the RAM. Strictly speaking, a stack pointer is not the same thing as memory mapped I/O, but it is a specialized access to the memory and thus worth considering. Another item is the fact that at least in the design I am currently using, my RAM chip, the [UM61512A](../ram-rom-upgrade/datasheets/UM61512A.pdf), contains a total of 64K of addressing 8 bit words, and we are currently only using 32K of those words. It should be possible to make that additional 32K of RAM accessible in some manner to the CPU. With these considerations, a hypothetical memory map could look like: 

```
   0x17FFF  +-----+
            |     |
            | RAM | <-- Unused "High" RAM
            |     |
   0x10000  +-----+
            | RAM | <-- Stack
    0xF000  +-----+
            |     |
            | RAM | <-- Variables, programs
            |     |
    0x8000  +-----+
            | MAP | <-- Memory Mapped I/O
    0x7800  +-----+
            |     |
            | ROM | <-- Boot code, programs
            |     |
    0x0000  +-----+

```

In this project, the first memory map shown above is what will be implemented. However, I will also lay the groundwork to later enable something closer to the hypothetical memory map.

### Separate RAM and ROM Modules
As I designed the implementation of the memory mapped I/O described above, one thing that stood out is that design approach I took in [my last project to implement the 16 bit memory addressing](../ram-rom-upgrade/) is not flexible enough to easily implement a memory map controller. The core issue is that as I implemented it, the RAM and ROM are basically implemented as a single module, making opaque to the rest of the computer whether an address pertains to RAM or ROM. While this them to look like one device to the rest of the CPU, it make things a bit more complicated to wedge in the concept of memory mapped I/O.

Ideally we want the address being written to the address bus to indicate what memory device should be active per the defined memory map, and generate a control line that tells that memory device to be active or not.  In some ways I did implement this in my last design as address line `A15` was effectively the control signal indicating whether RAM or ROM should be active. Once you have a way to active specific modules based on the memory address, then the only control lines needed to emanate from the microcode are `MDo` (memory device out) and `MDi` (memory device in). In some other CPU design they refer to these control lines of `MEM_READ` and `MEM_WRITE`.

This approach just became easier to implement if the RAM and ROM functions of the CPU we more cleanly separated from each out there being an unambiguous enable line for each of the RAM and ROM modules. So with this project I redo the RAM and ROM module to turn it into separate RAM and ROM modules.

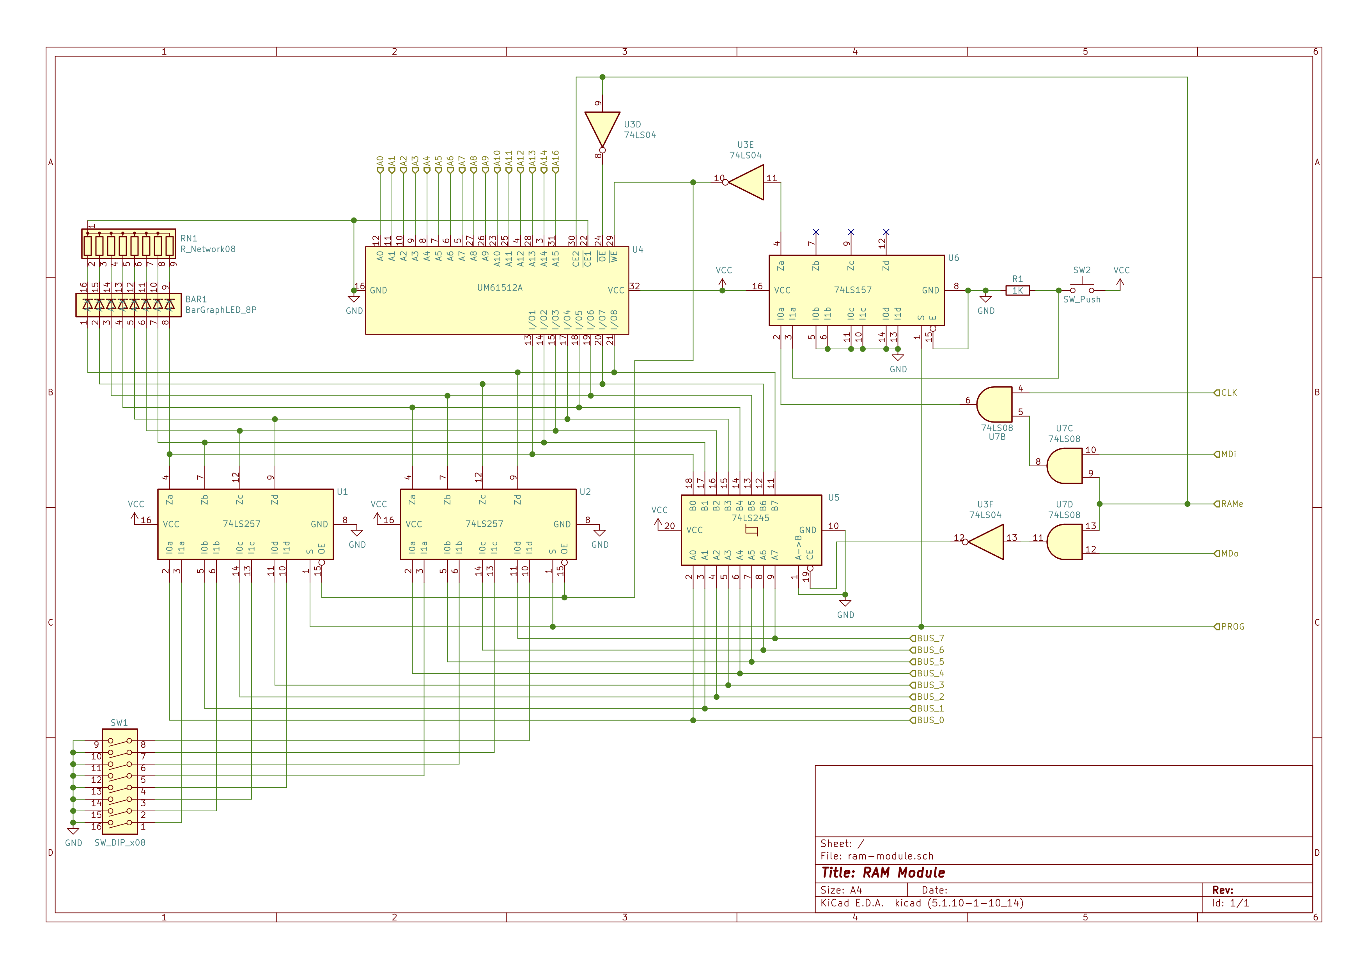
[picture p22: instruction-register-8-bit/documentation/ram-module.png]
RAM Module


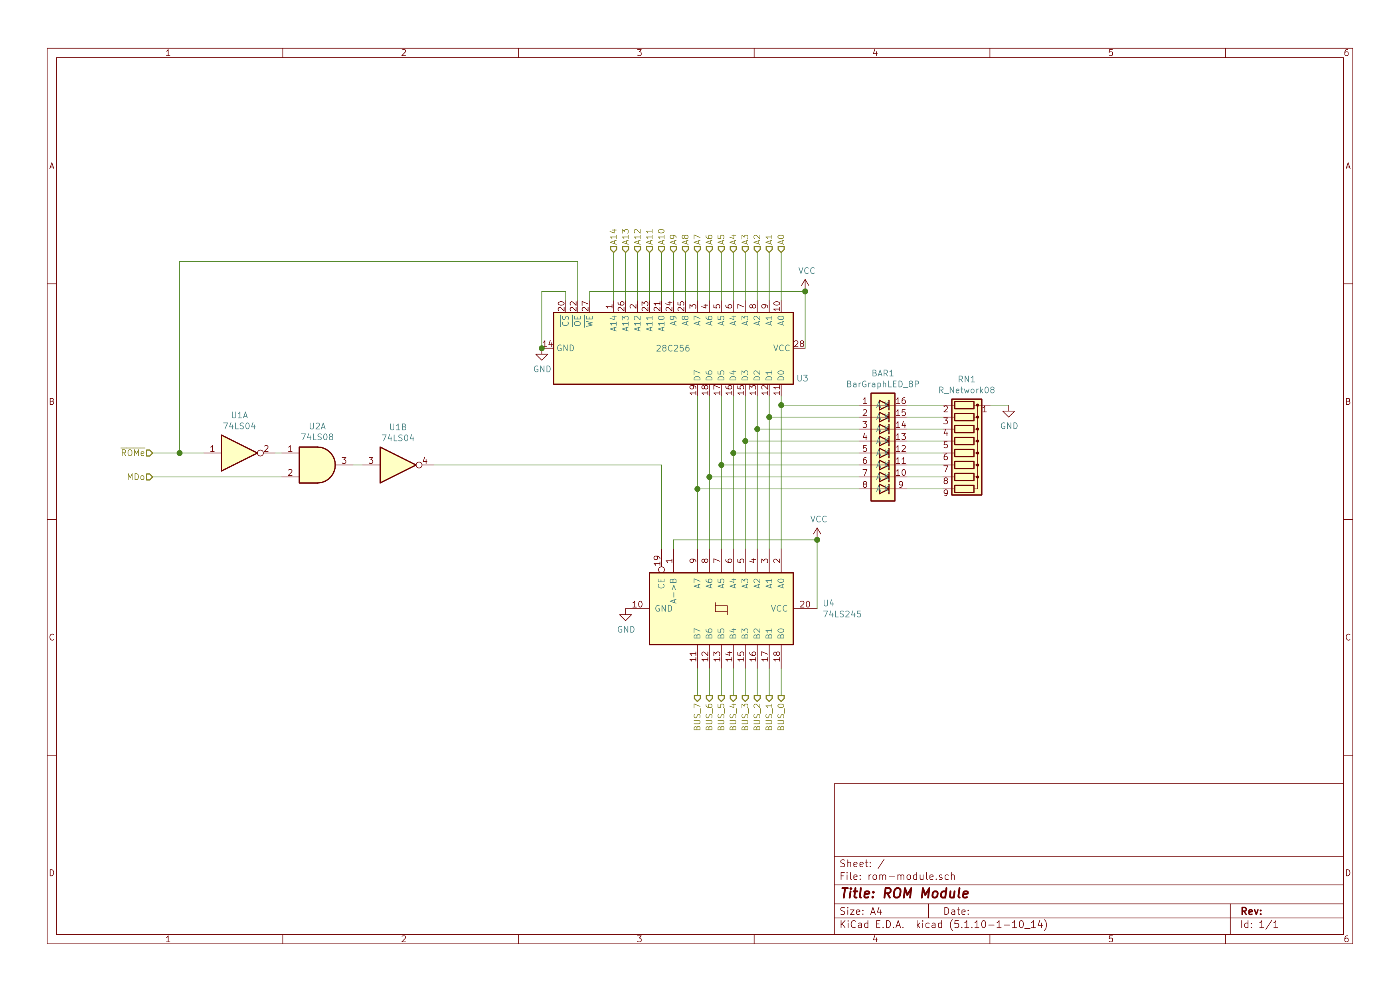
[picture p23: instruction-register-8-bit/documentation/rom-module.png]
ROM Module


### Memory Map Controller
The basic idea behind a memory map controller is to activate a specific component when the address value on the address bus is at a specific value or range of values. This is accomplished by combination logic. Given the memory map design I specify above where the addresses in the range `0x7800` to `0x7FFF` would be mapped to a memory map device, detecting this state is each accomplished by ensure addressing line A15 is low and all of address lines A11 through A14 are high. Detecting when these 4 address lines are high is easily done with a 74LS21 quad-input AND gate. However, the the purpose of the memory map controller is not just to detect when the address is in the memory mapped I/O range, but to generally indicate what memory device should be active for any given address, including the RAM and ROM.

The design I ultimately went with generate a number of control signals to activate various memory mapped components. The most prominent one are `ROMe`, indicating the the memory address pertains to the ROM, and `RAMe`, which indicates RAM should be active. For the memory mapped I/O range, I spit the memory addresses up into several smaller segments, and have a control signal for each of those segments. Altogether, the `0x7800` to `0x7FFF` range is split up into 16 different segments. Eight of the segments, `MMAP_0` through `MMAP_7`, are each 16 bytes in size. Another seven segments,`MMAP_8` to `MMAP_14`, are 128 bytes in size. And the final segment, `MMAP_15`, is 1024 bytes in size. The size of a segment indicates how many distinct address values are available when that segment is active. These addresses are always contiguous. For the 16-byte segments, the various address values are indicated by address lines A0 through A3.

The segment activation is enabled by two cascaded 74HCT238 demultiplexers wired up to address lines A4 through A10. Address line A11 controls whether the 74HCT238 are active or not. When A11 is low and the address value in the memory map I/O range, the 74HCT238 are active and emitting one MMAP control line. When A11 is high and the address value in the memory map I/O range, then the 1024 byte memory map segment is active.

When a given memory map control line is active, then the component associated in that line should respond to the `MDo` and `MDi` control lines as appropriate for that component. The component may use the address lines to further differentiate the data interaction or action taken.

I also added support for a 17th address line A16. This address line is fed into the A15 address line of the `UM61512A` RAM IC. The memory map controller with activate `RAMe` when A16 is high and A15 is low or with A16 is low and A15 is high, thus enabling the potential to access the full 64K of RAM in the `UM61512A` RAM IC. For now, the A16 address line is tied low and otherwise unused, as this wiring was done to enable a future project. 

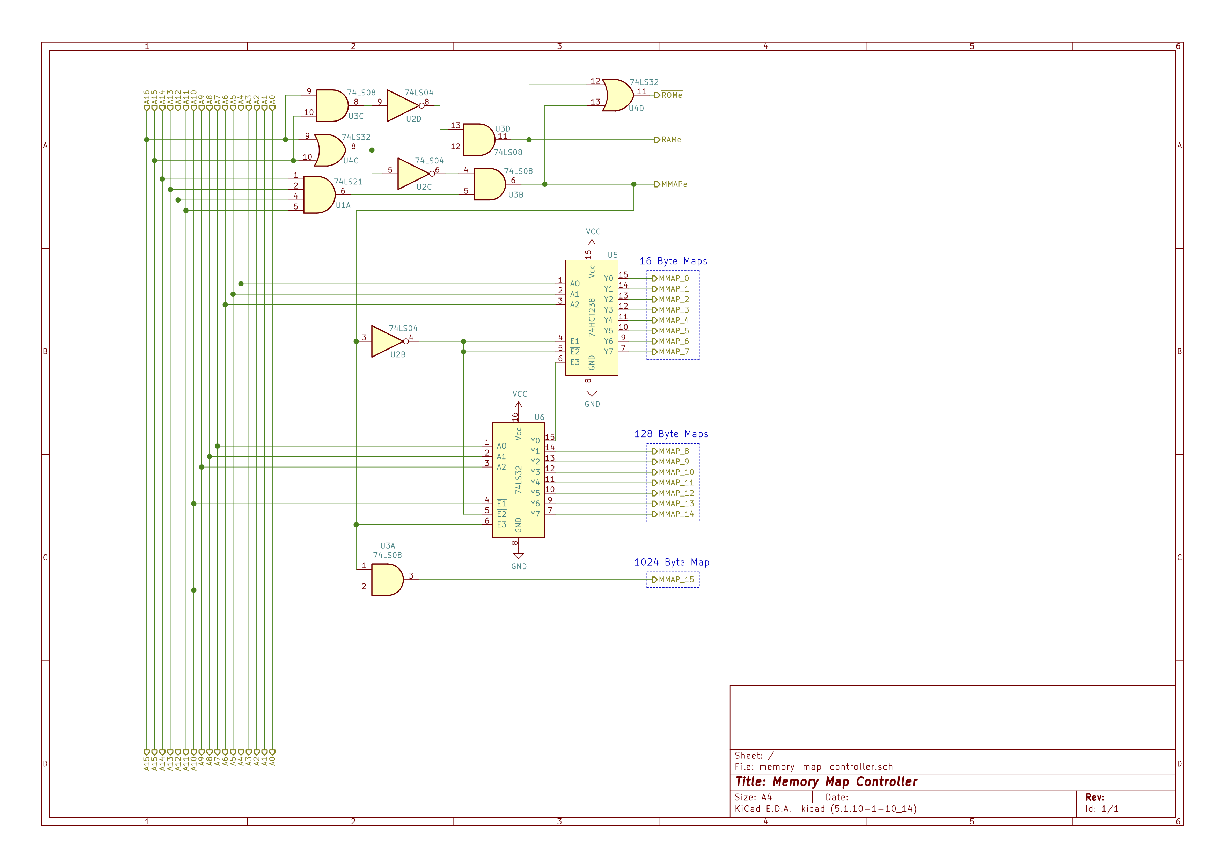
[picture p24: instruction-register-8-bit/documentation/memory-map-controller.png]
Memory Map Controller


#### Run Mode Selector
In my prior 16-bit memory project, I updated the run mode selector to be able to use 16 bits of microswitches to be able to set the address on the address bus when the CPU is in programming mode. In this project nothing much changed with that, except I did add address line A16 to the design as described above. Here, the A16 line is simply pulled down with a 1K resistor to ground and carries no other signal. 

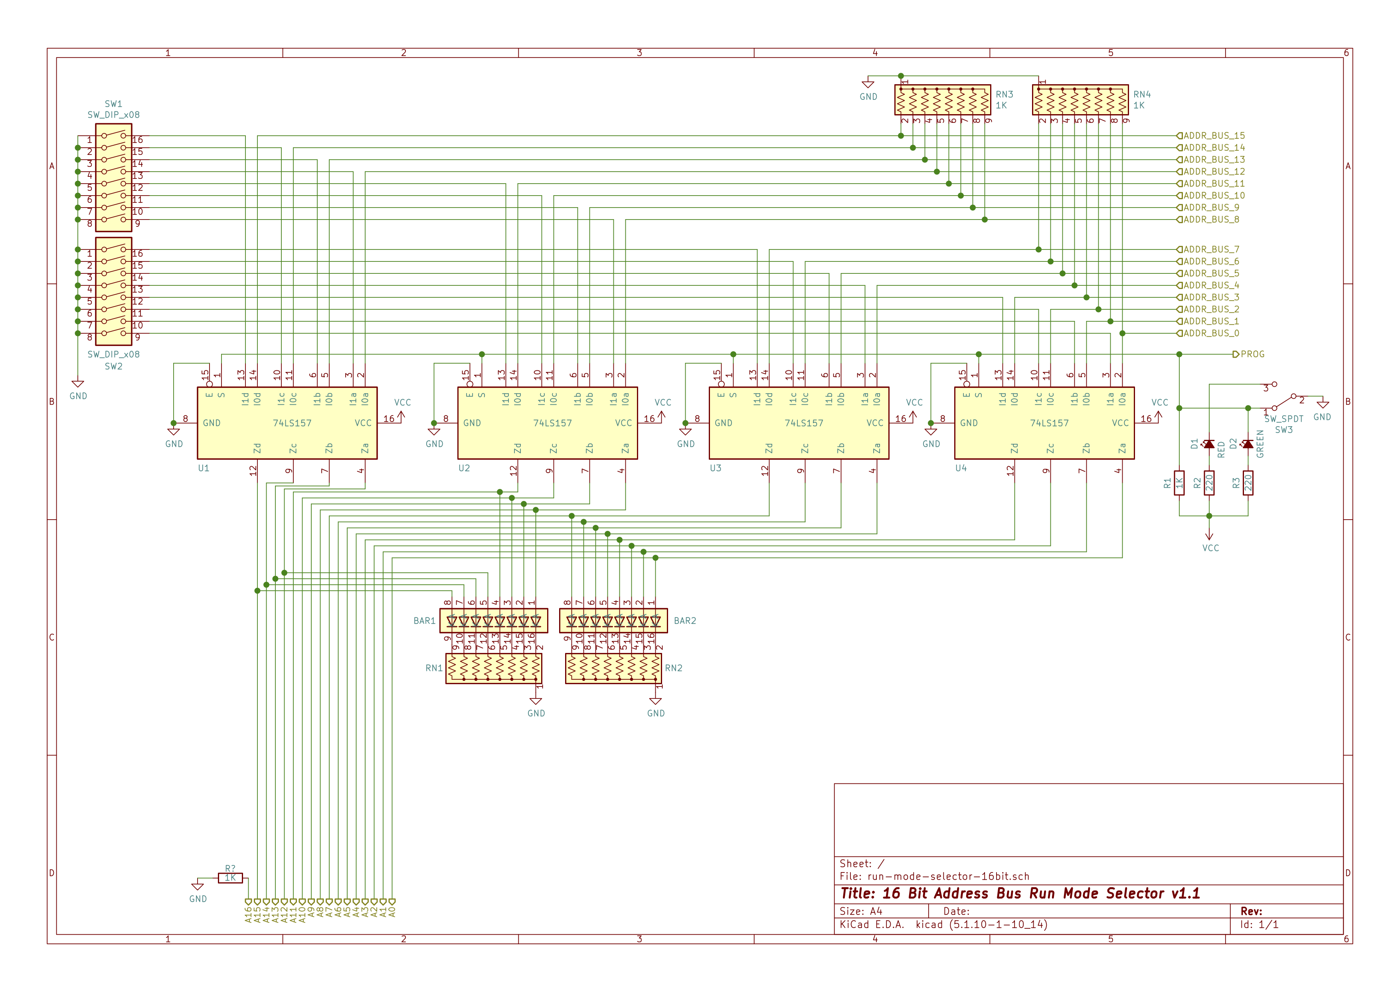
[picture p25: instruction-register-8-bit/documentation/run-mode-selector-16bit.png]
Run Mode Selector


#### Converting Display Register to Memory Mapped Device
In this project, I will get rid of the `OUT` control line. Instead, I will use a memory map control line to manage the original Eater SAP display register. I will assign the display register to `MMAP_0` memory map segment, and so the display register should read in the data bus value when the `MMAP_0` segment line and the `MDi` control line are both high. This would require the addition of an AND gate to the display register to detect when these control signals are both high.

The `MMAP_0` segment pertains to addresses `0x7800` through `0x780F`. Since the implementation described above doesn't inspect the activated address lines, writing data to any address in that range will cause that data to be written to the display register. So once the display register set up as indicated here, to set the display register to a certain value, the following assembly code that uses the instruction set described above can be used:
```
OUTPUT = $7800
mov [OUTPUT], a
```
This instruction will take the current value in the register `A` and write it to the display register.

## Microcode
In order to generate the microcode image for the `27C4096` EEPROMs, I created a new microcode generation program (click here) that accounts for the new layout of this design. I also change the format of the configuration file slightly, notably changing the instruction steps configuration to be a dictionary where the key is the step number and the value is a list of step configuration options based on varying flags. This was done primarily to improve the clarity as the configuration file gets larger, but also make things easier when dealing with extended instructions which skip a step that is actually handled by the `XTD` byte.

The "Beta 1" microcode configuration for this project is available [here](./microcode/). I have also visualized the microcode in [a spreadsheet here](https://docs.google.com/spreadsheets/d/1dE303KofFNmr9R2AhJyg4c5JZepmx5lBA1MQLOz1rY8/edit?usp=sharing). 

## Assembly Code
The sister project to this breadboard CPU is my customizable assembler, [BespokeASM](https://github.com/michaelkamprath/bespokeasm). I have updated the assembler to support the [addressing modes](https://github.com/michaelkamprath/bespokeasm/wiki/Assembly-Language-Syntax#addressing-modes) and [instruction configuration](https://github.com/michaelkamprath/bespokeasm/wiki/Instruction-Set-Configuration-File#machine-code-compilation) required by this change to my breadboard CPU's instruction set, plus generally improved it's functionality. BespokeASM requires a configuration file to generate machine code for any particular instruction set. The configuration file for this project's build can be found [here](./assembly/).

To compile assembly code in a file name `my_code.asm` for this CPU using BespokeASM, the following command is used:
```
bespokeasm compile -e 32767 -c /path/to/putey-beta1-bespokeasm-config.yaml my_code.asm
```

This will generate a binary image file named `my_code.bin` that can be burned to the `28C256` ROM used for this computer. Note that the `-e` option indicates the ending address of the binary image, and Bespoke ASM will pad the image with 0's if the compiled code does not fill all addresses. The `--pretty-print` option can be added if a human readable output is additionally desired.

Examples of assembly programs that can be run on this version of the breadboard CPU can be found [here](./examples/).

## Project Notes
### Data Sheets
The key ICs used in this project are:

* [`AT27C4096`](./datasheets/AT27C4096.pdf) - The 256K x 16 bit EPROM used for the microcode in this build. Note that the [`M27C4002`](./datasheets/M27C4002.pdf) is an equivalent chip from a different manufacturer and can be used instead of the  `AT27C4096`.
* [`UM61512A`](./datasheets/UM61512A.pdf) - 64K x 8 bit static RAM used for the system RAM.
* [`AT28C256`](./datasheets/AT28C256.pdf) - 32K x 8 bit EEPROM used for the system ROM in the memory module.
* [`74LS257`](./datasheets/sn74ls257b.pdf) - Quadruple 2-to-1 line data selector with 3-state output.
* [`74HCT238`](./datasheets/cd74hct238.pdf) - 3-to-8 line decoder with active high output.
* [`74LS74`](./datasheets/sn74ls74a.pdf) - Duel D-type positive edge triggered flip-flops.

There are other, more common ICs used too, but the above are the key new chips in this project.

### Building Tips
#### Upgrading from Previous Project
When I constructed this project. I had already accomplished my previous [16-bit memory] and [extended control lines] projects. While they were certainly steps forward, they were not the right steps forward for when I want to go with this TTL CPU. As already indicated, this project replaces them, though it keeps the memory address register, program counter, and run mode selector from the 16-bit memory project. The rest of things had to be removed.

I found it to be easier to simply remove all of the control lines, regardless of whether they go to a component that is staying in place. However, when doing so, I tagged each destination with the control line name so that it would be easier to know where each control line goes later.

#### Chip Consolidation
Many of the modules in this design use logic gate chips but not all the gates in each cheap. With careful preplanning, you can reduce chip usage by sharing the same logic gate chips amongst modules. Most notable targets are the `74LS04` inverters, `74LS08` AND gates, and the `74LS32` OR gates.

#### Inductance, Capacitance, and Noise, oh my!
When I first put this project together, I decided to example the number of breadboard power rails I used alongside the data bus for the transmission of signals. I added two more rails for an addition of 4 additional lines, and wired things to carry the clock, system reset, `MDo`, and `MDi`. When I was convinced I was done with my wiring, I powered things on and the CPU did not work. After much debugging with an oscilloscope, I found that my clock signal was pretty dirty, and assumed the capacitance of the breadboard power rails was at fault. Specially, I thought it was cross talk from the data bus lines, which were right next to the clock line.  So I rerouted the clock signal to not use the power rail next to the data bus, and that did not fix my problems. 

It turned out the dirty clock signal was a symptom of another more fundamental problem: power distribution for my now much larger breadboard layout was problematic. This was caused by a combination of things:

* With the larger layout, power distribution became much more noisy and uneven. A HIGH signal emanating from one side of the board wasn't high enough on the other. Probably more problematic was that the ground rail on the bottom left was up to 0.5 volts different than the ground rail on the bottom right. This created the biggest problem with the CLR signal which was emanating from my board's lower left. Since the power distribution was additionally noisy, was was supposed to be a constant LOW CLR signal sometimes looked like it had a rising edge to the 74LS173 registers on the right side of the board. This would cause the 74LS173 registers to clear the contents. I found the best way to address this is to do a better job of connecting grounds across the board so that the ground reference was consistent through out the board. I created a power distribution with continuous wires around the outside of the breadboards, and connected the grounds of various boards across the interior data bus to ensure a consistent ground reference. Also to deal with the noise, I more properly added decoupling capacitors to each IC such that the capacitor was directly connected to the power and ground pin of the IC. 
* I had the LED bars hanging off the 74LS173 registers with 100 ohm current limiting resistors. I believe that this was over stressing the 74LS173 by causing more current than the 74LS173 can support when the LEDs were on. In cases where most of the 74LS173 outputs were high, the outputs would sometimes go into what I can on describe as a vibration with the output value toggling between HIGH and LOW at a very high frequency. The solution here was to use 1K ohm current limiting resistors for LEDs attached to the 74LS173 outputs.
* I originally was using a 1K pull down resistor for the data bus. With more things attached to the data bus, it became increasingly difficult for the 74LS logic to assert a HIGH on the data bus. This is because 74LS logic cannot provide a large amount of current for HIGH, as they are designed to provide more current when asserting a LOW. So, I changed the data bus pull down resistors to 3.3K ohm pull up resistors

Once I addressed these issues, my breadboard CPU worked as expected.

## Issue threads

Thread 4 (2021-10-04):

Are pins 13 & 14 reversed on the counting register 74LS173?

MarkMaxMayne, 2021-10-04:
Is it that the ICF and IZF input pins are reversed on the 74LS173?  It appears zero is driving ICF and carry is driving IZF in this diagram, no?  You could flip either pins 3&4 or pins 13&14, but flipping 13&14 would make the diagram look better.

Best,
-Mark

michaelkamprath, 2021-10-04:
Huh, yeah, you are right my schematic does reverse the output flags. I can say that my actual hardware implementation has this correct!  I'll fix the schematic in the repository.

Closed 2021-10-04.

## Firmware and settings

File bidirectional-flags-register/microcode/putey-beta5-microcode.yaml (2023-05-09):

---
microcode_file_name: putey-beta5-microcode.bin
control_lines:
  HILO: 1
  PCa: 2
  ARa: 3
  SPa: 4
  HLa: 5
  AOa: 6
  Fi: 7
  AOi: 8
  PCi: 9
  IRi: 10
  MDi: 11
  Ai: 12
  Ti: 13
  HLi: 14
  Ii: 15
  Ji: 16
  ARi: 17
  PCe: 18
  ARe: 19
  SPe: 20
  Ie: 21
  Je: 22
  HLe: 23
  SUB: 25
  CRY: 26
  S0: 27
  S1: 28
  S2: 29
  S3: 30
  AP1: 33
  ABo: 34
  MDo: 35
  Ao: 36
  To: 37
  Fo: 38
  Io: 39
  Jo: 40
  SUMo: 41
  SCr: 42
  SPr: 43
  DSs: 44
  CMPs: 45
  XTD: 47
  HLT: 48
flags:
  - zero
  - carry
  - equal
  - overflow
  - extended
instruction_prefix_steps:
  0:
    - flags:
        extended: 0
      control_lines:
        IRi
        PCa
        MDo
        PCe
instructions:
  NOP:
    value: 0
    steps:
      1:
        - control_lines:
            SCr
  HLT:
    value: 1
    steps:
      1:
        - control_lines:
            HLT
  XTD_INSTR:
    value: 0xFF
    steps:
      0:
        - flags:
            extended: 1
          control_lines:
            IRi
            PCa
            MDo
            PCe
      1:
        - flags:
            extended: 0
          control_lines:
            XTD
        - flags:
            extended: 1
          control_lines:
            XTD
  #
  # Jump & Conditional Jump
  #
  JMP_iaddr:
    value: 78
    steps:
      1:
        - control_lines:
            PCa
            ARi
            PCe
            MDo
      2:
        - control_lines:
            HILO
            PCa
            ARi
            MDo
      3:
        - control_lines:
            ARa
            PCi
            ARe
            MDo
      4:
        - control_lines:
            HILO
            ARa
            PCi
            MDo
      5:
        - control_lines:
            SCr
  JMP_addr:
    value: 79
    steps:
      1:
        - control_lines:
            PCa
            Ti
            PCe
            MDo
      2:
        - control_lines:
            HILO
            PCa
            PCi
            MDo
      3:
        - control_lines:
            PCi
            To
      4:
        - control_lines:
            SCr
  JC_iaddr:
    value: 50
    steps:
      1:
        - flags:
            carry: 0
          control_lines:
            PCe
        - flags:
            carry: 1
          control_lines:
            PCa
            ARi
            PCe
            MDo
      2:
        - flags:
            carry: 0
          control_lines:
            PCe
        - flags:
            carry: 1
          control_lines:
            HILO
            PCa
            ARi
            MDo
      3:
        - flags:
            carry: 0
          control_lines:
            SCr
        - flags:
            carry: 1
          control_lines:
            ARa
            PCi
            ARe
            MDo
      4:
        - flags:
            carry: 1
          control_lines:
            HILO
            ARa
            PCi
            MDo
      5:
        - flags:
            carry: 1
          control_lines:
            SCr
  JC_addr:
    value: 51
    steps:
      1:
        - flags:
            carry: 0
          control_lines:
            PCe
        - flags:
            carry: 1
          control_lines:
            PCa
            Ti
            PCe
            MDo
      2:
        - flags:
            carry: 0
          control_lines:
            PCe
        - flags:
            carry: 1
          control_lines:
            HILO
            PCa
            PCi
            MDo
      3:
        - flags:
            carry: 0
          control_lines:
            SCr
        - flags:
            carry: 1
          control_lines:
            PCi
            To
      4:
        - flags:
            carry: 1
          control_lines:
            SCr
  JZ_iaddr:
    value: 54
    steps:
      1:
        - flags:
            zero: 0
          control_lines:
            PCe
        - flags:
            zero: 1
          control_lines:
            PCa
            ARi
            PCe
            MDo
      2:
        - flags:
            zero: 0
          control_lines:
            PCe
        - flags:
            zero: 1
          control_lines:
            HILO
            PCa
            ARi
            MDo
      3:
        - flags:
            zero: 0
          control_lines:
            SCr
        - flags:
            zero: 1
          control_lines:
            ARa
            PCi
            ARe
            MDo
      4:
        - flags:
            zero: 1
          control_lines:
            HILO
            ARa
            PCi
            MDo
      5:
        - flags:
            zero: 1
          control_lines:
            SCr
  JZ_addr:
    value: 55
    steps:
      1:
        - flags:
            zero: 0
          control_lines:
            PCe
        - flags:
            zero: 1
          control_lines:
            PCa
            Ti
            PCe
            MDo
      2:
        - flags:
            zero: 0
          control_lines:
            PCe
        - flags:
            zero: 1
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

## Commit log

2020-12-19 added clock halt when programming project
    [clock-module-with-prog-halt.sch]
2020-12-22 expanded control logic hardware design
    [control-logic.kicad_pcb, control-logic.sch]
2020-12-23 fixed werror where Y0 on 74HCT238 cannot be used for control lines
    [control-logic.sch]
2020-12-25 addressed some design bugs
    [control-logic.sch]
2020-12-26 improve documentation
    [control-logic.sch]
2020-12-26 added ram reliability project
    [ram-module.sch]
2021-01-03 restructuring the directory
    [clock-module-with-prog-halt.sch]
2021-01-10 work in progress for counting registers
    [alu.sch, counting-register.kicad_pcb, counting-register.sch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]
2021-01-10 improvements to counting register documentation
    [counting-register.sch]
2021-01-13 updated documentation
    [flags-register.sch]
2021-02-28 formatting changes
    [flags-register.sch]
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2021-05-31 64K RAM/ROM Upgrade (#3)
    * first draft of RAM/ROM module
    * first draft of complete design
    * start of README
    * added pull down resistors
    * added transceiver from address to data bus
    * updated README
    * fixed bus contention issue
    * further fixed bus contention issue
    * corrected yet another bus contention
    The 74LS157 that select the data bus or switches for the RAM in value were switch to 74LS257 models so that the output is high Z when the chip is not enabled.
    * minor modifications
    * added an updated clock module
    * updating documentation
    * minor tweaks
    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
    [address-bus-to-data-bus.kicad_pcb, address-bus-to-data-bus.sch, address-register-16bit.kicad_pcb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]
2021-06-18 instruction register and control logic schematics
    [control-logic.kicad_pcb, control-logic.sch, instruction-register-step-counter.kicad_pcb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]
2021-06-26 small corrections to design
    [control-logic.sch, instruction-register-step-counter.sch]
2021-07-04 updated register design to enable extended instructions
    [control-logic.sch, instruction-register-step-counter.sch]
2021-07-11 candidate final schematic designs
    Also started to consolidate custom symbols from all projects
    [address-register-16bit.sch, clock-module-v2.sch, control-logic.sch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]
2021-07-11 removed A16 address line
    [control-logic.sch, instruction-register-step-counter.sch, memory-map-controller.sch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]
2021-07-25 seperated RAM and ROM modules
    In order to simplify each, the RAM and ROM modules are seperated and no longer share a common connection to the data bus. Also added support for addres line A16, though it is tied to ground and outherwise unused in this design
    [memory-map-controller.sch, ram-module.kicad_pcb, ram-module.sch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]
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2021-07-28 updated based on build layout
    [ram-module.sch]
2021-08-01 adjustments based on construction layout
    [memory-map-controller.sch]
2021-08-08 tweaks and fixes
    [instruction-register-step-counter.sch, memory-map-controller.sch]
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2021-08-28 removed unnecessary RC circuit on clock line
    [ram-module.sch]
2021-08-28 fixed hardware bug with the XTD flip flop
    [instruction-register-step-counter.sch]
2021-10-02 start of stack pointer work
    [address-offset-register.kicad_pcb, address-offset-register.sch, stack-pointer.kicad_pcb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]
2021-10-03 more work on stack pointer
    [address-offset-register.sch, program-counter-16bit.kicad_pcb, program-counter-16bit.sch]
2021-10-04 correct flag pin assignment. closes #4
    [counting-register.sch]
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2021-10-06 updated address bus handling and added support for halt on error
    [address-offset-register.sch, clock-module-with-error-halt.kicad_pcb, clock-module-with-error-halt.sch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]
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2021-10-07 further work on microcode
    [program-counter-16bit.sch]
2021-10-19 fixed some error in assembler config
2021-10-23 added index register
    Also fixed hardware design bugs and updated readme.
    [index-register.kicad_pcb, index-register.sch, stack-pointer.sch]
2021-11-03 small iteration on schematics
    [address-offset-register.sch, clock-module-with-error-halt.sch]
2021-11-19 updated pull down resistor value
    [address-offset-register.sch]
2021-11-21 updated index register symbol
    [clock-module-with-error-halt.sch, index-register.sch]
2021-11-23 correct bugs in beta-2 assembly configuration
2021-11-24 removed ineffectual CLR line to stack pointer
    [stack-pointer.sch]
2021-11-24 finalized index register design
    [index-register.sch]
2021-11-25 removed stack pointer and index register error flags
    [clock-module-with-error-halt.sch, index-register.sch, stack-pointer.sch]
2021-12-16 added schematics to documentation
    [address-offset-register.sch, clock-module-with-error-halt.sch, index-register.sch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]
2021-12-27 test version of LCD display module
    [lcd-display.kicad_pcb, lcd-display.sch]
2021-12-28 first working version of LCD module
    [lcd-display.sch]
2022-01-01 improved handling of timming differences between clock and mmap
    The MMAP_1 signal is noticablylater than the clock due to all the gates it has to go through in the memory map mananger. This caused issues with the trailing edge enable fo the LCD2004 module in that the inverted clock would go high moments before the MMAP_1 signal would go low. This in turn caused a spurious trailing edge event into the Enable input of the LCD2004 module, causing weirdness with the cursor.
    [lcd-display.sch]
2022-01-01 address stability issues caused by inductance
    [lcd-display.sch]
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2022-01-07 updated LCD module schematic
    [lcd-display.sch]
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2022-01-15 upgrade to kicad v6
    [index-register.kicad_sch, lcd-display.kicad_sch, stack-pointer.kicad_sch]
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2022-01-22 started work on advanced ALU
    [a-register.kicad_sch, advanced-alu.kicad_pcb, advanced-alu.kicad_sch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]
2022-01-23 first complete draft for advanced ALU
    [advanced-alu.kicad_sch]
2022-01-23 corrected issues
    [advanced-alu.kicad_sch]
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2022-01-31 enabled a compare to zero operation
    [advanced-alu.kicad_sch]
2022-02-04 adjust CLK signal timing
    [lcd-display.kicad_sch]
2022-02-21 addressed several stability issues
    [clock-module-with-error-halt.kicad_sch, lcd-display.kicad_sch]
2022-02-21 upgrade to KiCad 6
    [memory-map-controller.kicad_sch]
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2022-04-06 updated I and J registers and step counter logic
    [comparison-test-unit.kicad_sch, instruction-register-step-counter.kicad_pcb, instruction-register-step-counter.kicad_sch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]
2022-04-06 restored Ai control line
    [advanced-alu.kicad_sch]
2022-04-09 fixed STD and step counter resent logic
    [instruction-register-step-counter.kicad_sch]
2022-04-09 fixed label notation
    [revised-increment-registers.kicad_sch]
2022-04-09 changed how XTD works
    [instruction-register-step-counter.kicad_sch]
2022-04-09 added first dev build of microcode
    [control-logic.kicad_pcb, control-logic.kicad_sch]
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2022-04-19 returned temp registr to being 8-bit
    [a-register.kicad_sch, advanced-alu.kicad_sch, arithmetic-logic-unit.kicad_sch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]
2022-04-23 tweaked design and updated documentation
    [advanced-alu.kicad_sch, arithmetic-logic-unit.kicad_sch, comparison-test-unit.kicad_sch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]
2022-04-24 small changes toimprove layout
    [a-register.kicad_sch, advanced-alu.kicad_sch, arithmetic-logic-unit.kicad_sch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]
2022-04-25 updated design to properly handle subtractions
    Also added ability to do an arithmetic right shift.
    [a-register.kicad_sch, advanced-alu.kicad_sch]
2022-04-29 improvements to how carry is handled
    [a-register.kicad_sch, advanced-alu.kicad_sch, arithmetic-logic-unit.kicad_sch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]
2022-04-29 tweaks and layout improvements
    [a-register.kicad_sch, advanced-alu.kicad_sch, arithmetic-logic-unit.kicad_sch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]
2022-04-30 corrected control lines
    [advanced-alu.kicad_sch, comparison-test-unit.kicad_sch, flags-register.kicad_sch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]
2022-05-01 fixed bit shifting hardware bug
    [a-register.kicad_sch, advanced-alu.kicad_sch, comparison-test-unit.kicad_sch]
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2022-05-04 fixed errors in microcode
    [putey-beta4-microcode.yaml]
2022-05-09 fixed bug in microcode generation
    [putey-beta4-microcode.yaml]
2022-05-13 fixed timing error in microcode
    [putey-beta4-microcode.yaml]
2022-05-16 Advanced ALU (#5)
    This PR covers all the major changes to the TTL CPU to enable an advanced ALU, plus simplifying changes to the I and J registers.
    [a-register.kicad_sch, advanced-alu.kicad_pcb, advanced-alu.kicad_sch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]
2022-05-28 added updated memory map controller
    [memory-map-controller.kicad_pcb, memory-map-controller.kicad_sch]
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2023-05-09 Bidirectional flags register (#6)
    Added ability to write to the Flags register.
    [flags-register.kicad_pcb, flags-register.kicad_sch]
